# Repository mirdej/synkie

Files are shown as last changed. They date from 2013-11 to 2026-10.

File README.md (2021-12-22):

The Synkie is a modular open source analog video processor, developed by Michael Egger, Max Egger and Flo Kaufmann. A bit like the venerable modular Moog synthesizer it lets you toy around with the signal using patch cables – but this time not producing sound but images. It is an instrument for video, a playground, a platform to explore new ways to transform a video signal. Synkie is still in development, we constantly develop new modules – and even the base specifications may still change over time. 

Synkie’s main goal is playability not image quality, even though we try to design each module as best as we can. But patching is done with 2mm laboratory cables – not shielded 75Ohm BNC cables as one would normally use for video. No, you can even use any blank wire and tinker around with the signal in real time on the sk90-breadboard module… The laboratory plugs can be stacked, so you can easily divide the signal into multiple paths, feeding multiple modules at once and change the configuration on the fly. The resulting image can get quite messy down the road, but that’s part of the fun, or maybe even the main purpose…

# Before building stuff from here yourself - read this:

This Github repository is our working space and not a DIY tutorial. Lots of stuff is completely outdated and/or poorly documented. Here are some important notes about the current state of things (Oct 2021):

- Pretty much everything in the EAGLE directory is totally obsolete and we only keep it for documentation.

- We settled on the LMH6643 as our Opamp of choice for almost everything where frequency response matters. Not all schematics reflect this. In most cases if there's an opamp named "generic opamp" or even "LM833" - we probably meant LMH6643.

- There are several modules where the supply connector is flipped. As we etch a lot of boards ourselves there is no silkscreen and we don't see the error. ALWAYS check the polarity !

- We live in PAL land. These modules have not beent tested with NTSC video. Some might need to be adapted slightly, some might even work better than here ;-)

If you have any questions contact <info@synkie.net>

# Basics

## Synkie Backbone
Modules sk000 to sk009 constitute the Synkie Backbone – handling Ins out Outs to the normal Video World. Input video is clamped (black level = GND) and stripped of timing signals and color burst. This signal can then be fed to any processing modules.
In the end , timing signals and a phase corrected color burst is cut back into the modified signal, in sync with the Genlock input.

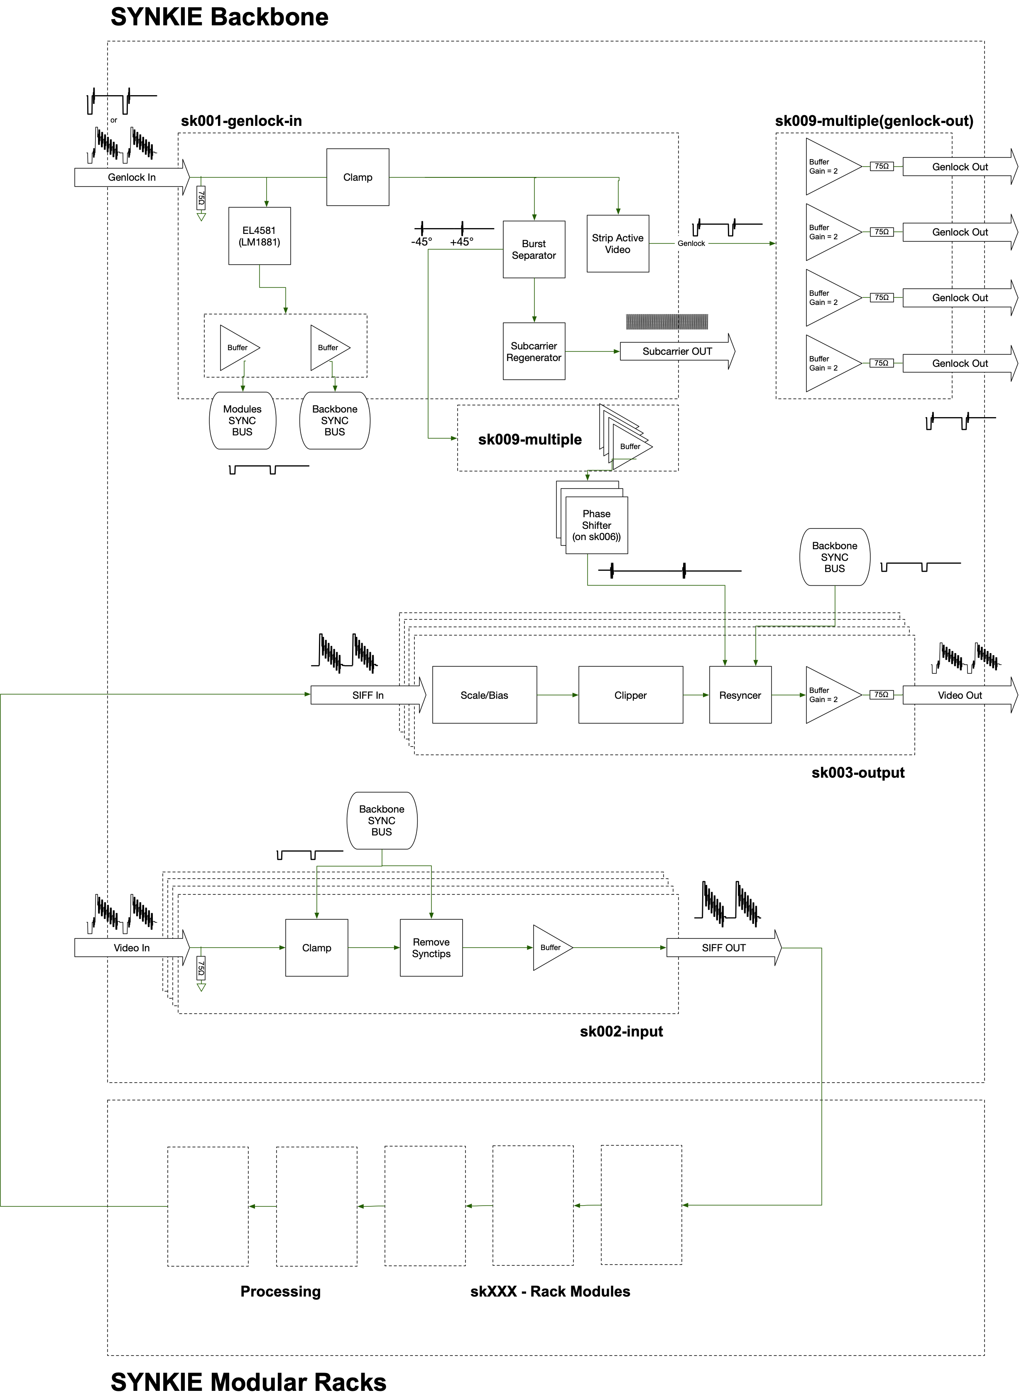
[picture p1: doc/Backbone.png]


### sk000-power
Power distribution to backbone modules and rack. +5V, GND, -5V.

### sk001-genlock-in

This module takes any standard video signal as input and generates all necessary timing signals for the Synkie system. The input is first backporch-clamped to GND and all active video is cut off. This black image can serve as a genlock for connected sources (cameras). Colorburst is output as a seperate signal and used to syncronise a quartz crystal that generates a continuous 4.4336Mhz subcarrier signal for the rgb modules. A LM1881 generates the digital sync signals: horizontal sync, vertical sync, backporch and odd/even.

### sk002-input

This modules takes any standard video signal, clamps black level to GND and strips off synctips and colorburst. (still in active debate: me thinks sk002 should apply a gain of 1.43 to bring the 0.7V white level up to 1V)

### sk003-output

This module takes any signal as its input (from DC to 10Mhz). The scale-bias section controls amplitude and dc-shift. The signal is then clipped hard between 0V and 1V. Finally the resyncer adds synctips and colorburst to make it look like a standard video signal. 
When using video as an input to the sk003 any processing beforehand can add some tiny delay - depending on how many modules the signal passes through -  which causes a phase shift in the signal that can alter or completely destroy color. That is why the burst signal from sk001 first goes through a sk004-burstshift (allpass filter) that lets correct the phase error before it gets cut back into the video signal.

## Synkie Signals

### Terminology
| Signal name | Waveform| Description  |Specs|
|---|---|---|---|
|Genlock||A video signal that serves as the master synchronisation signal. Can be routed through and used as an input.|-0.3V to 0.7V|
|Video||Standard PAL video signal|-0.3V to 0.7V|
|Sync| |Digital sync pulses: H-Sync, V-Sync, Backporch, Odd/Even|0V to 5V|
|Burst|| Colorburst only, AC coupled|ca. -0.1V to 0.1V|
|Siff| |Synkie signal. Can be anything, DC, CV, Audio or Video. 0V means black. 1V means white|-1V to 1V|

### The SIFF signal
Synkie's goal is to be able to mix all signals, be it control signals, audio or picture. You should be able to use a video image as control voltage for a VCO like you should be able to inject a sound into the video or watch a steady 0.256 volts.

* Siff signals are DC coupled. 0V means black. 1V means white.
* Siff signals can still be negative, meaning superblack or substracting signals !
* Siff signals can be loud - going beyond 1V and below -1V. The sk003-output module will finally limit the signal to 0-1V.
* Siff signals can range from DC (0Hz) to ca. 10Mhz

This has the following implications for synkie modules:

* All module inputs should be high-impedance, DC coupled and ESR protected.
* All module outputs should be low-impedance and DC coupled.
* Whenever possible a module's bandwidth should be at least 4Mhz
* Sensible CV range should be between 0V and 1V.
* But: Modules must be able to cope with voltages as low as -5V to as high as 5V
* Gate signals are 0V to 1V !!
* So: trigger inputs should trigger at around 0.5V ! Use comparators.

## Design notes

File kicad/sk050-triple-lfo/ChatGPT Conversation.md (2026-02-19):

From the schematic, R5 + RV1 feed an inverting integrator (U1B) with C4, and U1A acts as the Schmitt trigger. For this topology the oscillation frequency is well-approximated by:

[
f \approx \frac{R3}{4,R4,(R5+RV),C4}
]

With your shown values R3 = 100k and R4 = 10k, that simplifies to:

[
f \approx \frac{2.5}{(R5+RV),C4}
]

Assuming RV1 is used as a rheostat (wiper tied to an end, as drawn), with RV = 0…100kΩ:

[
f_{\max} \approx \frac{2.5}{R5,C4}
]
[
f_{\min} \approx \frac{2.5}{(R5+100k),C4}
]
Frequency ranges for common R5/C4 choices
R5 (Ω)	C4	f_max (Hz) @ RV=0	f_min (Hz) @ RV=100k
4.7k	100 nF	5,319	239
10k	100 nF	2,500	227
22k	100 nF	1,136	192
47k	100 nF	532	170
4.7k	1 µF	532	23.9
10k	1 µF	250	22.7
22k	1 µF	114	19.2
47k	1 µF	53.2	17.0
4.7k	10 µF	53.2	2.39
10k	10 µF	25.0	2.27
22k	10 µF	11.4	1.92
47k	47 µF	1.13	0.362
100k	47 µF	0.532	0.266
47k	100 µF	0.532	0.170
If you want, say, a “typical LFO” band (e.g. ~0.05–20 Hz) tell me that target range and I’ll suggest a small set of R5/C4 combos that land there cleanly with the 0–100k pot.

------------------------------------------------------------------------------------------------------

For your exact schematic (U1A Schmitt + U1B integrator), with R3 = 100k and R4 = 10k, the oscillation frequency is approximately:

[
f \approx \frac{2.5}{(R5+RV),C4}
]

with RV = 0…100kΩ (wired as a rheostat). So:

(f_{\max} \approx \dfrac{2.5}{R5,C4})
(f_{\min} \approx \dfrac{2.5}{(R5+100k),C4})
Below are common-value combinations that target your two “interesting” overall bands. Since one 0–100k pot only gives about a (R5+100k)/R5 span, hitting 0.05→20 Hz and 0.1→100 Hz realistically means switching C4 (and/or R5).

Set A (recommended): keep R5 = 22k, switch C4 to cover ~0.09 Hz → 114 Hz overall
This is a nice “do-most-things” choice.

R5	C4	f_max (Hz) @ RV=0	f_min (Hz) @ RV=100k
22k	1 µF	113.6	20.5
22k	2.2 µF	51.6	9.32
22k	4.7 µF	24.2	4.36
22k	10 µF	11.36	2.05
22k	22 µF	5.16	0.931
22k	47 µF	2.42	0.436
22k	100 µF	1.136	0.205
22k	220 µF	0.516	0.093
What this gives you:

For ~0.1–100 Hz overall: C4 from 1 µF down to 220 µF covers it (with overlaps).
For ~0.05–20 Hz overall: you’ll use mostly 4.7 µF … 470 µF (next table includes 470 µF).
Add one more common value if you want to reach ~0.05 Hz comfortably:

R5	C4	f_max (Hz) @ RV=0	f_min (Hz) @ RV=100k
22k	470 µF	0.242	0.0436
Set B (more “LFO-biased”): keep R5 = 47k, switch C4 for lower frequencies
This shifts everything slower (often useful if you mainly care about sub-Hz).

R5	C4	f_max (Hz) @ RV=0	f_min (Hz) @ RV=100k
47k	2.2 µF	24.2	7.74
47k	4.7 µF	11.31	3.62
47k	10 µF	5.32	1.70
47k	22 µF	2.42	0.774
47k	47 µF	1.13	0.362
47k	100 µF	0.532	0.170
47k	220 µF	0.242	0.0774
47k	470 µF	0.113	0.0362
Practical notes (affects “how true” the low end is)
Electrolytics (100–470 µF) have wide tolerance + leakage → the very lowest frequencies can drift.
Op-amp input bias/leakage and capacitor leakage matter a lot below ~0.1 Hz.

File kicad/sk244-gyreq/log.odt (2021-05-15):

Main amp R 10k

# Mid

10n ; 1n / 100 / 100k

min:

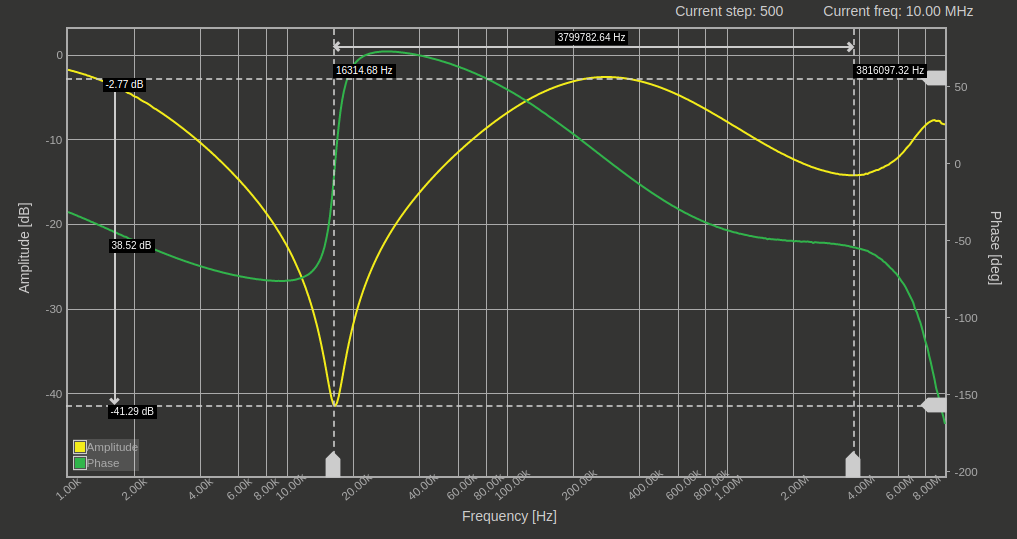
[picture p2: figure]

zero:

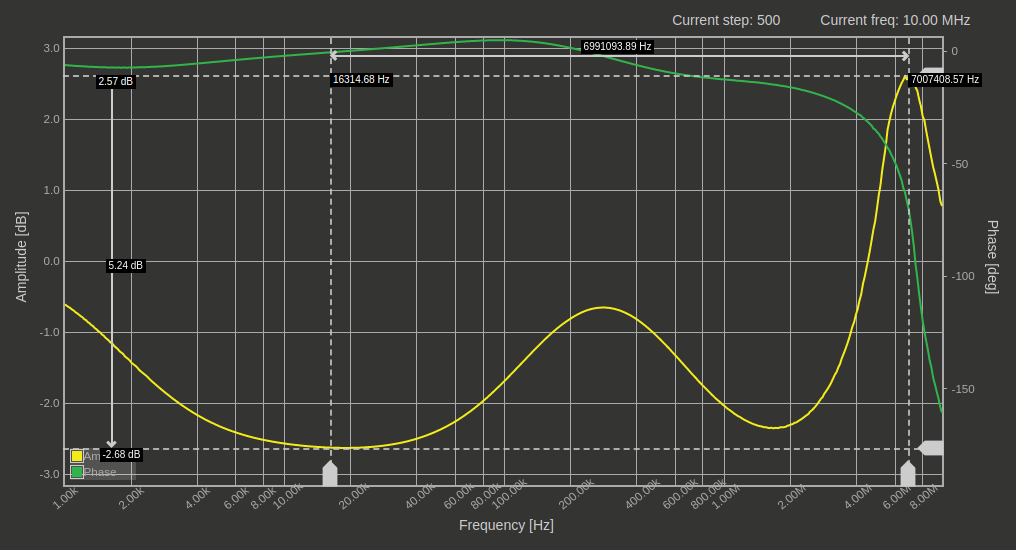
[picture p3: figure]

max:

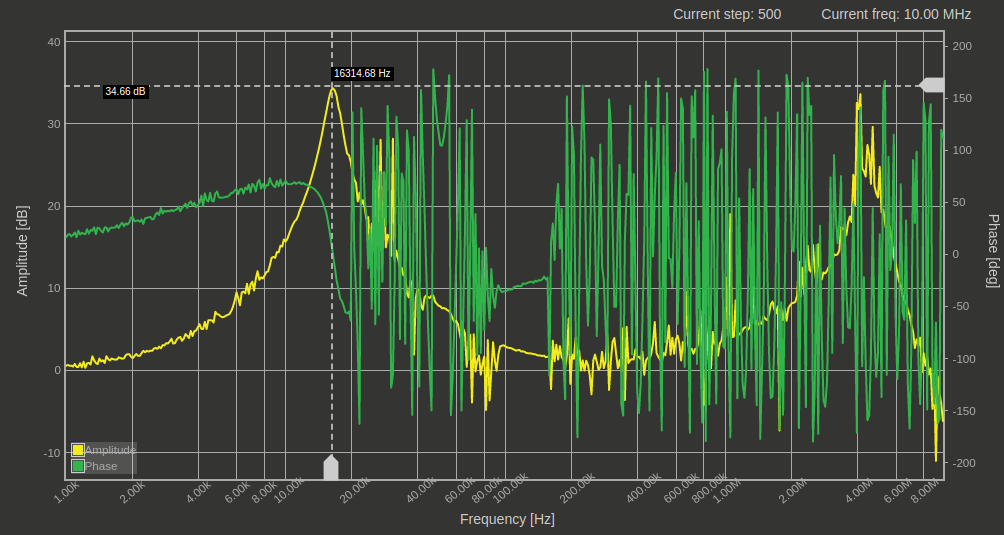
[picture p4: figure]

# Hi (Mid zero)

22p ; 47p / 75 / 16k

min:

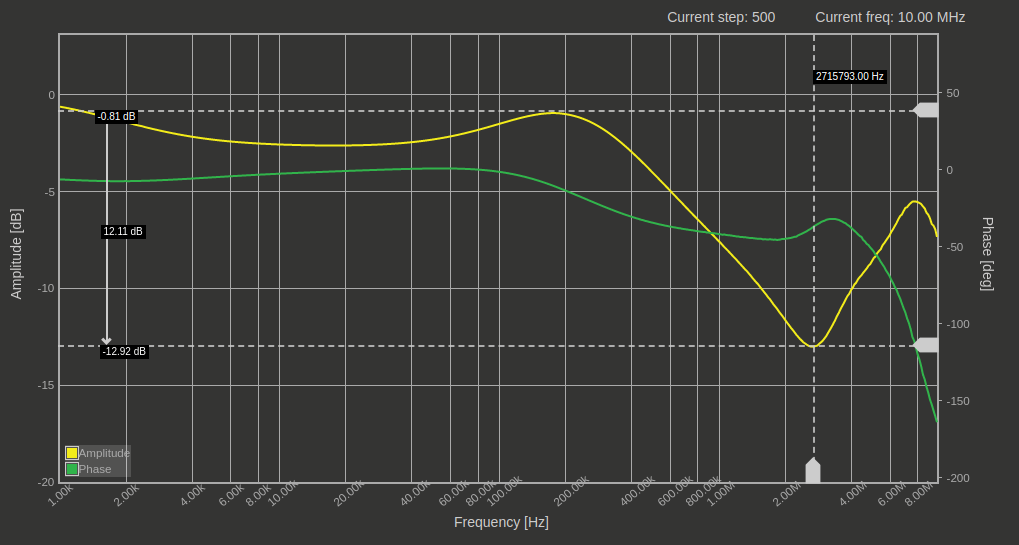
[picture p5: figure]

zero:

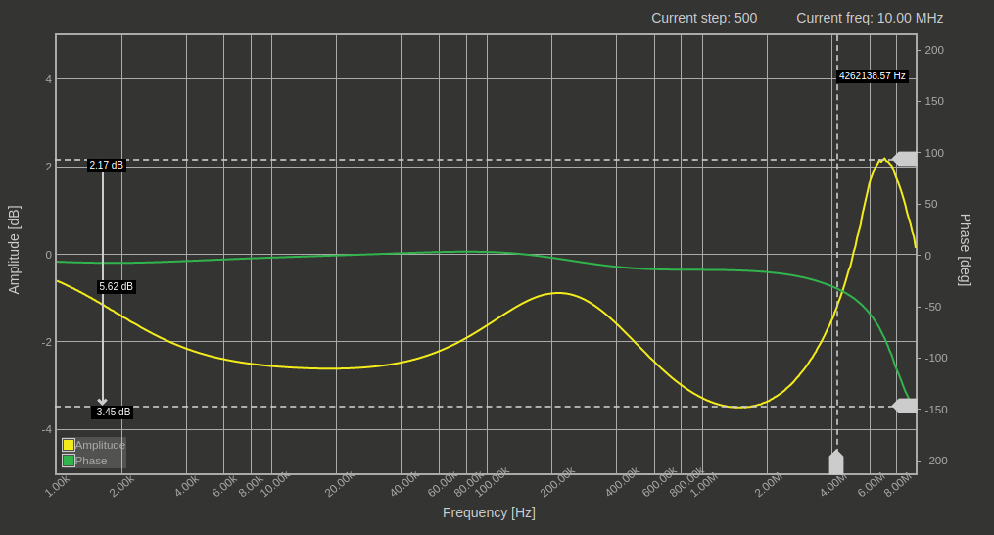
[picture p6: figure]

max

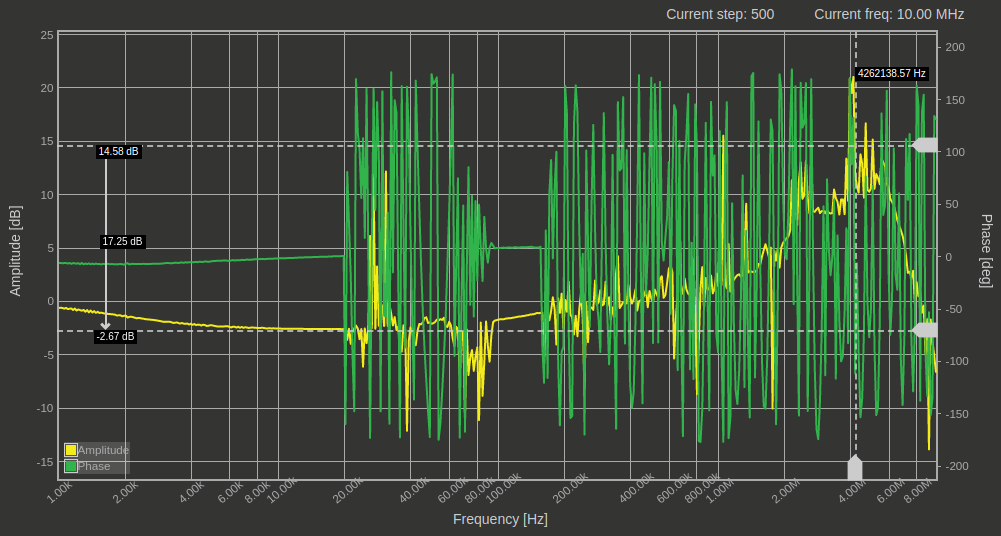
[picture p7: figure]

# Low

1u ; 100n / 100 / 1M

min:

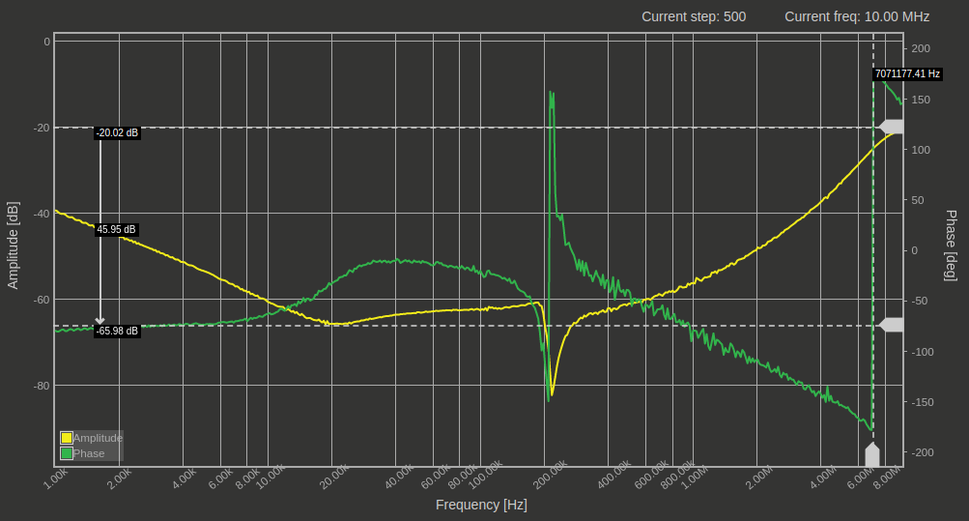
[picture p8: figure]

zero:

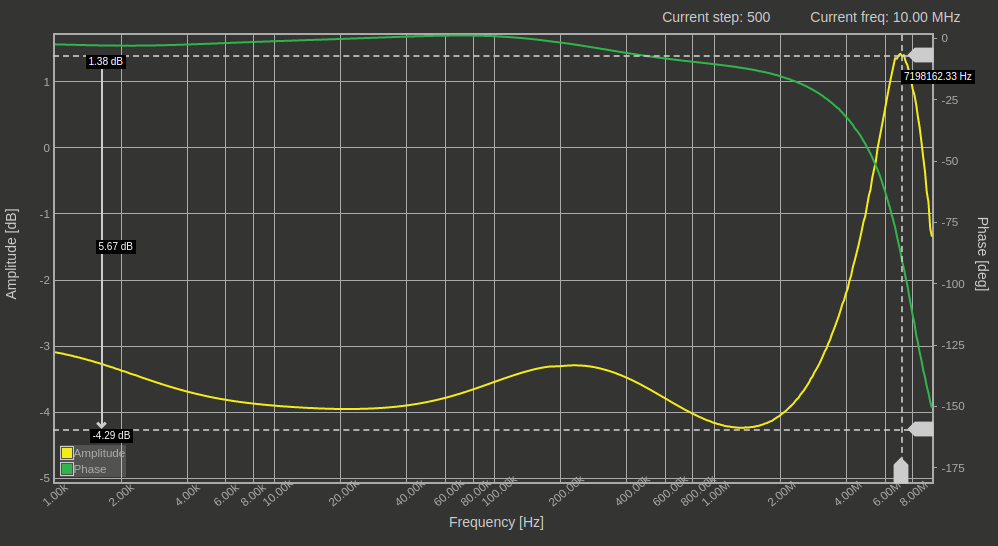
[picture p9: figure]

max:

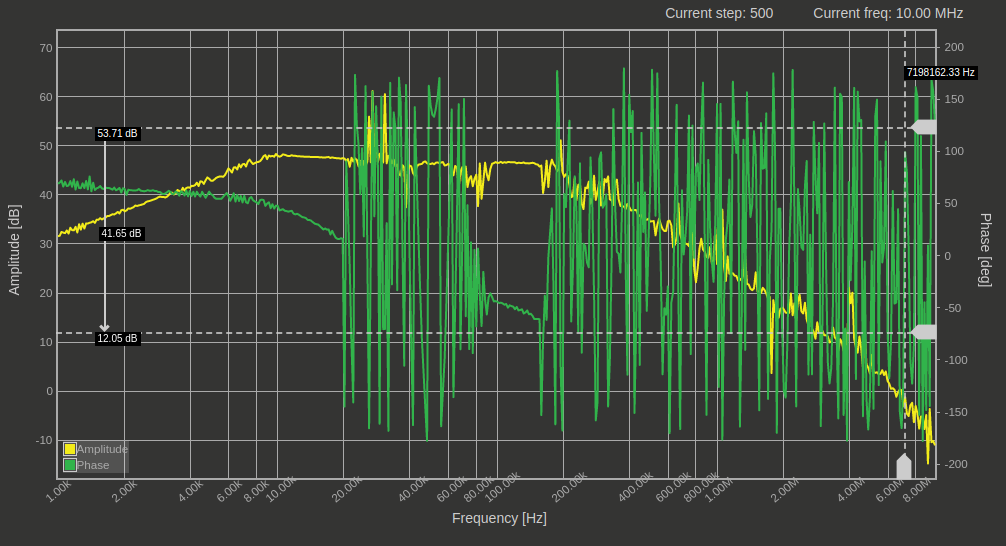
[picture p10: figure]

(amplitude clipped)

# 2. Hi (Mid zero)

## 47p ; 22p / 75 / 16k

min:

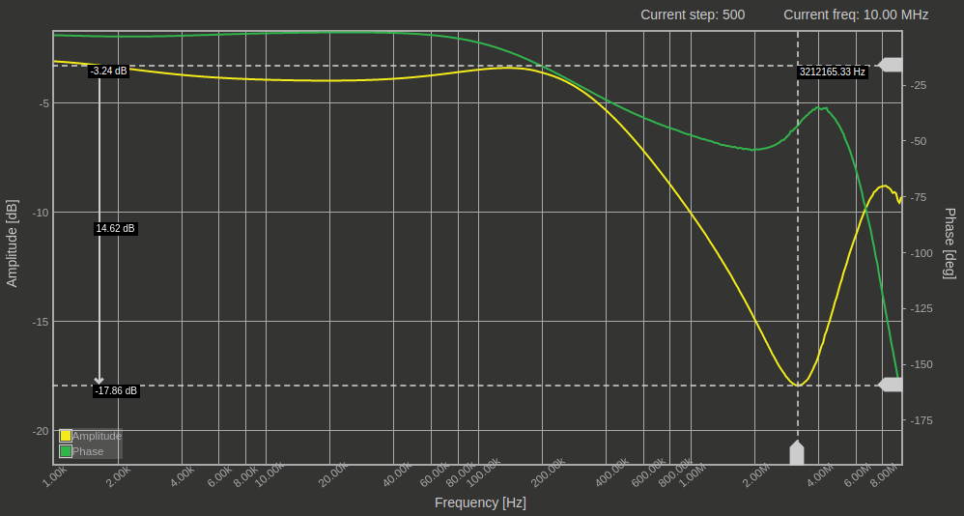
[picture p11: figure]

zero:

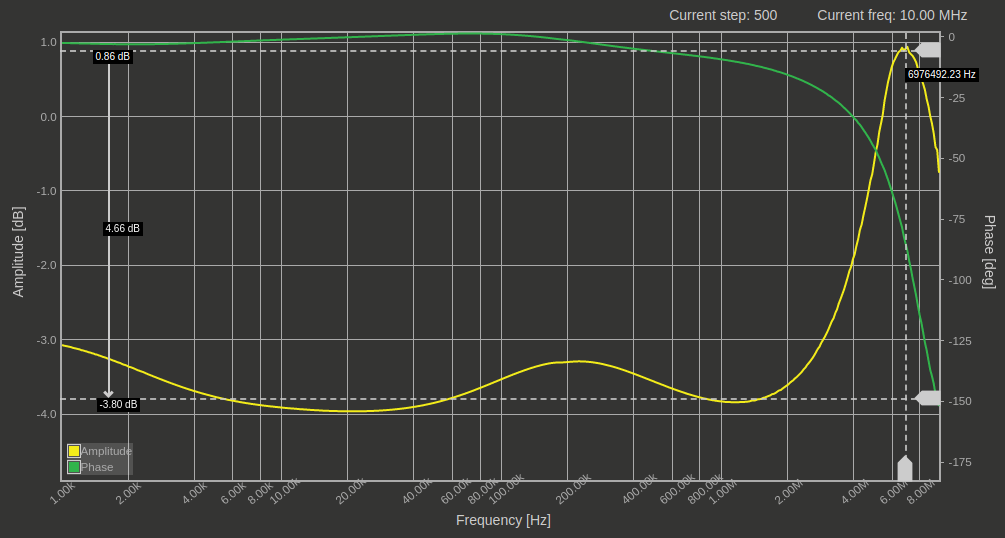
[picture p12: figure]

max:

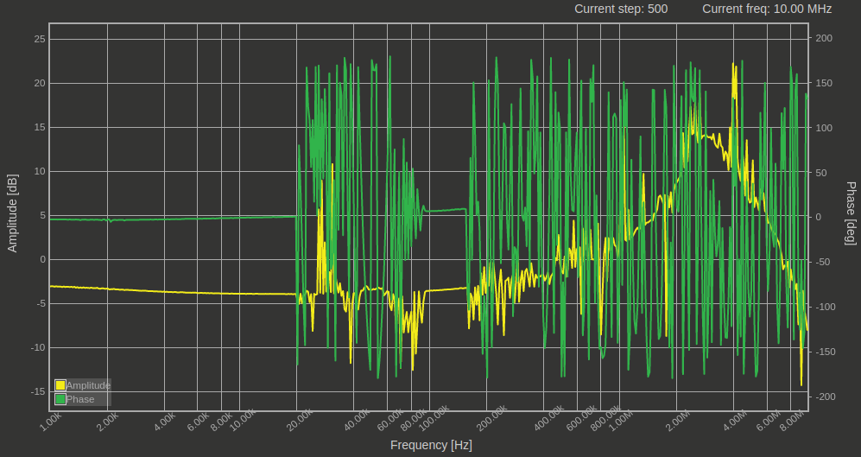
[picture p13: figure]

## 47p ; 10p / 75 / 16k

min:

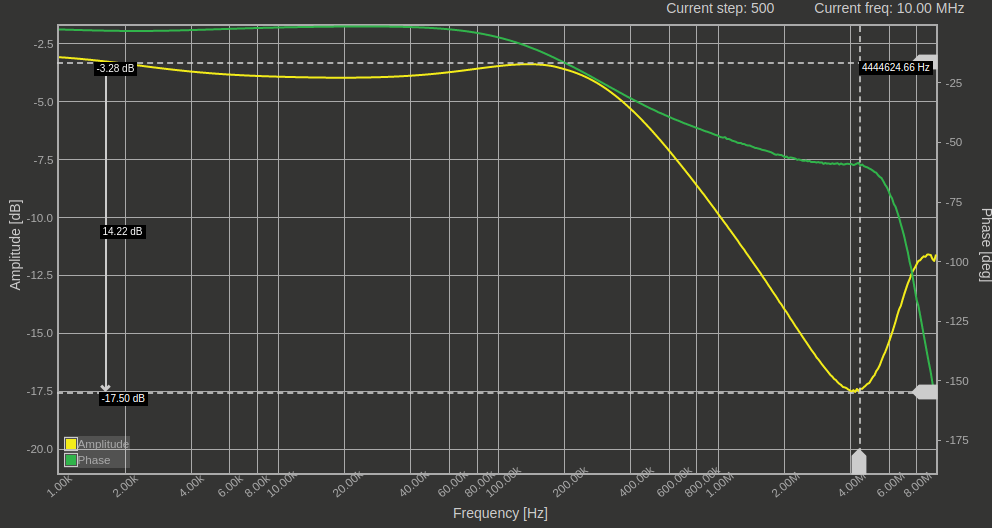
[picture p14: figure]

max:

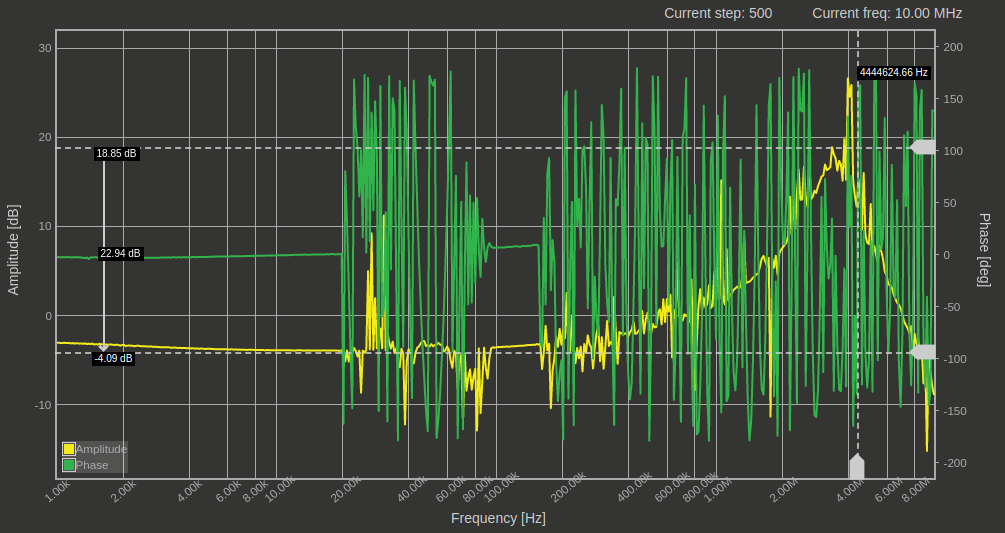
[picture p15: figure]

## 22p ; 10p / 75 / 16k

min:

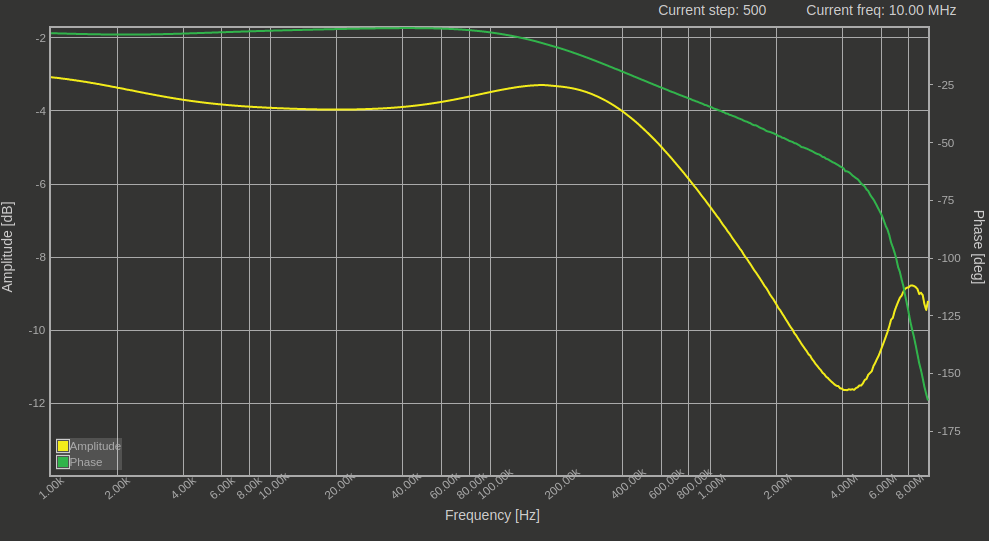
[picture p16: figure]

## 22p ; 10p / 75 / 51k

Min:

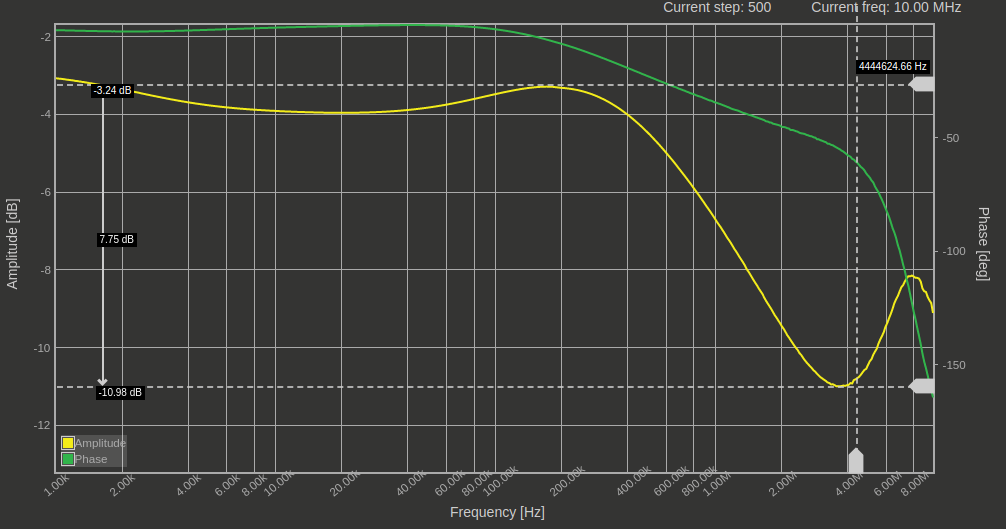
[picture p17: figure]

## 22p ; 10p / 220 / 16k

Min

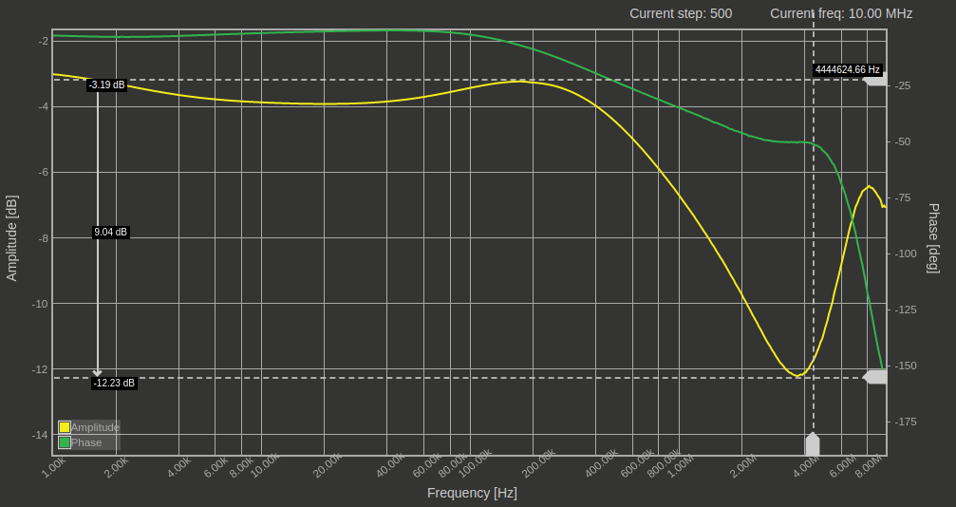
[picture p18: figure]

## 10p ; 10p / 220 / 16k

Min

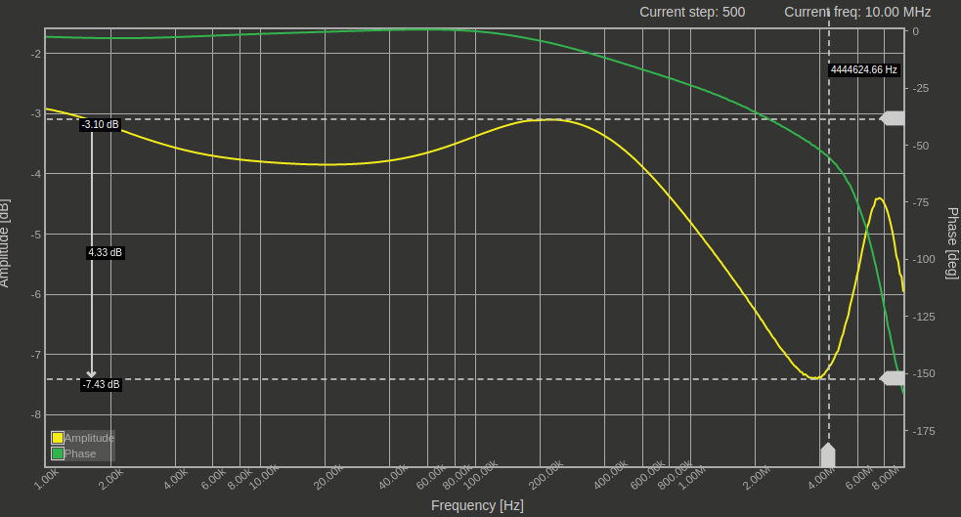
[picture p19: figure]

## 10p ; 10p / 220 / 51k

Min

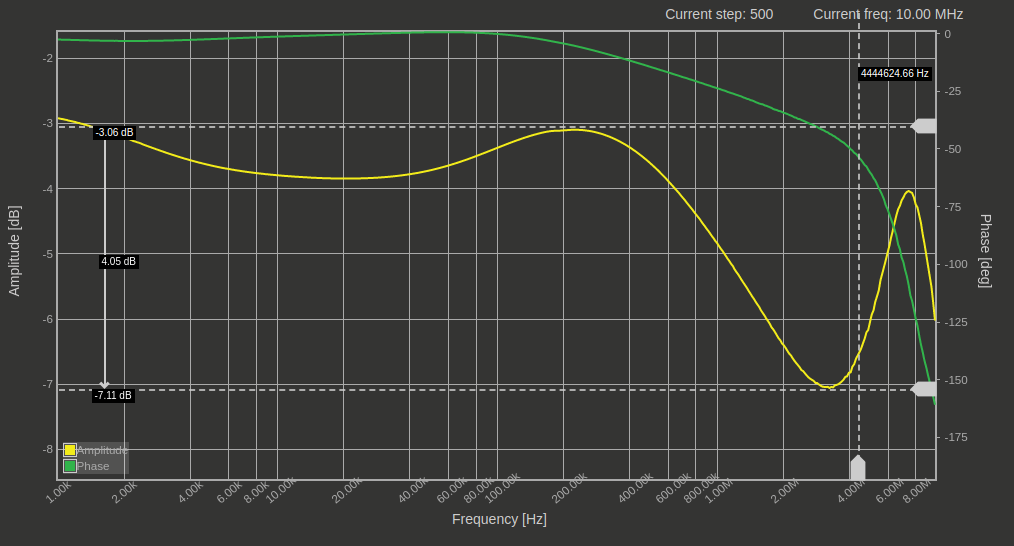
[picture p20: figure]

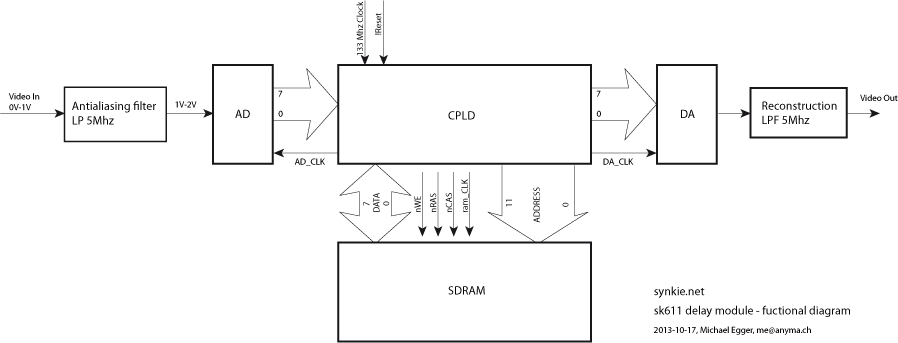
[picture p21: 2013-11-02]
eagle/sk610-delay/sk610-schematic.gif

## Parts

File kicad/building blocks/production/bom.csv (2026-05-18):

Designator | Footprint | Quantity | Value | LCSC Part #
C1 | 0805 | 1 | C-Trig
C10, C11, C12, C13, C23, C24, C29, C3, C30, C32, C33, C4, C5, C6, C7, C8 | 0603 | 16 | 100n | C14663
C14, C15, C18, C19 | 0603 | 4 | 10p | C1634
C16, C17, C20, C21 | 0402 | 4 | 100n | C1525
C2, C9 | 0805 | 2 | 10u | C15850
C22 | CP_EIA-3216-18_Kemet-A | 1 | 10uTantal | C7171
D1, D2, D4, D6, D7, D8 | SOT-23 | 6 | BAT54S | C8592
D3, D9 | D_SOD-323 | 2 | 1N5819WS | C191023
D5 | 1206 | 1 | LED | C125108
FB1, FB2, FB3, FB4 | 0805 | 4 | Ferrite_Bead | C1017
J1, J3 | TestPoint_THTPad_D4.0mm_Drill2.0mm | 2 | Gate In
J10 | Molex_KK-254_AE-6410-04A_1x04_P2.54mm_Vertical | 1 | sync
J11, J12, J13, J14, J15, J16, J17, J18, J6 | Molex_PicoBlade_53398-0371_1x03-1MP_P1.25mm_Vertical | 9 | Power | C293633
J19, J20, J21, J23, J27, J30, J31 | TE_UMCC_2337019-1 | 7 | Coax | C5137195
J2 | TestPoint_THTPad_D4.0mm_Drill2.0mm | 1 | Trigger In
J22, J28, J29, J32 | TestPoint_THTPad_D4.0mm_Drill2.0mm | 4 | Banana
J24, J25, J26, J34, J35 | TestPoint_THTPad_D4.0mm_Drill2.0mm | 5 | Input
J33, J4 | Molex_KK-254_AE-6410-03A_1x03_P2.54mm_Vertical | 2 | Power
J5, J7 | TestPoint_THTPad_D4.0mm_Drill2.0mm | 2 | Out
J8 | IDC-Header_2x08_P2.54mm_Vertical | 1 | Conn_01x16
JP1 | SolderJumper-2_P1.3mm_Bridged2Bar_RoundedPad1.0x1.5mm | 1 | Jumper_2_Bridged
Q3 | SOT-23 | 1 | MMBT2222A | C8512
R1, R10, R15, R17, R22, R25, R29, R41, R48, R7, R8 | 0603 | 11 | 47k | C25819
R11, R12 | 0603 | 2 | 1k | C21190
R13, R14, R18, R19, R23, R24, R26, R27, R28, R30, R31, R32, R42, R43, R49, R5, R50, R9 | 0603 | 18 | 75 | C4275
R16, R46, R6 | 0603 | 3 | 4k7 | C23162
R2, R47 | 0603 | 2 | 12k | C22790
R20, R21, R4 | 0603 | 3 | 2k2 | C4190
R3 | 0603 | 1 | 3k3 | C22978
R33, R34, R35, R36, R37, R38, R39, R40 | 0603 | 8 | 300 | C23025
R44, R45 | 0603 | 2 | 6k8 | C23212
RV1, RV2 | PRS12R-2 | 2 | ~
TP1, TP2 | TestPoint_THTPad_D4.0mm_Drill2.0mm | 2 | Vref
TP10, TP11, TP15, TP18, TP9 | TestPoint_THTPad_D4.0mm_Drill2.0mm | 5 | TP
TP12, TP14, TP17, TP7 | TestPoint_THTPad_D4.0mm_Drill2.0mm | 4 | In1
TP13, TP8 | TestPoint_THTPad_D4.0mm_Drill2.0mm | 2 | In2
TP16 | TestPoint_Pad_2.0x2.0mm | 1 | TestPoint
TP3 | TestPoint_THTPad_D4.0mm_Drill2.0mm | 1 | Comp1Out
TP4, TP5 | TestPoint_THTPad_D4.0mm_Drill2.0mm | 2 | Comp2Out
TP6 | TestPoint_THTPad_D4.0mm_Drill2.0mm | 1 | Led
U1, U11 | SOIC-8_3.9x4.9mm_P1.27mm | 2 | LM393 | C7955
U10 | SOIC-16_3.9x9.9mm_P1.27mm | 1 | TPW4053-SR | C7500846
U2 | SOT-23-5 | 1 | TLV3201 | C105188
U3, U6, U8, U9 | SOIC-8_3.9x4.9mm_P1.27mm | 4 | NE5532 | C7426
U4, U5 | SOT-23 | 2 | CJ | C3113
U7 | VSSOP-8_3x3mm_P0.65mm | 1 | LMH6643 | C478382

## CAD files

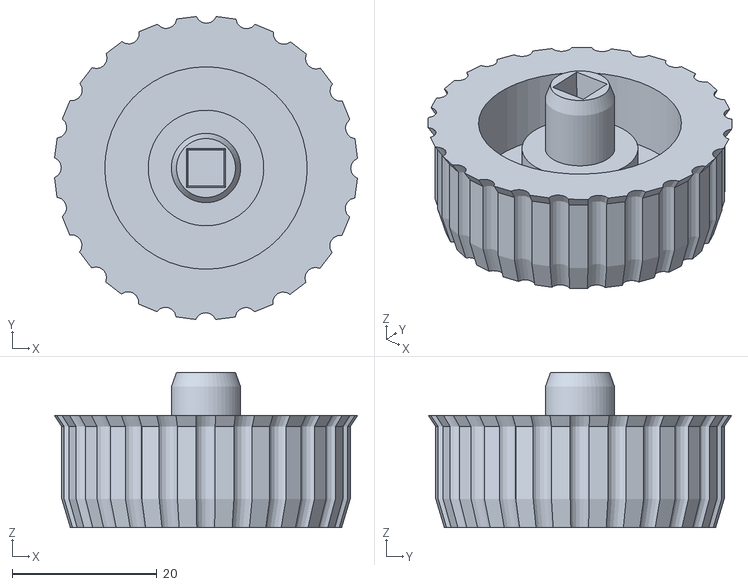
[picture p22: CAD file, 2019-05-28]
kicad/sk950-teensy-osc/magnet-Knobuntitled.stl
41.9 x 41.9 x 21.5

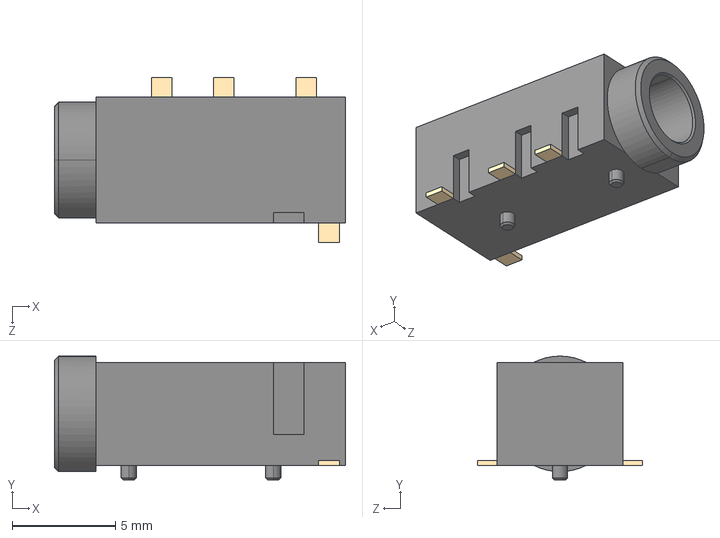
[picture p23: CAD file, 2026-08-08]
kicad/synkie_footprint_models/PJ-320D.step
14.1 x 6.00 x 8.00 mm

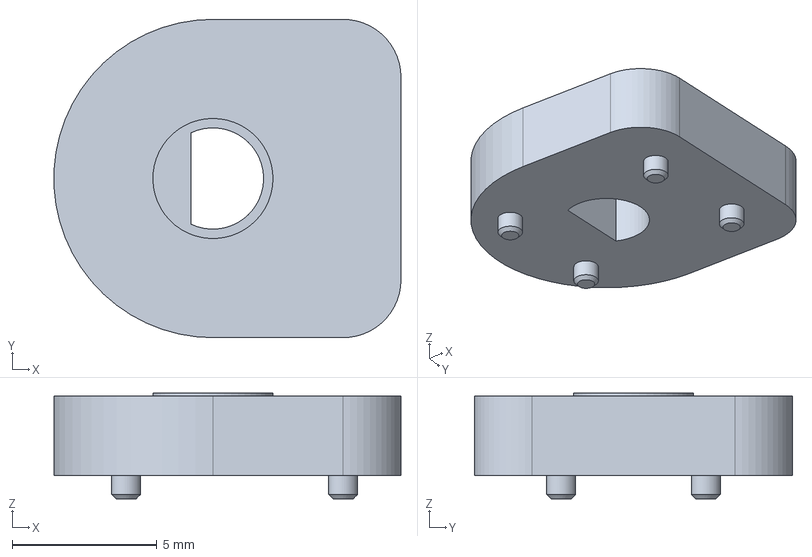
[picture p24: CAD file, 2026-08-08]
kicad/synkie_footprint_models/RDC503.step
12.0 x 11.0 x 3.65 mm
X-axis002 x 3
XY-plane002 x 3

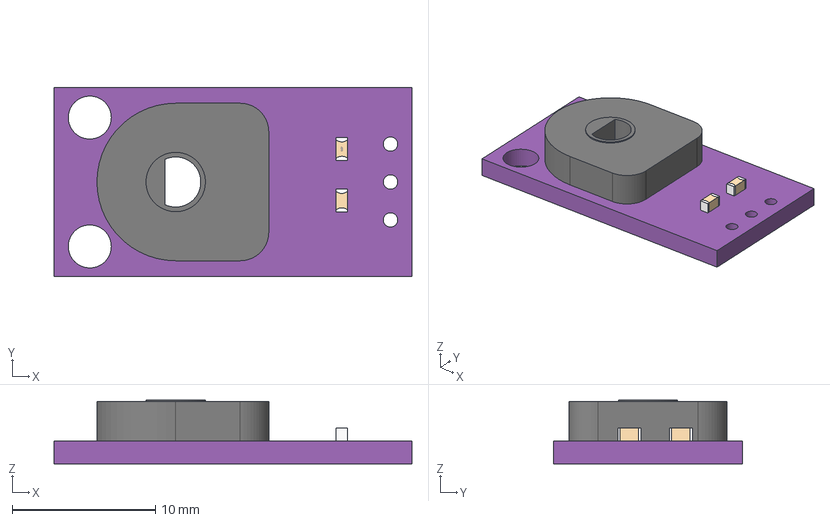
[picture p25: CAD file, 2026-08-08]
kicad/synkie_footprint_models/Rotary sensor-Alps_RDC503_module.step
25.0 x 13.2 x 4.45 mm
C0603 x 2
C0604 x 2
C0605 x 2

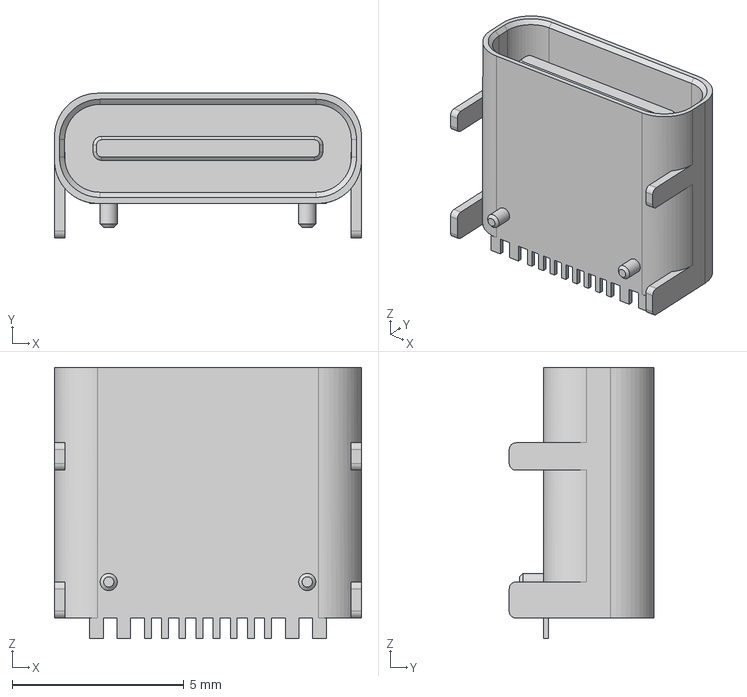
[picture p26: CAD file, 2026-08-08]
kicad/synkie_footprint_models/HRO_TYPE_C_31_M12.STEP
8.94 x 4.21 x 7.90 mm

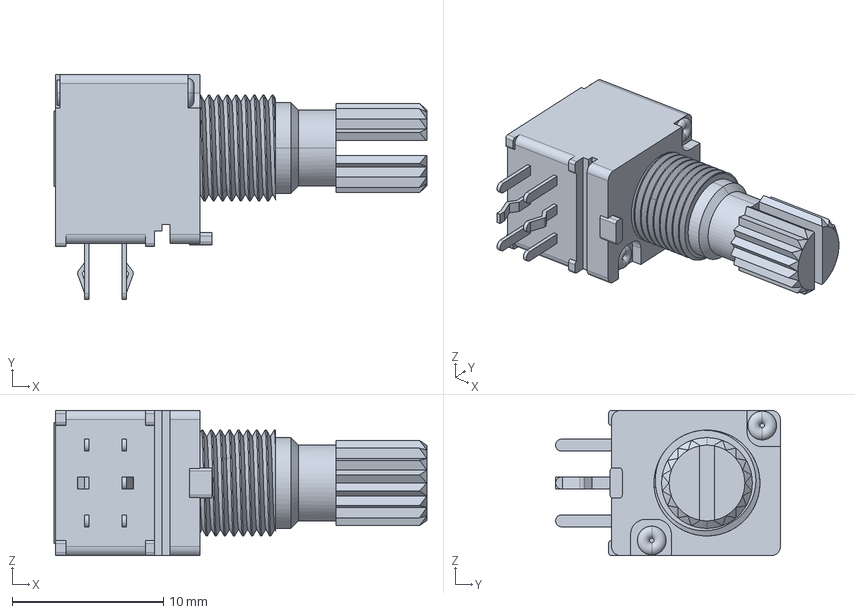
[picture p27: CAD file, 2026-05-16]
kicad/synkie_footprint_models/ptd902-xx15k-xxxx.stp
24.7 x 14.9 x 9.60 mm

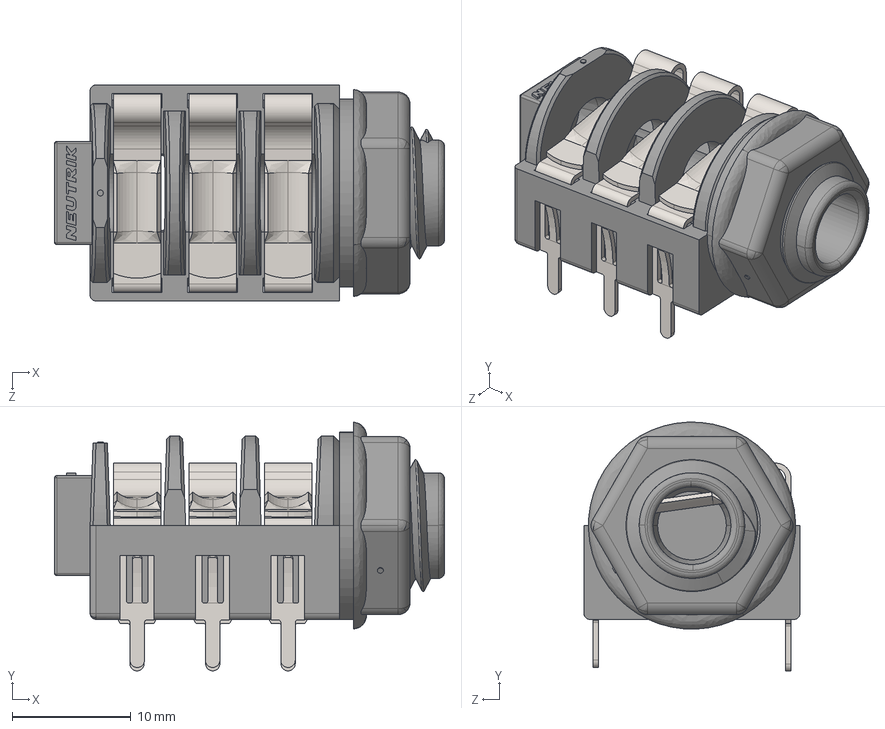
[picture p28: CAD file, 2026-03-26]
kicad/synkie_footprint_models/NMJ6HFD2.stp
32.9 x 21.0 x 18.2 mm
NMJ6HFD2_1
NMJ6HFD2
NMJ6HFD2_2
NMJ6HFD2_3

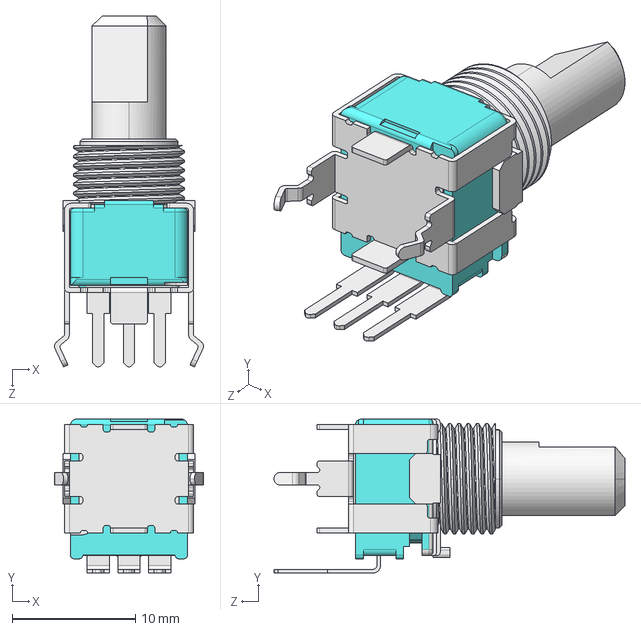
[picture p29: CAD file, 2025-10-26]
kicad/synkie_footprint_models/RK09L114001E.stp
12.1 x 12.5 x 28.5 mm

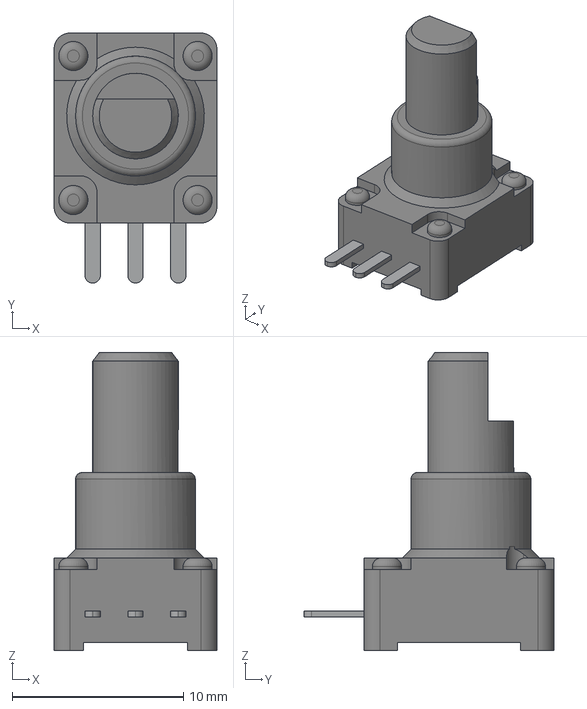
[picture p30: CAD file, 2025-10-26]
kicad/synkie_footprint_models/RK09Y11L0001.stp
9.50 x 14.6 x 17.4 mm

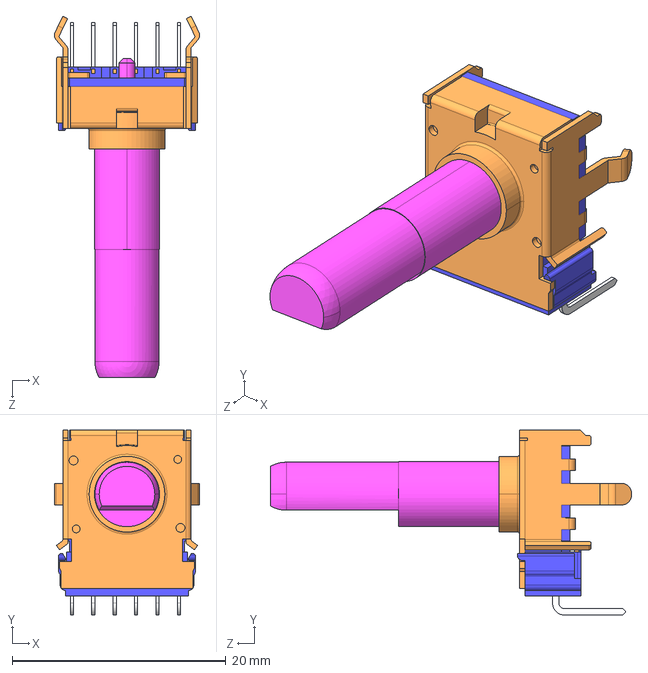
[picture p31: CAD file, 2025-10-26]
kicad/synkie_footprint_models/RK12L12_V30.STEP
13.6 x 17.3 x 33.8 mm

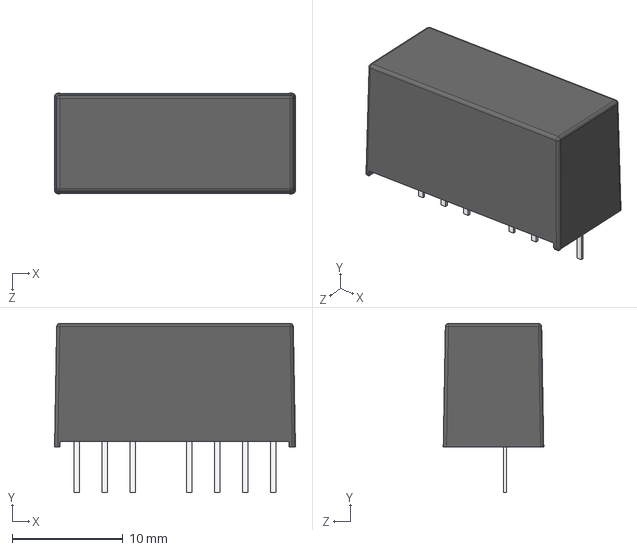
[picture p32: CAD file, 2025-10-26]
kicad/synkie_footprint_models/tec3_3d_drawing.stp
21.8 x 15.3 x 9.10 mm

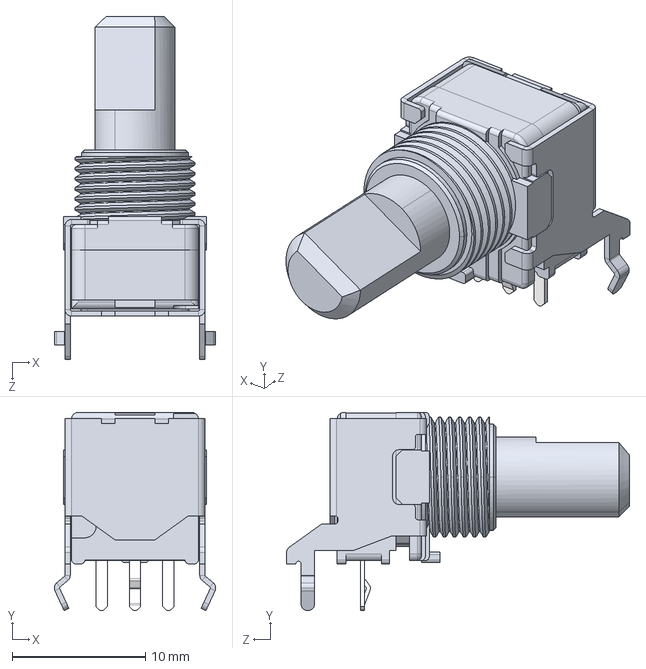
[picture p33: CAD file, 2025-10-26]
kicad/synkie_footprint_models/RK09L112003P.stp
12.1 x 14.9 x 25.7 mm

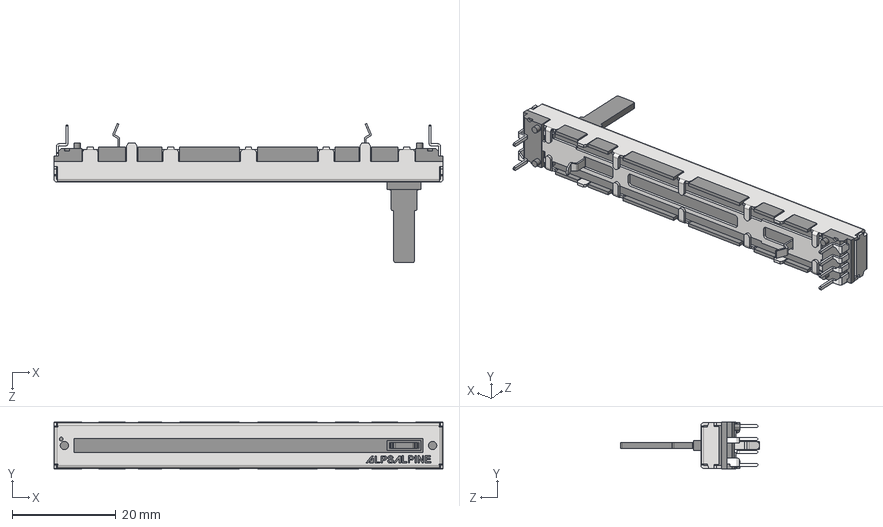
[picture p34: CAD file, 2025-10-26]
kicad/synkie_footprint_models/RS6011SP6003.stp
75.0 x 9.00 x 26.8 mm
slider.step
terminal^ALPS_-_RS6011SP6003.step
shell n^ALPS_-_RS6011SP6003.step
body_n^ALPS_-_RS6011SP6003.step
logo^ALPS_-_RS6011SP6003.step

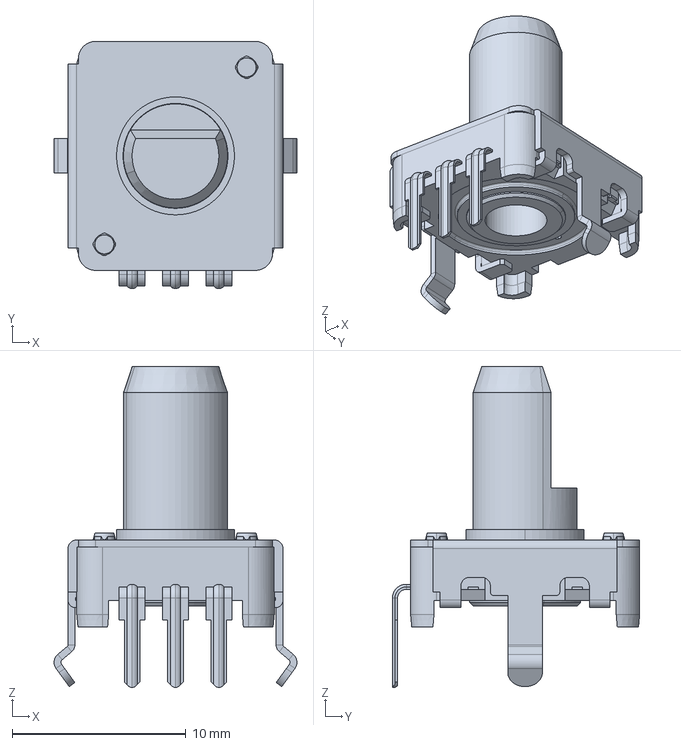
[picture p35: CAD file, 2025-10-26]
kicad/synkie_footprint_models/ec12e1220407.stp
14.0 x 14.2 x 18.5 mm

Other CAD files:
kicad/synkie_footprint_models/first.FCStd
kicad/synkie_footprint_models/PTL20-10G0-103B2.STEP
kicad/synkie_footprint_models/RK09K1130A70.stp
kicad/synkie_footprint_models/SKQGAKE010.stp
kicad/sk000-power/sk000-hole-schablone.skp
kicad/sk950-teensy-osc/magnet-Knob.skp
kicad/sk950-teensy-osc/magnet-Knob~.skp
kicad/synkie_footprint_models/PJ301M-12 Thonkiconn v0.2.stp
sketchup/sk020-monitors.skp
sketchup/sk020-monitors~.skp
sketchup/sk400-lightguide.skp
sketchup/sk400-lightguide~.skp
sketchup/supply-cover.skp
sketchup/synkie-masterbox-scharnier.skp
sketchup/synkie-masterbox-scharnier~.skp
sketchup/synkie-masterbox-screens.skp
sketchup/synkie-masterbox-screens~.skp
sketchup/synkie-masterbox2.5-10mm.skp
sketchup/synkie-tourbox2.5-10mm.skp
sketchup/synkie-tourbox2021.1.skp
sketchup/synkie-tourbox2021.1~.skp
sketchup/synkie-tourbox2021~.skp

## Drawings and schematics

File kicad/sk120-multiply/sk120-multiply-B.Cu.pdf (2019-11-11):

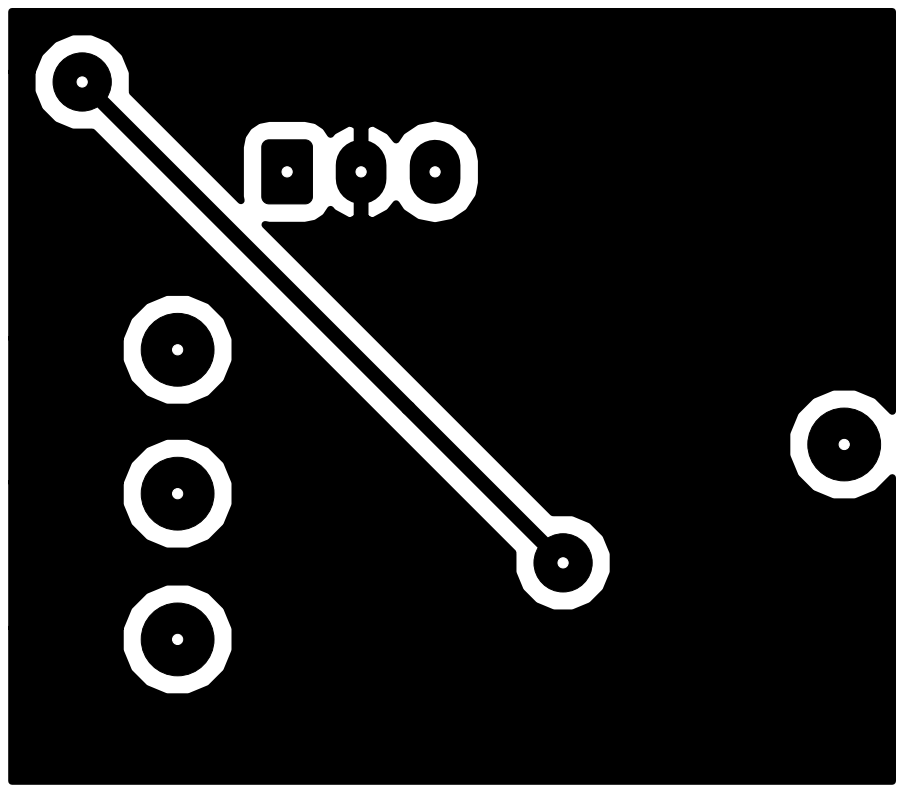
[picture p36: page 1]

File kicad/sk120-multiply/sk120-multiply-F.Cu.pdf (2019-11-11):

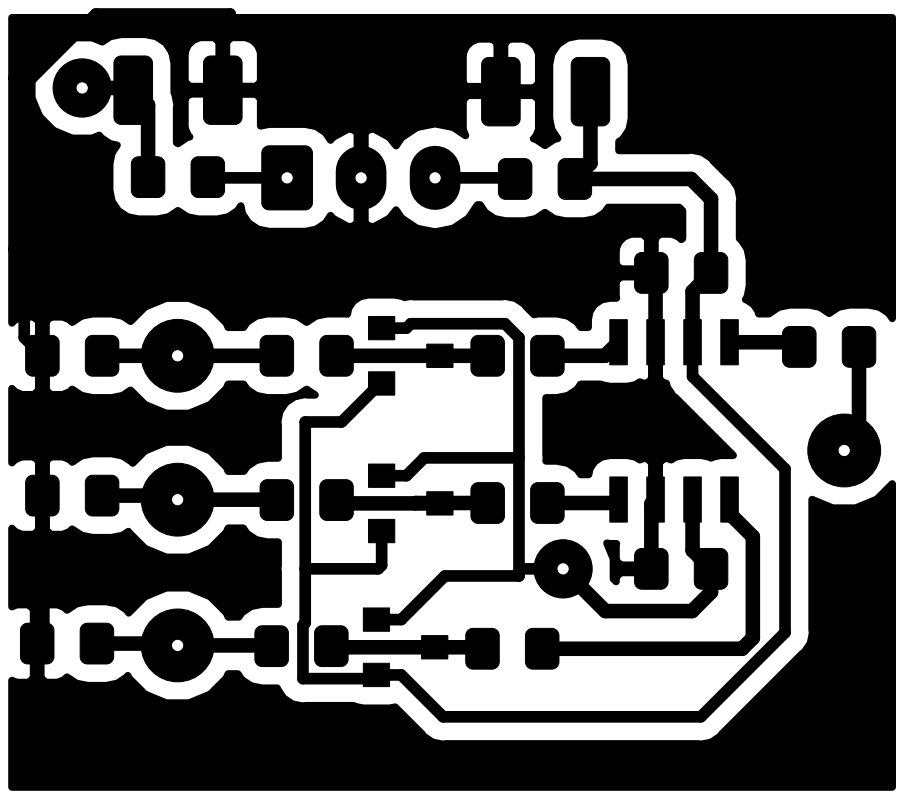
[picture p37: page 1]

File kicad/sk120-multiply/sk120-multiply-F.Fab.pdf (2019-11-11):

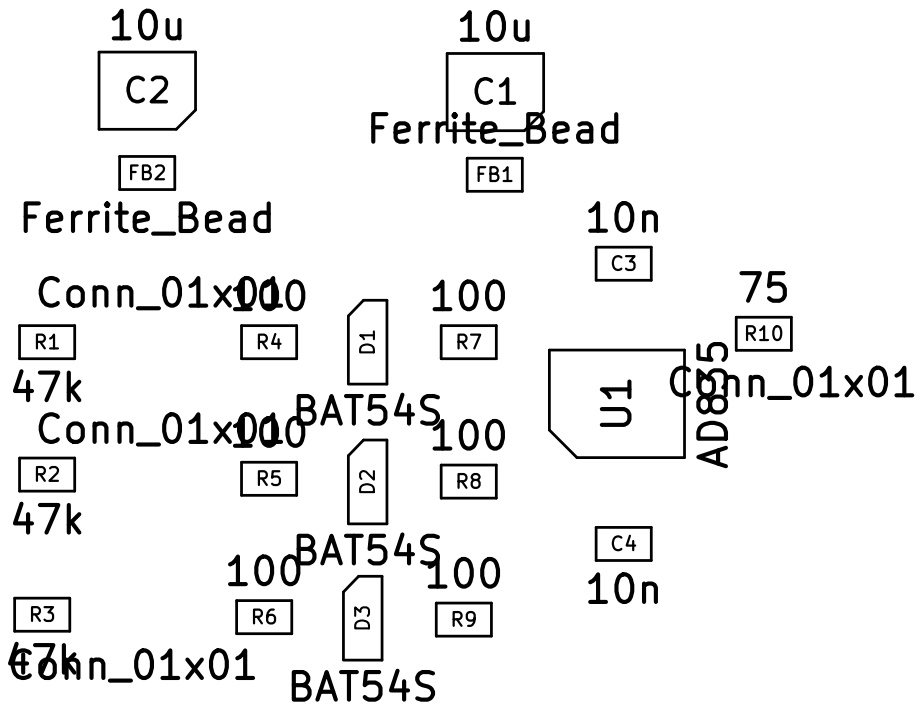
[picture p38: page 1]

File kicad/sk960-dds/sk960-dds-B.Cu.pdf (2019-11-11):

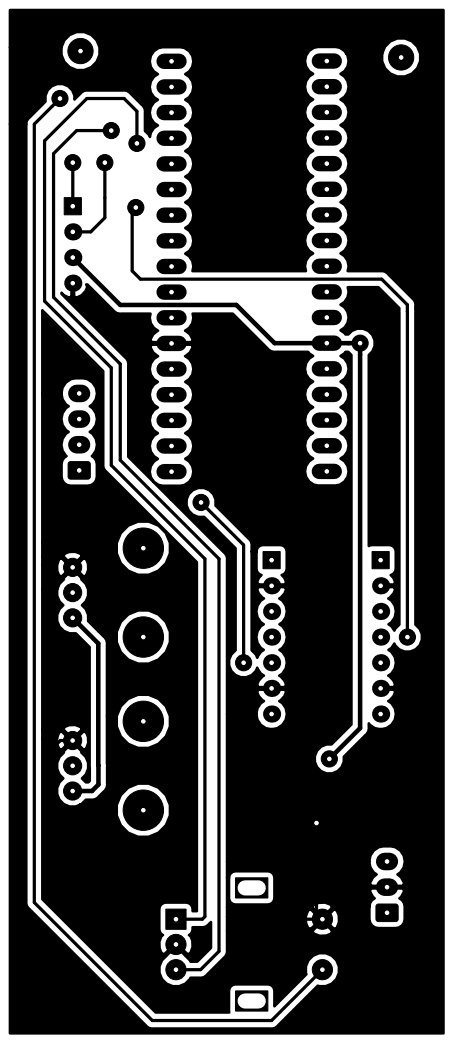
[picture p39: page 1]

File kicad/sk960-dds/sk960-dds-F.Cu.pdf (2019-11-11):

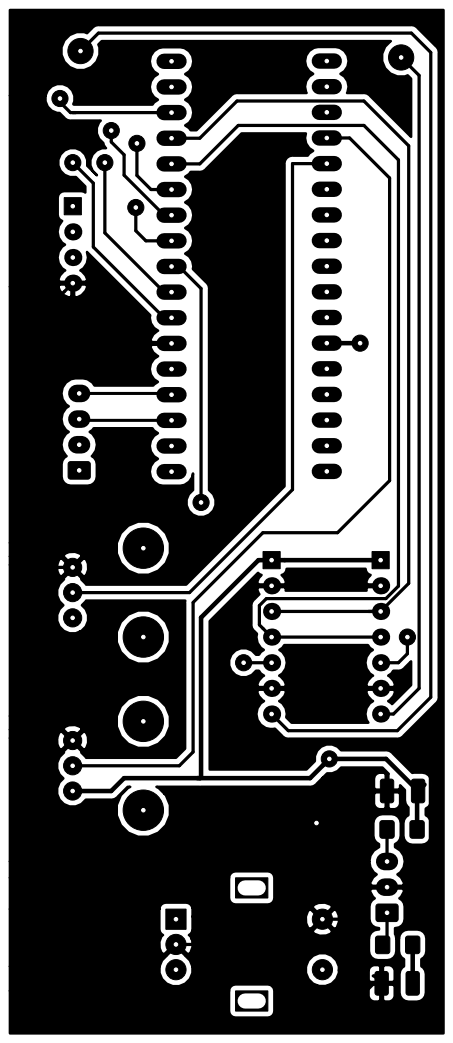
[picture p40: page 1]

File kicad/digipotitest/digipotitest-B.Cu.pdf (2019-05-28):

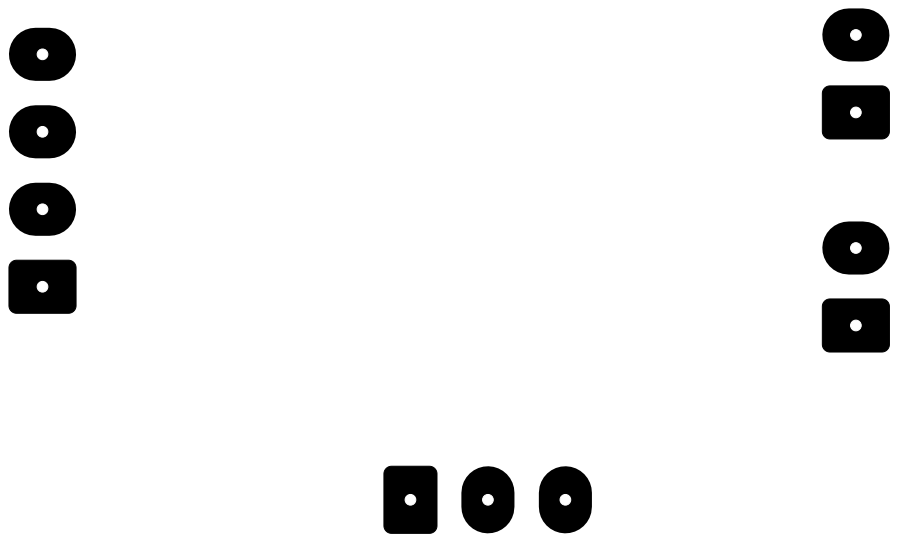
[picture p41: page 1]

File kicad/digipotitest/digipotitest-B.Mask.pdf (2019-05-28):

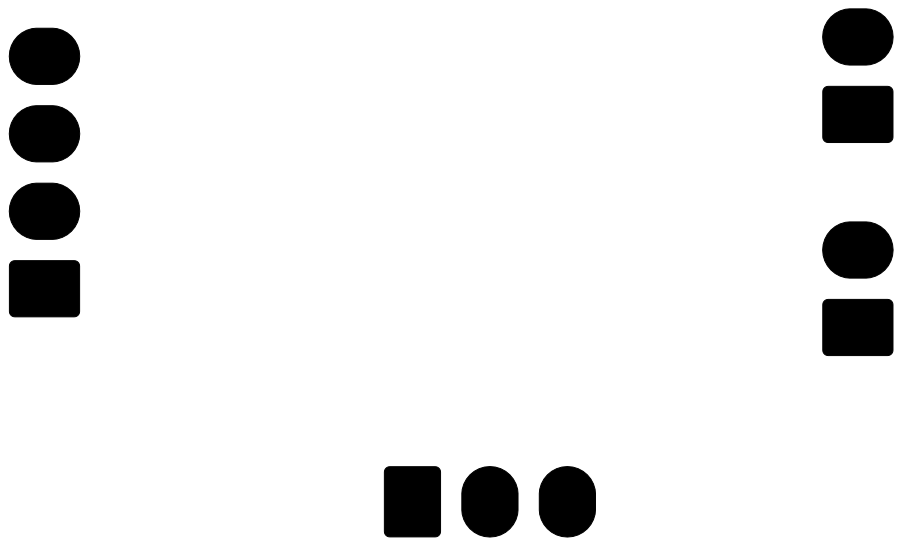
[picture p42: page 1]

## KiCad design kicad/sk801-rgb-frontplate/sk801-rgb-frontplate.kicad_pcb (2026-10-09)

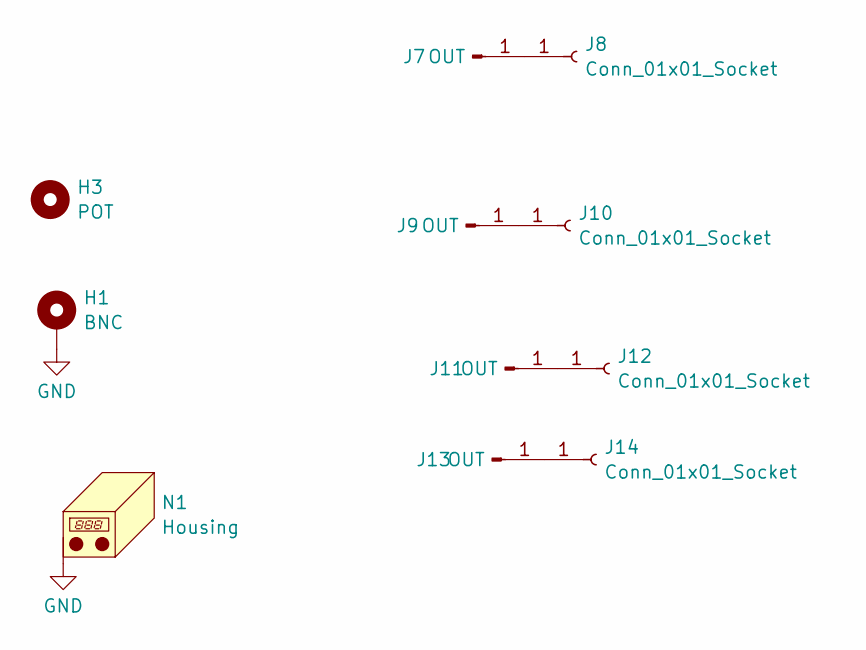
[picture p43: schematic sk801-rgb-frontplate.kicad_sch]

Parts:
H1: BNC; BNC_Ali_Frontplate
H3: POT; PotentiometerNournsPRS12Frontplate
J7, J9, J11, J13: OUT; Banana2mm-Löthülse
J8, J10, J12, J14: Conn_01x01_Socket; smd-1pin
N1: Housing; Frontplate_20mm

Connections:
GND: H1.1 (1_1), N1.1 (PAD_1)
unnamed: J7.1 (Pin_1_1), J8.1 (Pin_1_1)
unnamed: J9.1 (Pin_1_1), J10.1 (Pin_1_1)
unnamed: J11.1 (Pin_1_1), J12.1 (Pin_1_1)
unnamed: J13.1 (Pin_1_1), J14.1 (Pin_1_1)

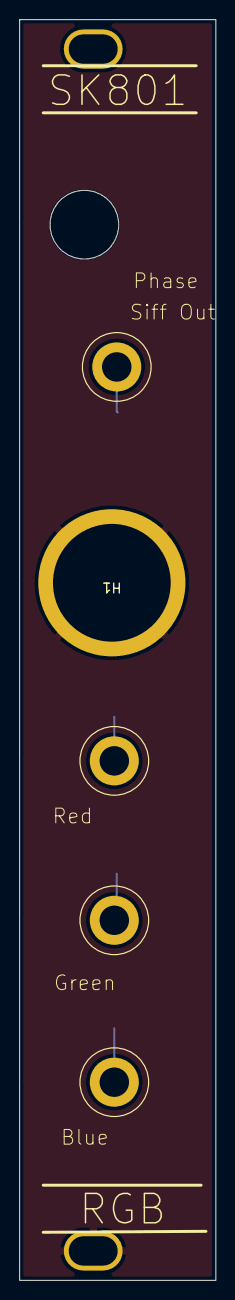
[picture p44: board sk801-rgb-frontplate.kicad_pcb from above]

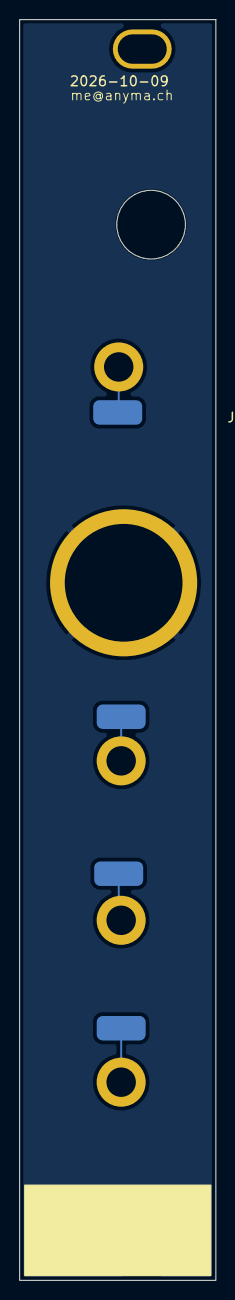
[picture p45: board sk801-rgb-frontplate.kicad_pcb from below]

Board: 2 copper layers, 20.0 x 128.5 mm, 11 parts (4 on the bottom side), 5 nets.

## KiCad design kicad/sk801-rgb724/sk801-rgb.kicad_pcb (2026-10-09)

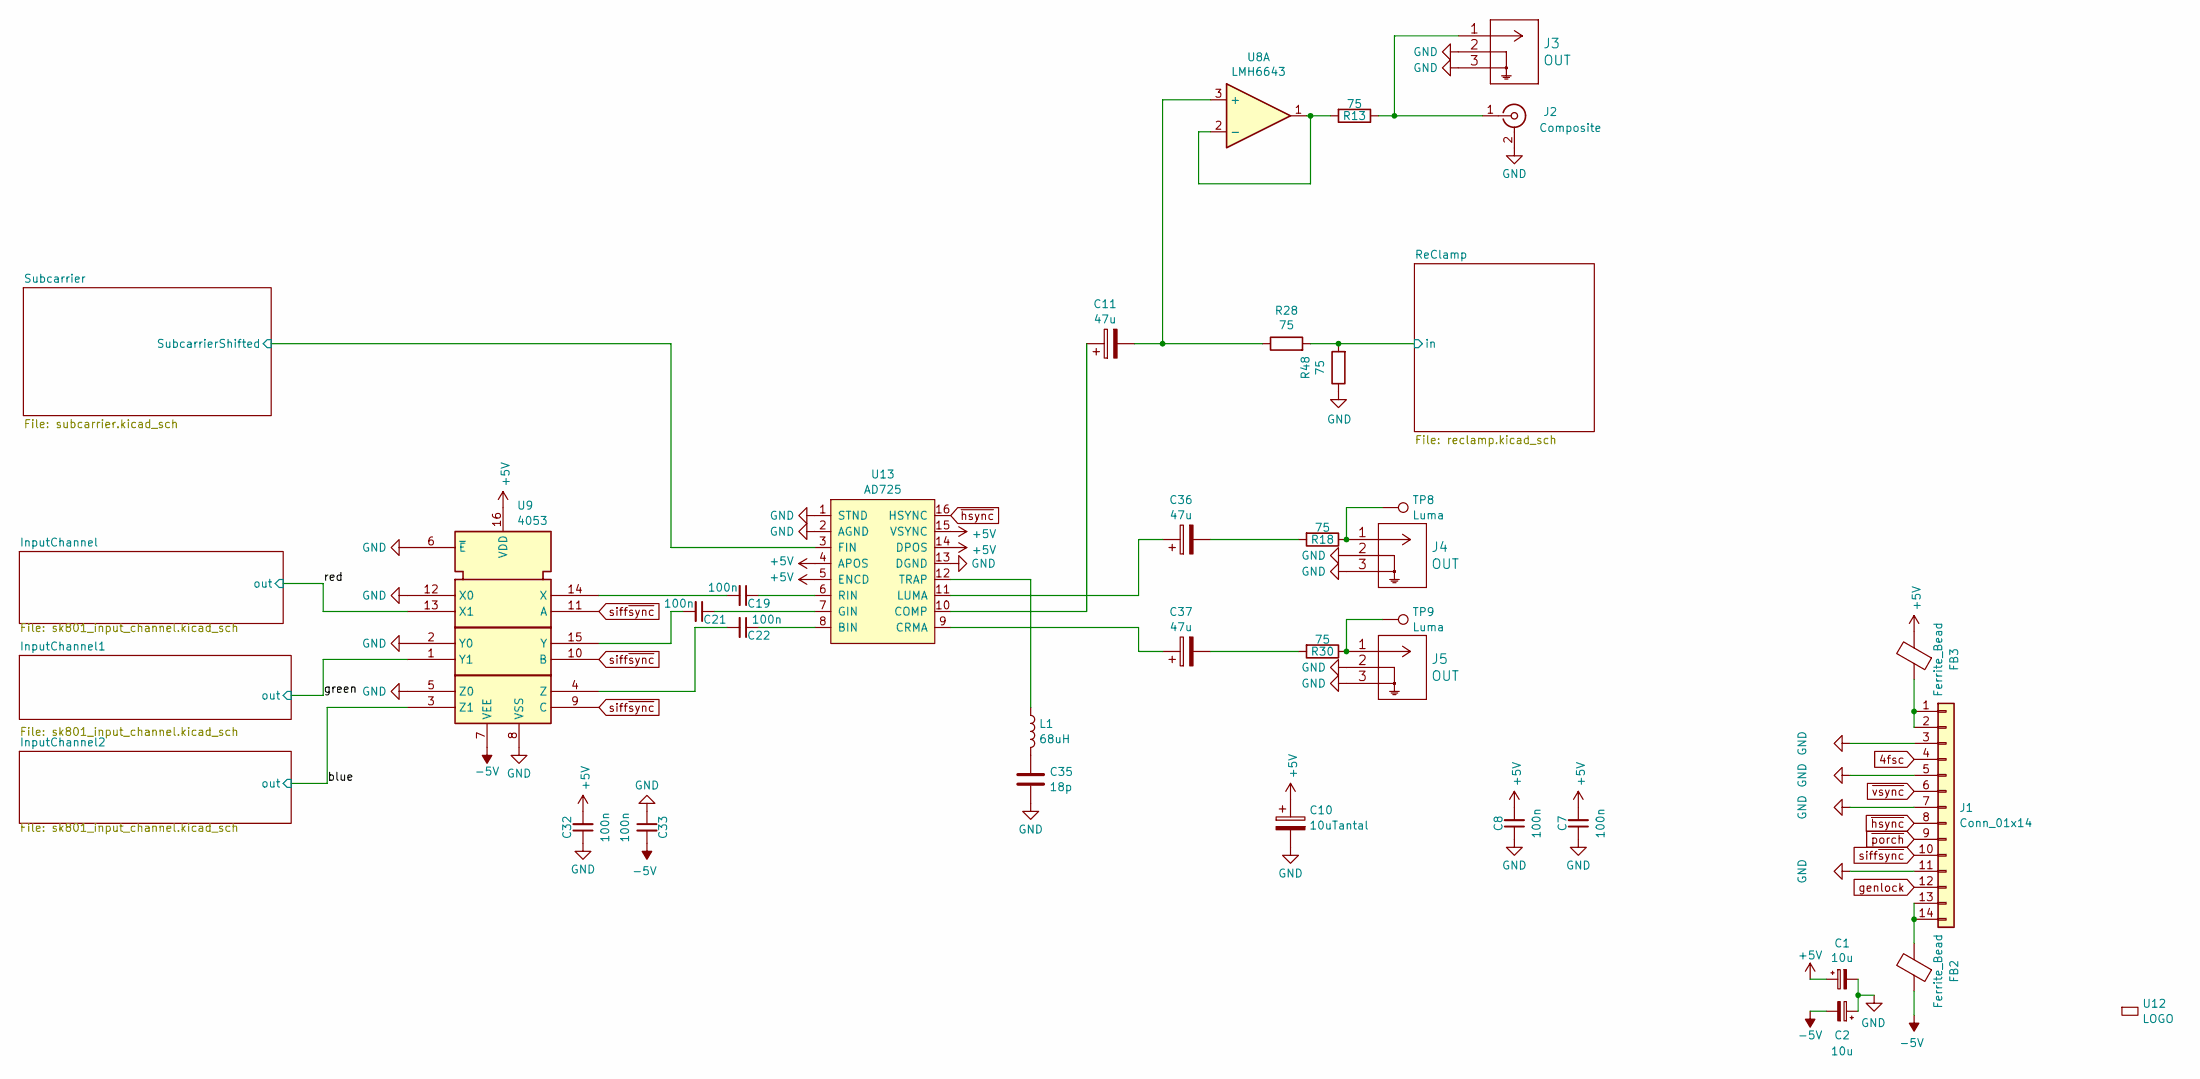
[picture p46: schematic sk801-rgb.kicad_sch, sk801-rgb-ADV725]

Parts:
C1, C2: 10u; C_0805_2012Metric; LCSC C15850
C7, C8, C19, C21, C22, C32, C33: 100n; C_0402_1005Metric; LCSC C1525
C10: 10uTantal; CP_EIA-3216-18_Kemet-A; LCSC C7171
C11, C36, C37: 47u; C_1206_3216Metric; LCSC C96123
C35: 18p; C_0603_1608Metric; LCSC C1647
FB2, FB3: Ferrite_Bead; L_0805_2012Metric; LCSC C1017
J1: Conn_01x14; SYNKIE-BUS.v3
J2: Composite; BNC_Aliexpress
J3, J4, J5: OUT; TE_UMCC_2337019-1; LCSC C5137195
L1: 68uH; L_APV_APH0420; LCSC C2929423
R13, R18, R28, R30, R48: 75; R_0603_1608Metric; LCSC C4275
TP8, TP9: Luma; TestPoint_THTPad_D4.0mm_Drill2.0mm
U8: LMH6643; VSSOP-8_3x3mm_P0.65mm; LCSC C478382
U9: 4053; SOIC-16_3.9x9.9mm_P1.27mm; LCSC C7500846
U12: LOGO; logo_anyma
U13: AD725; SOIC-16W_7.5x10.3mm_P1.27mm

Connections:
4fsc: J1.4; also elsewhere on the board
+5V: C1.1, C7.2, C8.2, C10.1, C32.2, FB3.2, U9.16 (VDD), U13.4 (APOS), U13.5 (ENCD), U13.14 (DPOS), U13.15 (VSYNC); also elsewhere on the board
-5V: C2.2, C33.2, FB2.1, U9.7 (VEE); also elsewhere on the board
/ReClamp/in: R28.2, R48.2; also elsewhere on the board
/Subcarrier/SubcarrierShifted: U13.3 (FIN); also elsewhere on the board
/blue: U9.3 (Z1); also elsewhere on the board
/green: U9.1 (Y1); also elsewhere on the board
/red: U9.13 (X1); also elsewhere on the board
GND: C1.2, C2.1, C7.1, C8.1, C10.2, C32.1, C33.1, C35.2, J1.3, J1.5, J1.7, J1.11, J2.2 (Ext), J3.2, J3.3, J4.2, J4.3, J5.2, J5.3, R48.1, U9.2 (Y0), U9.5 (Z0), U9.6 (~E), U9.8 (VSS), U9.12 (X0), U13.1 (STND), U13.2 (AGND), U13.13 (DGND); also elsewhere on the board
unnamed: C35.1, L1.2
unnamed: C36.2, R18.2
unnamed: C37.2, R30.2
unnamed: FB3.1, J1.1, J1.2
unnamed: FB2.2, J1.13, J1.14
unnamed: J2.1 (In), J3.1, R13.1
unnamed: J4.1, R18.1, TP8.1 (1_1)
unnamed: J5.1, R30.1, TP9.1 (1_1)
unnamed: C11.2, R28.1, U8.3 (+)
unnamed: R13.2, U8.1, U8.2 (-)
unnamed: C19.2, U9.14 (X)
unnamed: C21.2, U9.15 (Y)
unnamed: C22.2, U9.4 (Z)
unnamed: C22.1, U13.8 (BIN)
unnamed: C11.1, U13.10 (COMP)
unnamed: C37.1, U13.9 (CRMA)
unnamed: C21.1, U13.7 (GIN)
unnamed: C36.1, U13.11 (LUMA)
unnamed: C19.1, U13.6 (RIN)
unnamed: L1.1, U13.12 (TRAP)
genlock: J1.12
siff~sync: J1.10, U9.9 (C), U9.10 (B), U9.11 (A); also elsewhere on the board
~hsync: J1.8, U13.16 (HSYNC)
~porch: J1.9; also elsewhere on the board
~vsync: J1.6

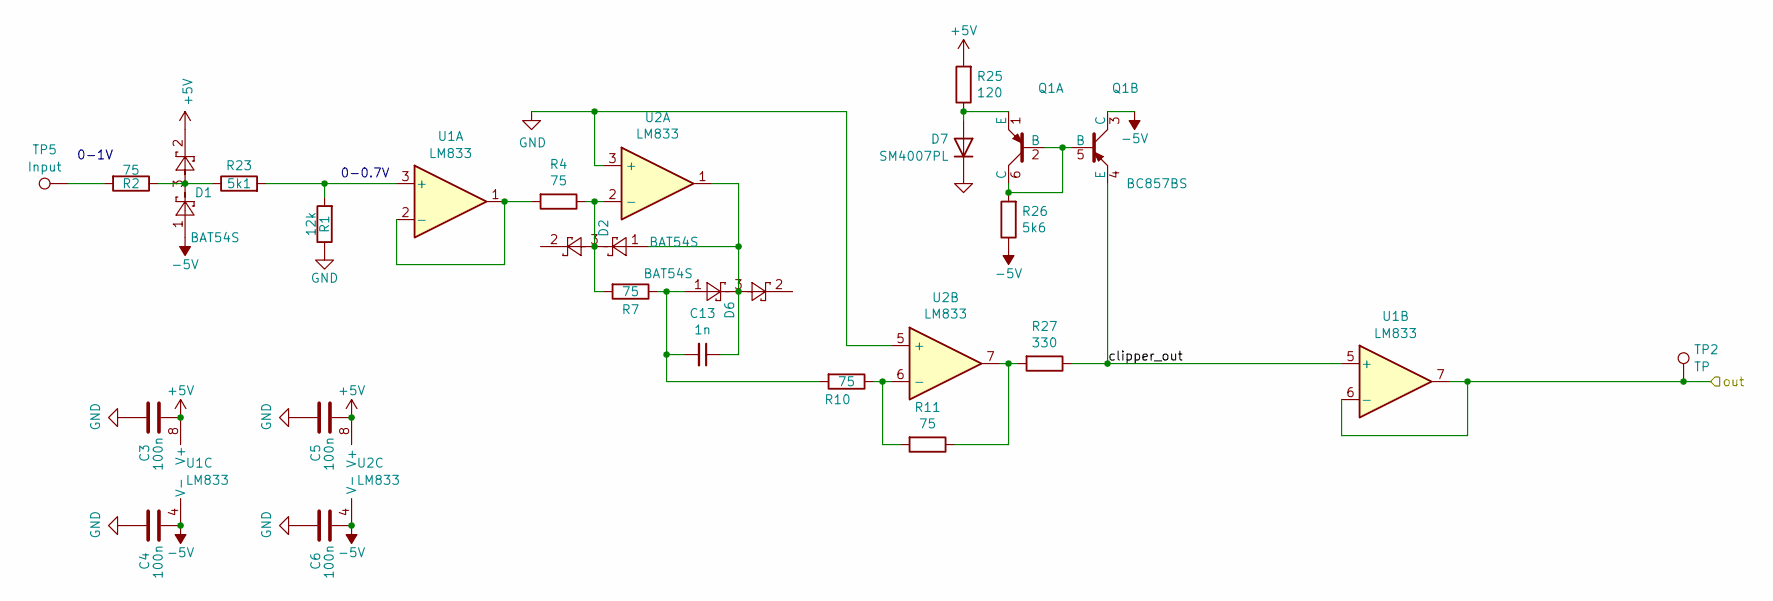
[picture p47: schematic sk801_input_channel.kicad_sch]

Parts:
C3, C4, C5, C6: 100n; C_0402_1005Metric; LCSC C1525
C13: 1n; C_0603_1608Metric; LCSC C1588
D1, D2, D6: BAT54S; SOT-23; LCSC C7420333
D7: SM4007PL; D_SOD-123F; LCSC C64898
Q1: BC857BS; SOT-363_SC-70-6_Handsoldering; LCSC C22381405
R1: 12k; R_0603_1608Metric; LCSC C22790
R2, R4, R7, R10, R11: 75; R_0603_1608Metric; LCSC C4275
R23: 5k1; R_0603_1608Metric; LCSC C23186
R25: 120; R_0603_1608Metric; LCSC C22787
R26: 5k6; R_0603_1608Metric; LCSC C23189
R27: 330; R_0603_1608Metric; LCSC C23138
TP2: TP; TestPoint_Pad_D2.0mm
TP5: Input; TestPoint_THTPad_D4.0mm_Drill2.0mm
U1, U2: LM833; SOIC-8_3.9x4.9mm_P1.27mm; LCSC C7969

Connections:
+5V: C3.2, C5.2, D1.2, R25.2, U1.8 (V+), U2.8 (V+); also elsewhere on the board
-5V: C4.2, C6.2, D1.1, Q1.3 (C), R26.1, U1.4 (V-), U2.4 (V-); also elsewhere on the board
/InputChannel/clipper_out: Q1.4 (E), R27.1, U1.5 (+)
/red: TP2.1 (1_1), U1.6 (-), U1.7; also elsewhere on the board
GND: C3.1, C4.1, C5.1, C6.1, D7.1 (K), R1.1, U2.3 (+), U2.5 (+); also elsewhere on the board
unnamed: C13.1, D2.1, D6.3, U2.1
unnamed: C13.2, D6.1, R7.1, R10.2
unnamed: D1.3, R2.1, R23.1
unnamed: D7.2 (A), Q1.1 (E), R25.1
unnamed: Q1.2 (B), Q1.5 (B), Q1.6 (C), R26.2
unnamed: R2.2, TP5.1 (1_1)
unnamed: R11.1, R27.2, U2.7
unnamed: R1.2, R23.2, U1.3 (+)
unnamed: R4.2, U1.1, U1.2 (-)
unnamed: D2.3, R4.1, R7.2, U2.2 (-)
unnamed: R10.1, R11.2, U2.6 (-)

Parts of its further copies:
C14, C15, C16, C18, C25, C26, C27, C28: 100n; C_0402_1005Metric; LCSC C1525
C23, C30: 1n; C_0603_1608Metric; LCSC C1588
D3, D4, D5, D8, D10, D11: BAT54S; SOT-23; LCSC C7420333
D9, D12: SM4007PL; D_SOD-123F; LCSC C64898
Q2, Q3: BC857BS; SOT-363_SC-70-6_Handsoldering; LCSC C22381405
R5, R16: 12k; R_0603_1608Metric; LCSC C22790
R6, R9, R12, R14, R15, R17, R19, R20, R21, R22: 75; R_0603_1608Metric; LCSC C4275
R24, R42: 5k1; R_0603_1608Metric; LCSC C23186
R37, R43: 120; R_0603_1608Metric; LCSC C22787
R38, R44: 5k6; R_0603_1608Metric; LCSC C23189
R39, R45: 330; R_0603_1608Metric; LCSC C23138
TP3, TP4: TP; TestPoint_Pad_D2.0mm
TP6, TP7: Input; TestPoint_THTPad_D4.0mm_Drill2.0mm
U3, U5, U6, U7: LM833; SOIC-8_3.9x4.9mm_P1.27mm; LCSC C7969

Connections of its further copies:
+5V: C14.2, C16.2, C25.2, C27.2, D3.2, D5.2, R37.2, R43.2, U3.8 (V+), U5.8 (V+), U6.8 (V+), U7.8 (V+); also elsewhere on the board
-5V: C15.2, C18.2, C26.2, C28.2, D3.1, D5.1, Q2.3 (C), Q3.3 (C), R38.1, R44.1, U3.4 (V-), U5.4 (V-), U6.4 (V-), U7.4 (V-); also elsewhere on the board
/InputChannel1/clipper_out: Q2.4 (E), R39.1, U3.5 (+)
/InputChannel2/clipper_out: Q3.4 (E), R45.1, U6.5 (+)
/blue: TP4.1 (1_1), U6.6 (-), U6.7; also elsewhere on the board
/green: TP3.1 (1_1), U3.6 (-), U3.7; also elsewhere on the board
GND: C14.1, C15.1, C16.1, C18.1, C25.1, C26.1, C27.1, C28.1, D9.1 (K), D12.1 (K), R5.1, R16.1, U5.3 (+), U5.5 (+), U7.3 (+), U7.5 (+); also elsewhere on the board
unnamed: C23.1, D4.1, D8.3, U5.1
unnamed: C23.2, D8.1, R12.1, R14.2
unnamed: C30.1, D10.1, D11.3, U7.1
unnamed: C30.2, D11.1, R20.1, R21.2
unnamed: D3.3, R6.1, R24.1
unnamed: D5.3, R17.1, R42.1
unnamed: D9.2 (A), Q2.1 (E), R37.1
unnamed: D12.2 (A), Q3.1 (E), R43.1
unnamed: Q2.2 (B), Q2.5 (B), Q2.6 (C), R38.2
unnamed: Q3.2 (B), Q3.5 (B), Q3.6 (C), R44.2
unnamed: R6.2, TP6.1 (1_1)
unnamed: R15.1, R39.2, U5.7
unnamed: R17.2, TP7.1 (1_1)
unnamed: R22.1, R45.2, U7.7
unnamed: R5.2, R24.2, U3.3 (+)
unnamed: R9.2, U3.1, U3.2 (-)
unnamed: D4.3, R9.1, R12.2, U5.2 (-)
unnamed: R14.1, R15.2, U5.6 (-)
unnamed: R16.2, R42.2, U6.3 (+)
unnamed: R19.2, U6.1, U6.2 (-)
unnamed: D10.3, R19.1, R20.2, U7.2 (-)
unnamed: R21.1, R22.2, U7.6 (-)

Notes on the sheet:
0-0.7V
0-1V

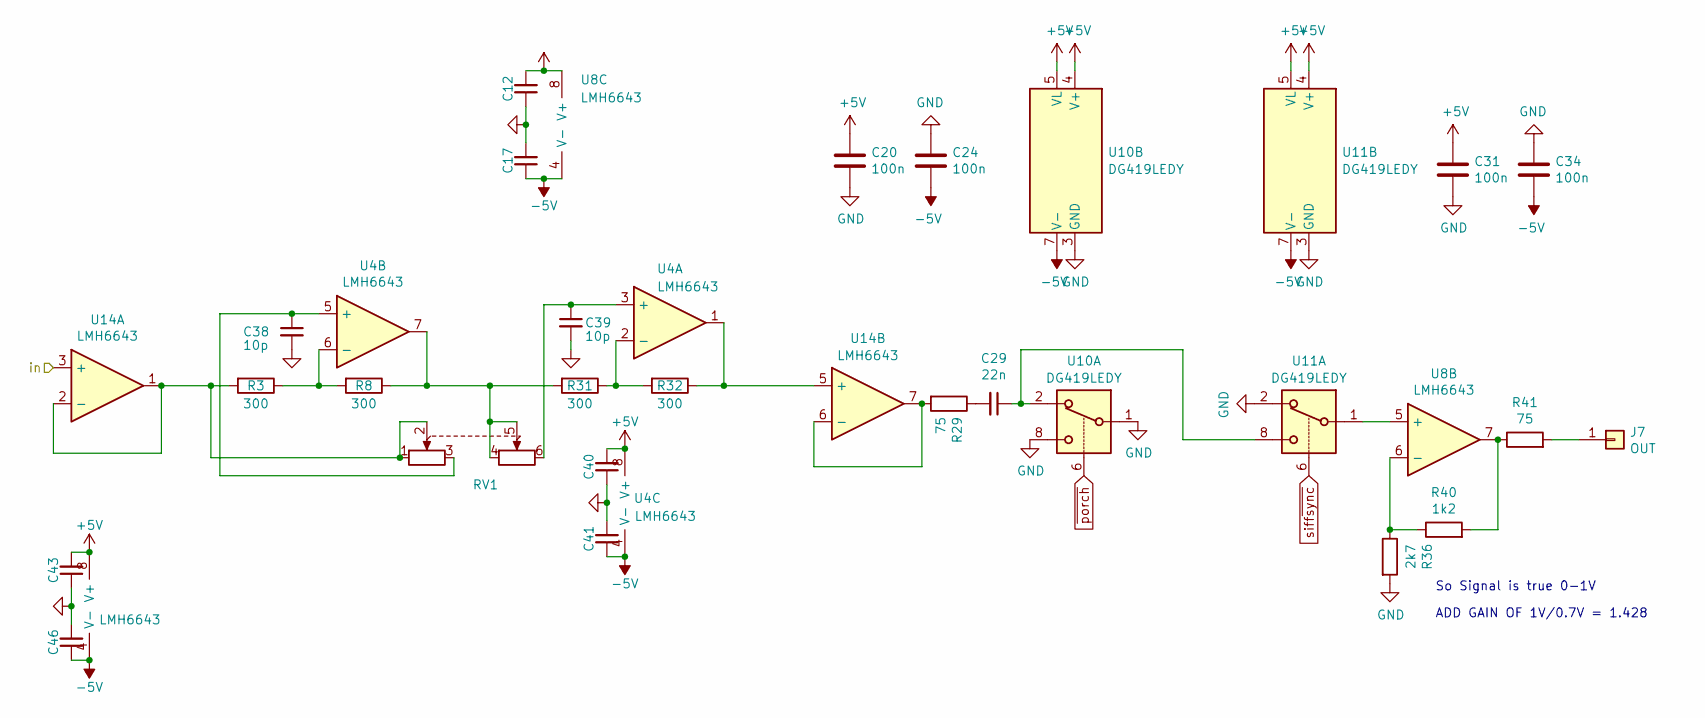
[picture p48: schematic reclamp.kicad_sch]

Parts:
C12, C17, C20, C24, C31, C34, C40, C41, C43, C46: 100n; C_0402_1005Metric; LCSC C1525
C29: 22n; C_0603_1608Metric; LCSC C21122
C38, C39: 10p; C_0603_1608Metric; LCSC C1634
J7: OUT; TestPoint_THTPad_D4.0mm_Drill2.0mm
R3, R8, R31, R32: 300; R_0603_1608Metric; LCSC C23025
R29, R41: 75; R_0603_1608Metric; LCSC C4275
R36: 2k7; R_0603_1608Metric; LCSC C13167
R40: 1k2; R_0603_1608Metric; LCSC C22765
RV1: PRS12R-2
U4, U8, U14: LMH6643; VSSOP-8_3x3mm_P0.65mm; LCSC C478382
U10, U11: DG419LEDY; SOIC-8_3.9x4.9mm_P1.27mm; LCSC C2673265

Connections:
+5V: C12.2, C20.1, C31.1, C40.2, C43.2, U4.8 (V+), U8.8 (V+), U10.4 (V+), U10.5 (VL), U11.4 (V+), U11.5 (VL), U14.8 (V+); also elsewhere on the board
-5V: C17.1, C24.2, C34.2, C41.1, C46.1, U4.4 (V-), U8.4 (V-), U10.7 (V-), U11.7 (V-), U14.4 (V-); also elsewhere on the board
/ReClamp/in: U14.3 (+); also elsewhere on the board
GND: C12.1, C17.2, C20.2, C24.1, C31.2, C34.1, C38.2, C39.2, C40.1, C41.2, C43.1, C46.2, R36.2, U10.1, U10.3 (GND), U10.8, U11.2, U11.3 (GND); also elsewhere on the board
unnamed: C29.1, U10.2, U11.8
unnamed: C29.2, R29.1
unnamed: J7.1 (Pin_1_1), R41.2
unnamed: R8.1, R31.2, RV1.4, RV1.5, U4.7
unnamed: R40.2, R41.1, U8.7
unnamed: C39.1, RV1.6, U4.3 (+)
unnamed: R31.1, R32.2, U4.2 (-)
unnamed: C38.1, RV1.3, U4.5 (+)
unnamed: R3.1, R8.2, U4.6 (-)
unnamed: U8.5 (+), U11.1
unnamed: R36.1, R40.1, U8.6 (-)
unnamed: R3.2, RV1.1, RV1.2, U14.1, U14.2 (-)
unnamed: R32.1, U4.1, U14.5 (+)
unnamed: R29.2, U14.6 (-), U14.7
siff~sync: U11.6; also elsewhere on the board
~porch: U10.6; also elsewhere on the board

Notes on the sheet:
ADD GAIN OF 1V/0.7V = 1.428
So Signal is true 0-1V

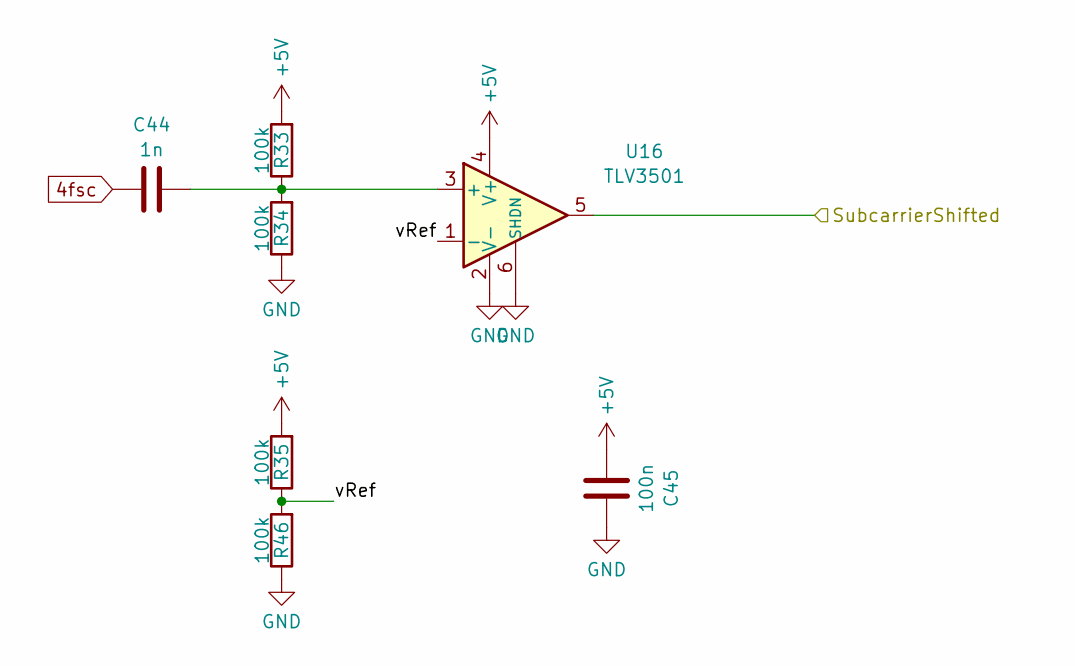
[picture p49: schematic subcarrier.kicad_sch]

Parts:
C44: 1n; C_0603_1608Metric; LCSC C1588
C45: 100n; C_0402_1005Metric; LCSC C1525
R33, R34, R35, R46: 100k; R_0603_1608Metric; LCSC C25803
U16: TLV3501; SOT-23-6; LCSC C133251

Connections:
4fsc: C44.1; also elsewhere on the board
+5V: C45.1, R33.2, R35.2, U16.4 (V+); also elsewhere on the board
/Subcarrier/SubcarrierShifted: U16.5; also elsewhere on the board
/Subcarrier/vRef: R35.1, R46.2, U16.1 (-)
GND: C45.2, R34.1, R46.1, U16.2 (V-), U16.6 (SHDN); also elsewhere on the board
unnamed: C44.2, R33.1, R34.2, U16.3 (+)

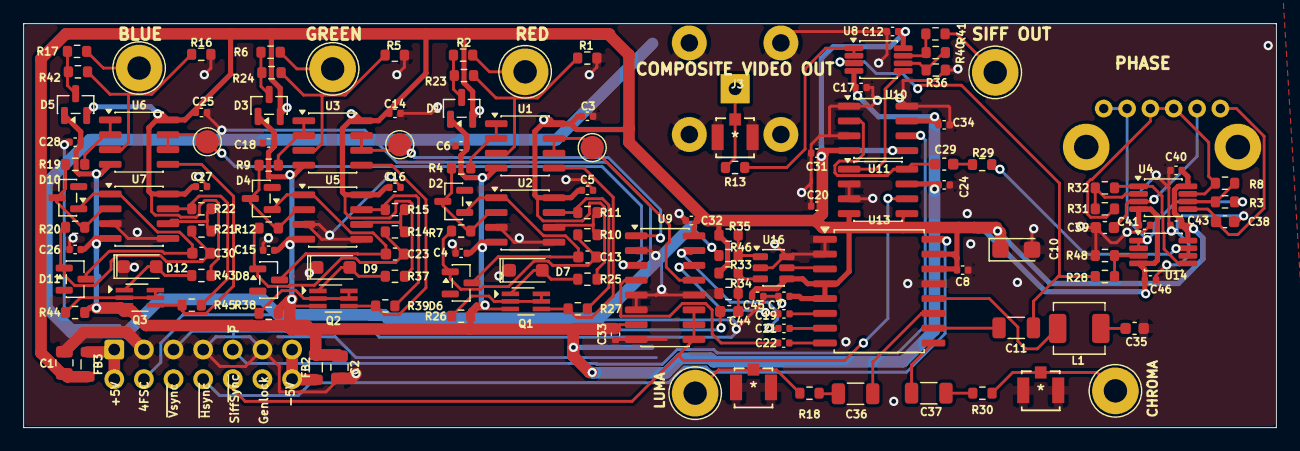
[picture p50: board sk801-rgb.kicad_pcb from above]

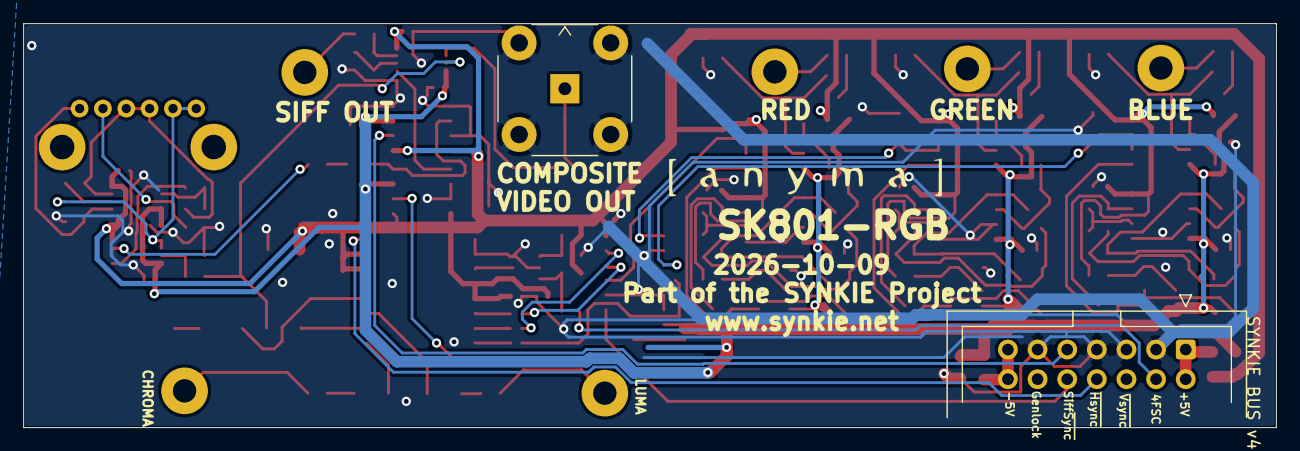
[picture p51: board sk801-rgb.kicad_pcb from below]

Board: 2 copper layers, 107.4 x 34.6 mm, 139 parts (4 on the bottom side), 84 nets.

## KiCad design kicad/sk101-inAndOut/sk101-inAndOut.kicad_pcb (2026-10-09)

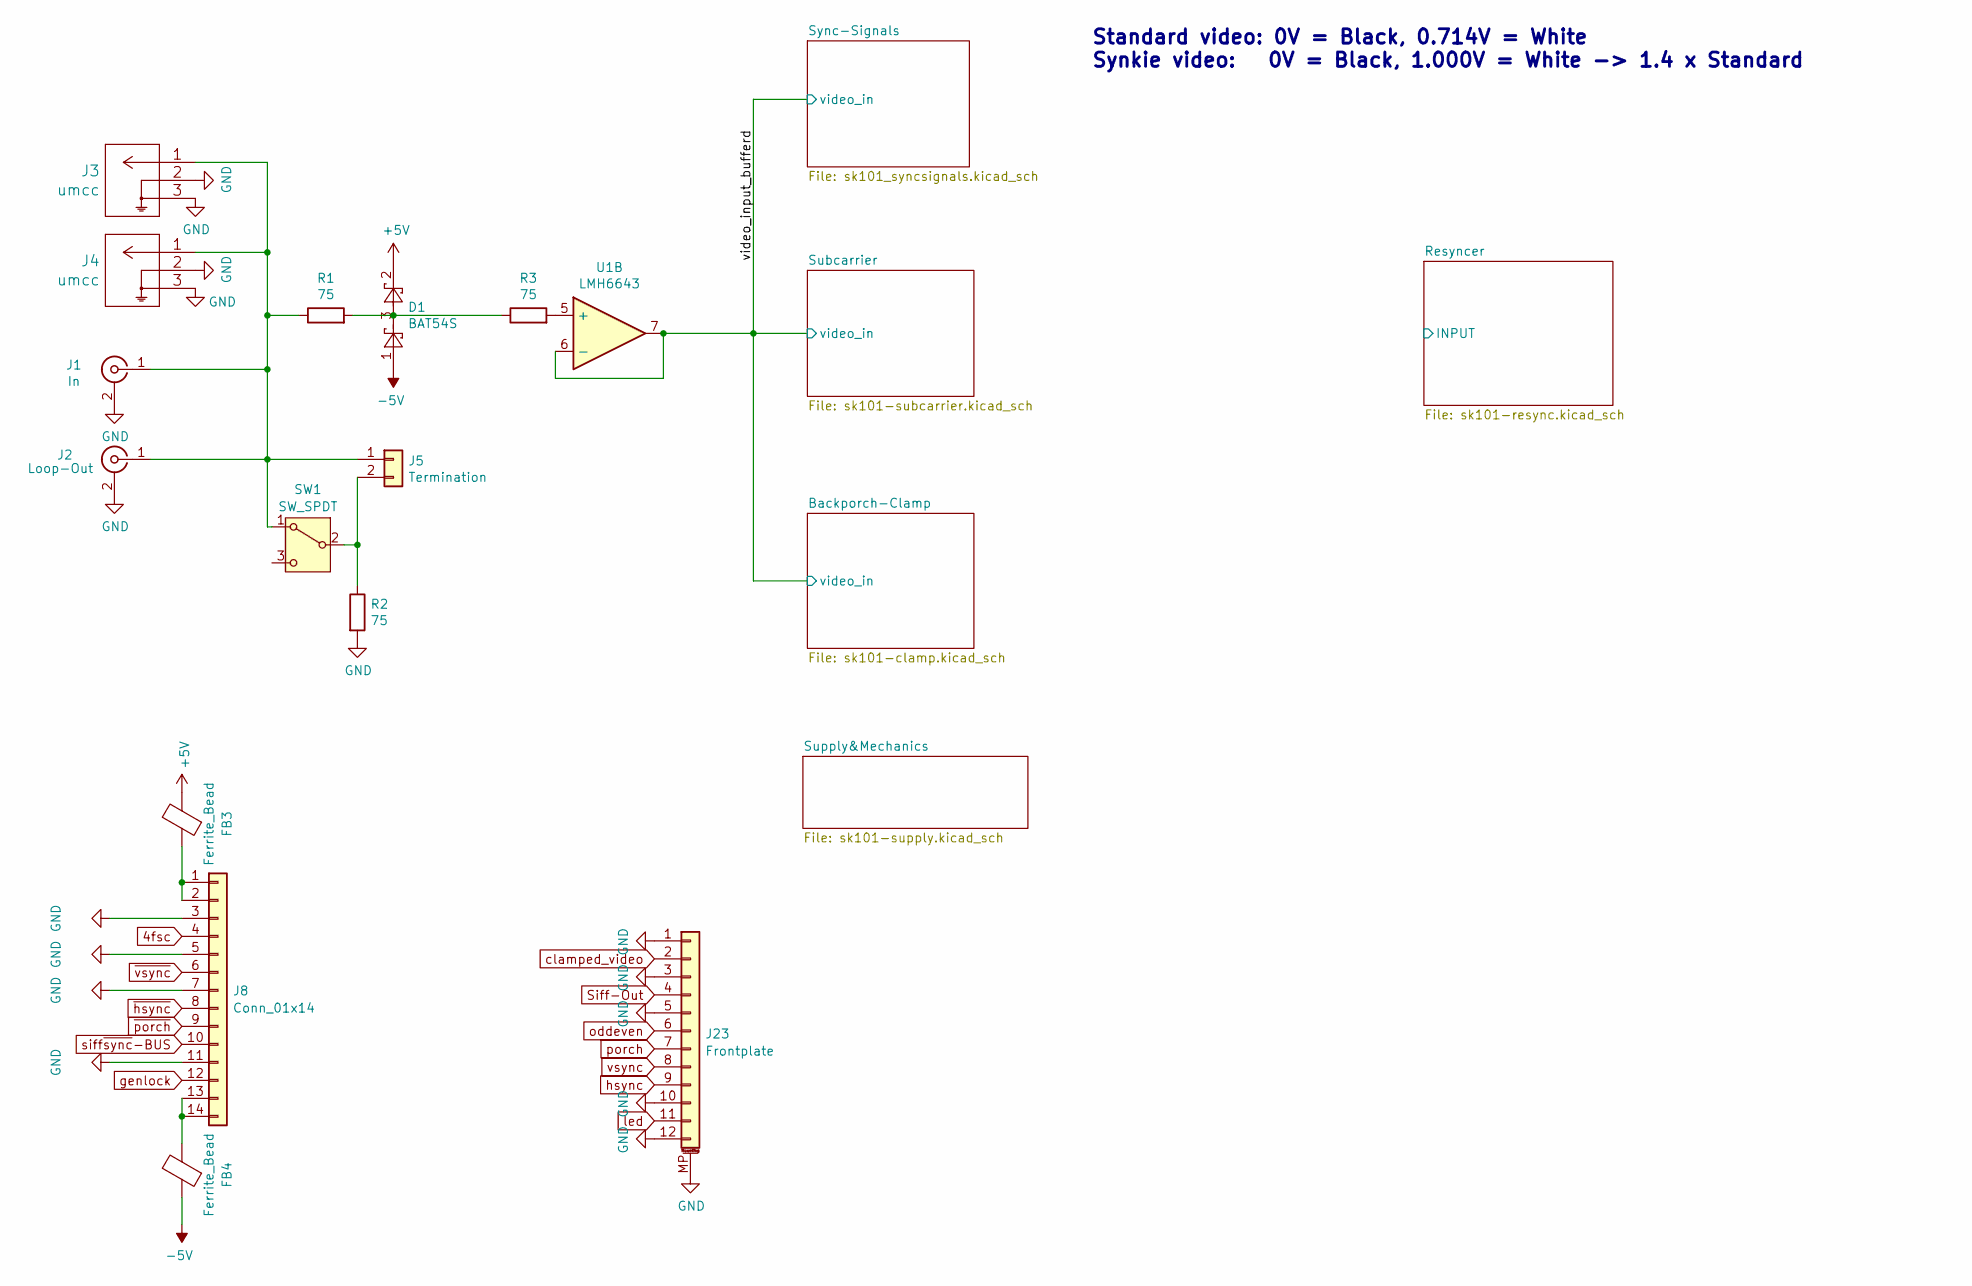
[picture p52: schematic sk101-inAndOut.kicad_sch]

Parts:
D1: BAT54S; SOT-23; LCSC C7420333
FB3, FB4: Ferrite_Bead; L_0805_2012Metric; LCSC C1017
J1: In; BNC_Aliexpress
J2: Loop-Out; BNC_Aliexpress
J3, J4: umcc; TE_UMCC_2337019-1; LCSC C5137195
J5: Termination; PinHeader_1x02_P2.54mm_Vertical
J8: Conn_01x14; SYNKIE-BUS.v3
J23: Frontplate; AFC04-S12FCC-00; LCSC C21275
R1, R2, R3: 75; R_0603_1608Metric; LCSC C4275
SW1: SW_SPDT; CUS-12TB_NDC; LCSC C109335
U1: LMH6643; VSSOP-8_3x3mm_P0.65mm; LCSC C478382

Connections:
4fsc: J8.4; also elsewhere on the board
+5V: D1.2, FB3.2; also elsewhere on the board
-5V: D1.1, FB4.1; also elsewhere on the board
/video_input_bufferd: U1.6 (-), U1.7; also elsewhere on the board
GND: J1.2 (Ext), J2.2 (Ext), J3.2, J3.3, J4.2, J4.3, J8.3, J8.5, J8.7, J8.11, J23.1, J23.3, J23.5, J23.10, J23.12, J23.MP (MountPin), R2.2; also elsewhere on the board
unnamed: D1.3, R1.2, R3.1
unnamed: J1.1 (In), J2.1 (In), J3.1, J4.1, J5.1, R1.1, SW1.1 (A)
unnamed: J5.2, R2.1, SW1.2 (B)
unnamed: FB3.1, J8.1, J8.2
unnamed: FB4.2, J8.13, J8.14
unnamed: R3.2, U1.5 (+)
Siff-Out: J23.4; also elsewhere on the board
clamped_video: J23.2; also elsewhere on the board
genlock: J8.12; also elsewhere on the board
hsync: J23.9; also elsewhere on the board
led: J23.11; also elsewhere on the board
oddeven: J23.6; also elsewhere on the board
porch: J23.7; also elsewhere on the board
siff~sync-BUS: J8.10; also elsewhere on the board
vsync: J23.8; also elsewhere on the board
~hsync: J8.8; also elsewhere on the board
~porch: J8.9; also elsewhere on the board
~vsync: J8.6; also elsewhere on the board

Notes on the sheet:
Standard video: 0V = Black, 0.714V = White Synkie video: 0V = Black, 1.000V = White -> 1.4 x Standard

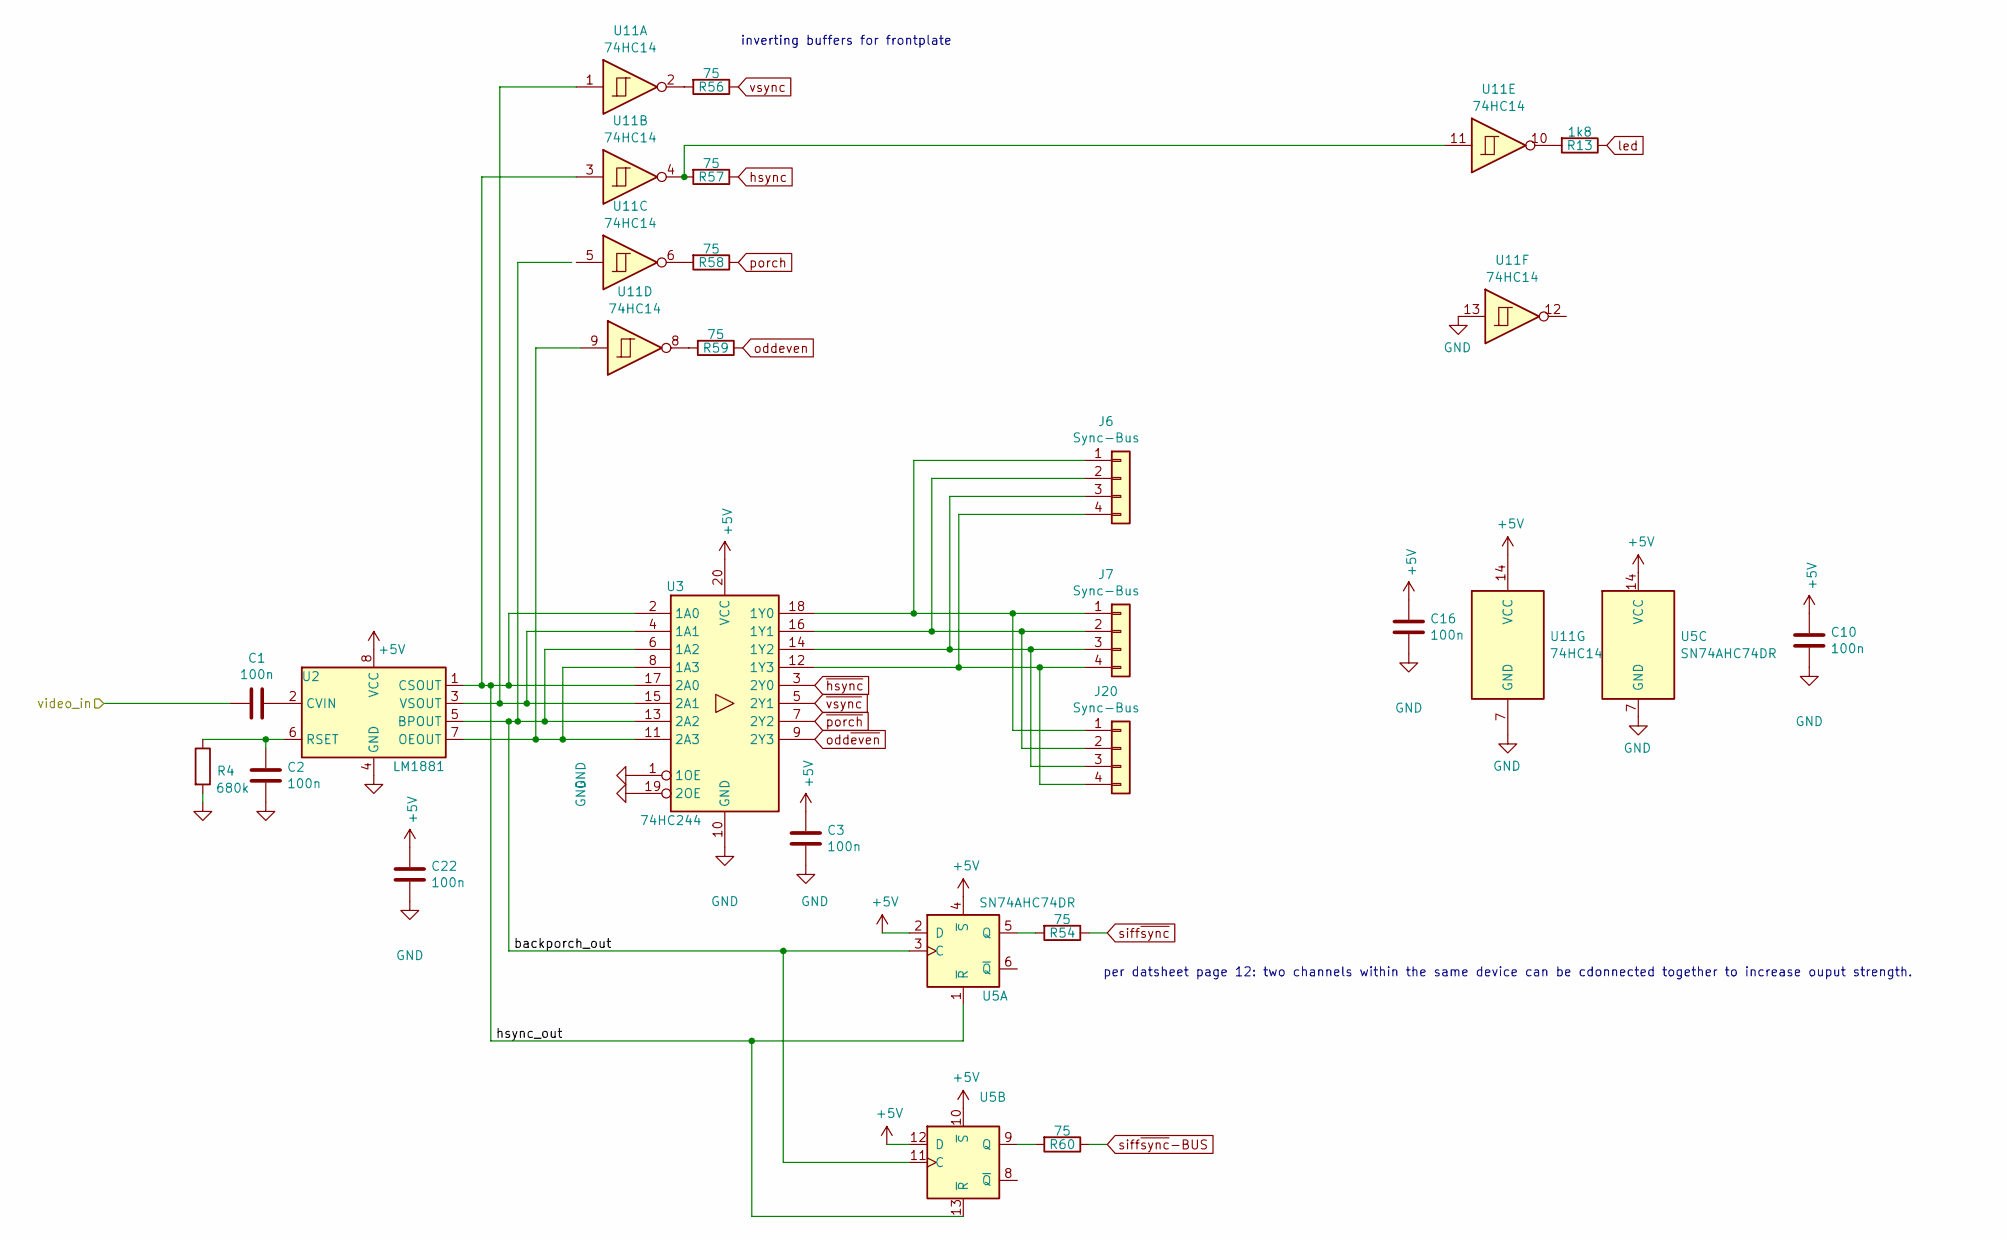
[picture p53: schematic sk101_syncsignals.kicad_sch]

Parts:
C1, C2, C3, C10, C16, C22: 100n; C_0603_1608Metric; LCSC C14663
J6, J7: Sync-Bus; Hirose_DF13-04P-1.25DSA_1x04_P1.25mm_Vertical; LCSC C17617036
J20: Sync-Bus; Molex_KK-254_AE-6410-04A_1x04_P2.54mm_Vertical; LCSC C17617036
R4: 680k; R_0603_1608Metric; LCSC C25822
R13: 1k8; R_0603_1608Metric; LCSC C4177
R54, R56, R57, R58, R59, R60: 75; R_0603_1608Metric; LCSC C4275
U2: LM1881; SOIC-8_3.9x4.9mm_P1.27mm; LCSC C518922
U3: 74HC244; SO-20_12.8x7.5mm_P1.27mm; LCSC C5622
U5: SN74AHC74DR; SOIC-14_3.9x8.7mm_P1.27mm; LCSC C7621
U11: 74HC14; SOIC-14_3.9x8.7mm_P1.27mm; LCSC C5605

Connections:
+5V: C3.1, C10.1, C16.1, C22.1, U2.8 (VCC), U3.20 (VCC), U5.2 (D), U5.4 (~S), U5.10 (~S), U5.12 (D), U5.14 (VCC), U11.14 (VCC); also elsewhere on the board
/Sync-Signals/backporch_out: U2.5 (BPOUT), U3.6 (1A2), U3.13 (2A2), U5.3 (C), U5.11 (C)
/Sync-Signals/hsync_out: U2.1 (CSOUT), U3.2 (1A0), U3.17 (2A0), U5.1 (~R), U5.13 (~R), U11.3
/video_input_bufferd: C1.2; also elsewhere on the board
GND: C2.2, C3.2, C10.2, C16.2, C22.2, R4.2, U2.4 (GND), U3.1 (1OE), U3.10 (GND), U3.19 (2OE), U5.7 (GND), U11.7 (GND), U11.13; also elsewhere on the board
unnamed: J6.1, J7.1, J20.1, U3.18 (1Y0)
unnamed: J6.2, J7.2, J20.2, U3.16 (1Y1)
unnamed: J6.3, J7.3, J20.3, U3.14 (1Y2)
unnamed: J6.4, J7.4, J20.4, U3.12 (1Y3)
unnamed: R13.2, U11.10
unnamed: R56.2, U11.2
unnamed: R57.2, U11.4, U11.11
unnamed: R58.2, U11.6
unnamed: R59.2, U11.8
unnamed: C1.1, U2.2 (CVIN)
unnamed: U2.7 (OEOUT), U3.8 (1A3), U3.11 (2A3), U11.9
unnamed: C2.1, R4.1, U2.6 (RSET)
unnamed: U2.3 (VSOUT), U3.4 (1A1), U3.15 (2A1), U11.1
unnamed: R54.2, U5.5 (Q)
unnamed: R60.2, U5.9 (Q)
hsync: R57.1; also elsewhere on the board
led: R13.1; also elsewhere on the board
oddeven: R59.1; also elsewhere on the board
odd~even: U3.9 (2Y3)
porch: R58.1; also elsewhere on the board
siff~sync: R54.1; also elsewhere on the board
siff~sync-BUS: R60.1; also elsewhere on the board
vsync: R56.1; also elsewhere on the board
~hsync: U3.3 (2Y0); also elsewhere on the board
~porch: U3.7 (2Y2); also elsewhere on the board
~vsync: U3.5 (2Y1); also elsewhere on the board

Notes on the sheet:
inverting buffers for frontplate
per datsheet page 12: two channels within the same device can be cdonnected together to increase ouput strength.

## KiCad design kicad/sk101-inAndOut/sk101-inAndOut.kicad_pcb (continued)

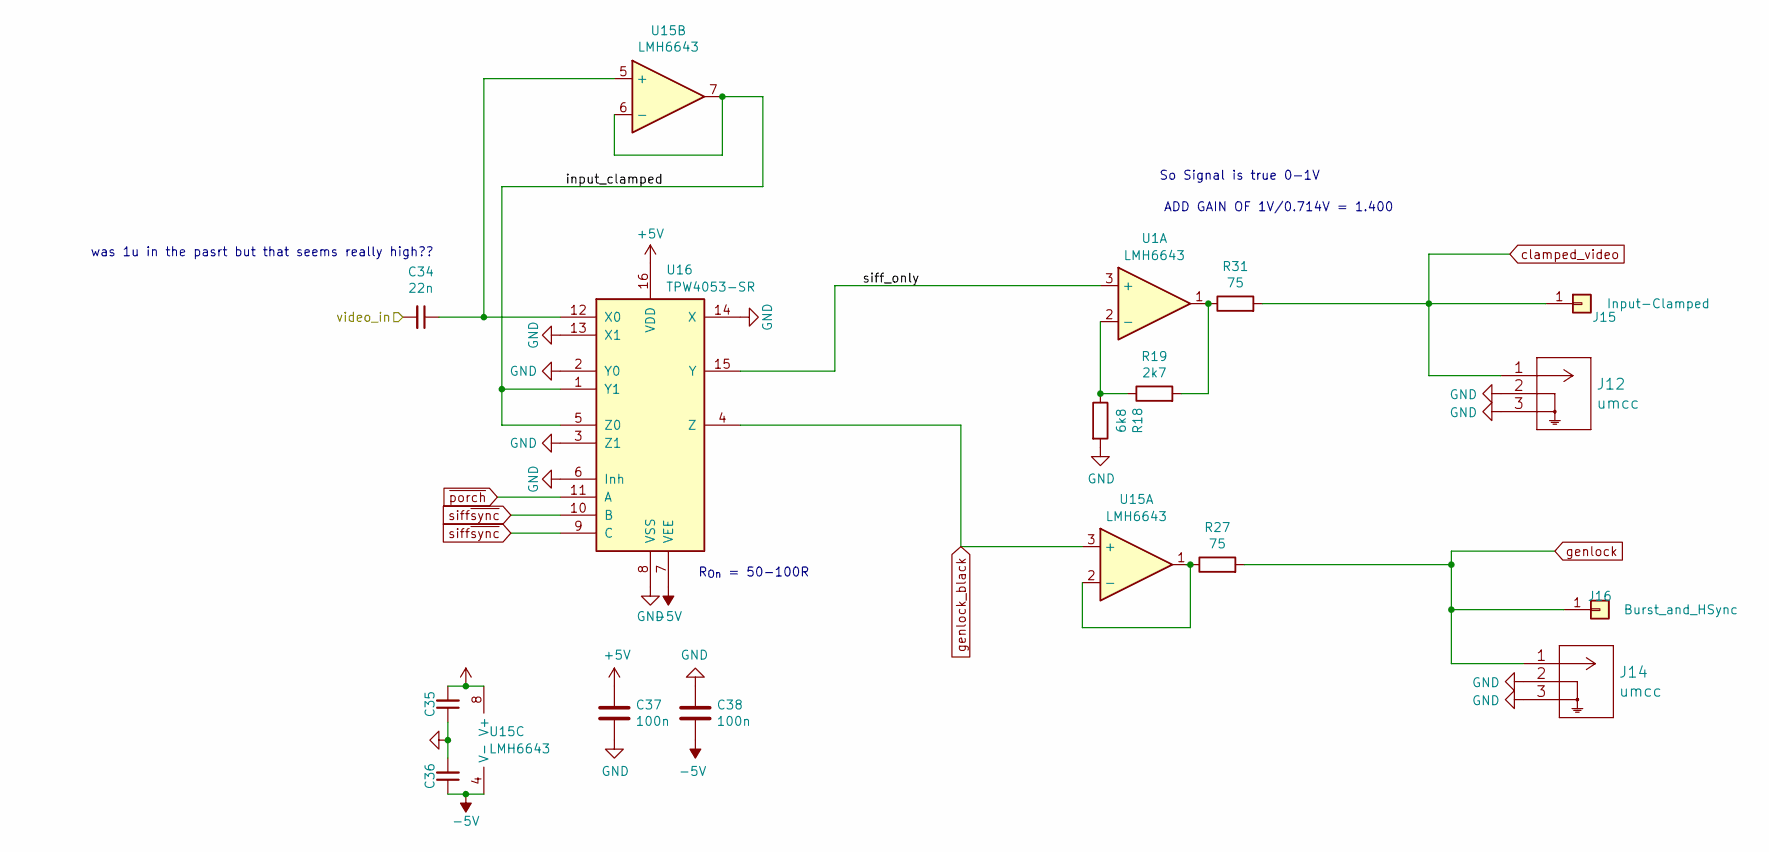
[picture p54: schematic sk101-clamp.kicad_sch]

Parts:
C34: 22n; C_0805_2012Metric_Pad1.15x1.40mm_HandSolder; LCSC C1729
C35, C36, C37, C38: 100n; C_0603_1608Metric; LCSC C14663
J12, J14: umcc; TE_UMCC_2337019-1; LCSC C5137195
J15: Input-Clamped; TestPoint_THTPad_D4.0mm_Drill2.0mm
J16: Burst_and_HSync; TestPoint_THTPad_D4.0mm_Drill2.0mm
R18: 6k8; R_0603_1608Metric; LCSC C23212
R19: 2k7; R_0603_1608Metric; LCSC C13167
R27, R31: 75; R_0603_1608Metric; LCSC C4275
U1, U15: LMH6643; VSSOP-8_3x3mm_P0.65mm; LCSC C478382
U16: TPW4053-SR; SOIC-16_3.9x9.9mm_P1.27mm; LCSC C7500846

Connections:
+5V: C35.2, C37.1, U15.8 (V+), U16.16 (VDD); also elsewhere on the board
-5V: C36.1, C38.2, U15.4 (V-), U16.7 (VEE); also elsewhere on the board
/Backporch-Clamp/input_clamped: U15.6 (-), U15.7, U16.1 (Y1), U16.5 (Z0)
/Backporch-Clamp/siff_only: U1.3 (+), U16.15 (Y)
/video_input_bufferd: C34.2; also elsewhere on the board
GND: C35.1, C36.2, C37.2, C38.1, J12.2, J12.3, J14.2, J14.3, R18.2, U16.2 (Y0), U16.3 (Z1), U16.6 (Inh), U16.8 (VSS), U16.13 (X1), U16.14 (X); also elsewhere on the board
unnamed: R19.2, R31.1, U1.1
unnamed: R18.1, R19.1, U1.2 (-)
unnamed: R27.1, U15.1, U15.2 (-)
unnamed: C34.1, U15.5 (+), U16.12 (X0)
clamped_video: J12.1, J15.1 (Pin_1_1), R31.2; also elsewhere on the board
genlock: J14.1, J16.1 (Pin_1_1), R27.2; also elsewhere on the board
genlock_black: U15.3 (+), U16.4 (Z); also elsewhere on the board
siff~sync: U16.9 (C), U16.10 (B); also elsewhere on the board
~porch: U16.11 (A); also elsewhere on the board

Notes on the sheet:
ADD GAIN OF 1V/0.714V = 1.400
So Signal is true 0-1V
R_{On} = 50-100R
was 1u in the pasrt but that seems really high??


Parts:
C12, C29: 10uTantal; CP_EIA-3216-18_Kemet-A; LCSC C7171
C13, C14: 100n; C_0603_1608Metric; LCSC C14663
FB1, FB2: Ferrite_Bead; L_0805_2012Metric_Pad1.15x1.40mm_HandSolder; LCSC C1017
H5: Croco; CrocodileGroundPad
J18: Supply; Hirose_DF13-03P-1.25DSA_1x03_P1.25mm_Vertical
J19: Supply; Molex_KK-254_AE-6410-03A_1x03_P2.54mm_Vertical
U1: LMH6643; VSSOP-8_3x3mm_P0.65mm; LCSC C478382
U7: LOGO; logo_anyma
U8: LOGO; OSHW-Logo2_7.3x6mm_SilkScreen

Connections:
+5V: C13.2, C29.1, FB1.2, U1.8 (V+); also elsewhere on the board
-5V: C12.2, C14.1, FB2.2, U1.4 (V-); also elsewhere on the board
GND: C12.1, C13.1, C14.2, C29.2, H5.1 (1_1), J18.2, J19.2; also elsewhere on the board
unnamed: FB1.1, J18.1, J19.1
unnamed: FB2.1, J18.3, J19.3


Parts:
C11: 1n; C_0603_1608Metric; LCSC C1588
C15: 200p; C_0603_1608Metric_Pad1.05x0.95mm_HandSolder; LCSC C1603
C23, C24, C26, C27, C28, C30, C31, C32: 100n; C_0603_1608Metric; LCSC C14663
D4: SM4007PL; D_SOD-123F; LCSC C64898
D8, D9, D10: BAT54S; SOT-23; LCSC C7420333
J13: umcc; TE_UMCC_2337019-1; LCSC C5137195
J22: Video-Out; BNC_Aliexpress
J24: Video Out; TestPoint_THTPad_D4.0mm_Drill2.0mm
Q8: BC857BS; SOT-363_SC-70-6_Handsoldering; LCSC C22381405
R12, R14, R15, R16, R17, R23, R34, R42: 75; R_0603_1608Metric; LCSC C4275
R20: 120; R_0603_1608Metric; LCSC C22787
R21: 5k6; R_0603_1608Metric; LCSC C23189
R22: 330; R_0603_1608Metric; LCSC C23138
R41, R47, R55: 12k; R_0603_1608Metric; LCSC C22790
R43: 5k1; R_0603_1608Metric; LCSC C23186
TP1: TestPoint; TestPoint_THTPad_D4.0mm_Drill2.0mm
U6: DG419LEDY; SOIC-8_3.9x4.9mm_P1.27mm; LCSC C2673265
U9, U10, U301: LMH6643; VSSOP-8_3x3mm_P0.65mm; LCSC C478382

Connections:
+5V: C23.2, C26.2, C28.2, C30.1, D8.2, R20.2, U6.4 (V+), U6.5 (VL), U9.8 (V+), U10.8 (V+), U301.8 (V+); also elsewhere on the board
-5V: C24.2, C27.2, C31.2, C32.2, D8.1, Q8.3 (C), R21.1, U6.7 (V-), U9.4 (V-), U10.4 (V-), U301.4 (V-); also elsewhere on the board
/Resyncer/clipper_out: Q8.4 (E), R22.1, U10.3 (+)
GND: C15.2, C23.1, C24.1, C26.1, C27.1, C28.1, C30.2, C31.1, C32.1, D4.1 (K), J13.2, J13.3, J22.2 (Ext), R41.1, R55.1, U6.3 (GND), U301.3 (+), U301.5 (+); also elsewhere on the board
unnamed: C11.1, D9.1, D10.3, U301.1
unnamed: C11.2, D10.1, R15.1, R16.2
unnamed: D4.2 (A), Q8.1 (E), R20.1
unnamed: D8.3, R42.1, R43.2
unnamed: J13.1, J22.1 (In), J24.1 (Pin_1_1), R12.2
unnamed: Q8.2 (B), Q8.5 (B), Q8.6 (C), R21.2
unnamed: R12.1, R47.2, U9.7
unnamed: R17.1, R22.2, U301.7
unnamed: R23.2, U6.2
unnamed: R34.2, U6.8
unnamed: R41.2, R43.1, U9.3 (+)
unnamed: R14.2, U9.1, U9.2 (-)
unnamed: C15.1, U6.1, U9.5 (+)
unnamed: R47.1, R55.2, U9.6 (-)
unnamed: R34.1, U10.1, U10.2 (-)
unnamed: R23.1, U10.6 (-), U10.7
unnamed: D9.3, R14.1, R15.2, U301.2 (-)
unnamed: R16.1, R17.2, U301.6 (-)
Siff-Out: R42.2, TP1.1 (1_1); also elsewhere on the board
genlock_black: U10.5 (+); also elsewhere on the board
siff~sync: U6.6; also elsewhere on the board

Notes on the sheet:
0-1V
filter out little spikes while dg419 is switching
0-0.7V


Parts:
C4, C8, C9, C33, C39: 100n; C_0603_1608Metric; LCSC C14663
C5: 10p; C_0603_1608Metric; LCSC C1634
C6: 470p; C_0603_1608Metric; LCSC C1620
C25: 1n; C_0603_1608Metric; LCSC C1588
J11: umcc; TE_UMCC_2337019-1; LCSC C5137195
J21: Subcarrier4x; TestPoint_THTPad_D4.0mm_Drill2.0mm
Q1: MMBT2222A; SOT-23; LCSC C8512
R5: 22k; R_0603_1608Metric; LCSC C31850
R6, R24, R25, R33, R35: 4k7; R_0603_1608Metric; LCSC C23162
R7: 47k; R_0603_1608Metric; LCSC C25819
R8: 15k; R_0603_1608Metric; LCSC C22809
R28, R32: 75; R_0603_1608Metric; LCSC C4275
U4: MC44144; SOIC-8_3.9x4.9mm_P1.27mm
U12: LMH6643; VSSOP-8_3x3mm_P0.65mm; LCSC C478382
Y1: 17.734475Mhz; Crystal_SMD_HC49-SD; LCSC C22464815

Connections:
4fsc: R28.2; also elsewhere on the board
+5V: C9.1, C33.2, R6.1, U4.8 (VCC), U12.8 (V+); also elsewhere on the board
-5V: C39.2, U12.4 (V-); also elsewhere on the board
/video_input_bufferd: C4.1; also elsewhere on the board
GND: C5.1, C6.2, C8.2, C9.2, C33.1, C39.1, J11.2, J11.3, Q1.2 (E), R8.2, R25.2, R35.2, U4.2 (GND); also elsewhere on the board
unnamed: C5.2, Y1.1
unnamed: C8.1, R7.2
unnamed: J11.1, J21.1 (Pin_1_1), R32.2
unnamed: Q1.1 (B), R5.2
unnamed: Q1.3 (C), R6.2, U4.7 (BurstIn)
unnamed: R24.1, R28.1, U12.7
unnamed: R32.1, R33.1, U12.1
unnamed: C6.1, R7.1, U4.3 (PD-OUT)
unnamed: C25.1, U4.5 (SC-OUT4x)
unnamed: C4.2, U4.6 (VideoIn)
unnamed: U4.4 (XTAL_4x), Y1.2
unnamed: C25.2, R8.1, U12.3 (+), U12.5 (+)
unnamed: R33.2, R35.1, U12.2 (-)
unnamed: R24.2, R25.1, U12.6 (-)
~porch: R5.1; also elsewhere on the board



Board: 4 copper layers, 41.9 x 98.4 mm, 124 parts (12 on the bottom side), 83 nets.

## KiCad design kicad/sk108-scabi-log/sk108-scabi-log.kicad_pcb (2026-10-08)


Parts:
C1, C2: 10uTantal; CP_EIA-3216-18_Kemet-A; LCSC C7171
C3, C5, C7, C8, C9, C10, C12, C13: 100n; C_0603_1608Metric; LCSC C14663
C4, C6: 4u7; C_0805_2012Metric; LCSC C1779
C11: 100p; C_0603_1608Metric; LCSC C14858
D1, D2, D3: BAT54S; SOT-23; LCSC C8592
FB1, FB2: Ferrite_Bead; L_0805_2012Metric; LCSC C1017
J2: Bias_In; Banana2mm-Löthülse
J4: In; Banana2mm-Löthülse
J5: Out; Banana2mm-Löthülse
J6: Conn_01x03; JST_PH_B3B-PH-SM4-TB_1x03-1MP_P2.00mm_Vertical; LCSC C18077900
J7: Scale_In; Banana2mm-Löthülse
N1: Housing_Pad; Frontplate_20mm
Q3: BC857BS; SOT-363_SC-70-6_Handsoldering; LCSC C22381405
R1, R14, R15, R21: 100; R_0603_1608Metric; LCSC C22775
R2, R3, R16, R28, R29, R31, R32: 10k; R_0603_1608Metric; LCSC C25804
R5, R7, R17, R23, R27: 15k; R_0603_1608Metric; LCSC C22809
R11: 300; R_0603_1608Metric; LCSC C23025
R12: 560; R_0603_1608Metric; LCSC C23204
R13, R18, R19, R26: 1k; R_0603_1608Metric; LCSC C21190
R20: 75; R_0603_1608Metric; LCSC C4275
R22: 100k; R_0603_1608Metric; LCSC C25803
R24: 4k7; R_0603_1608Metric; LCSC C23162
R25: 470k; R_0603_1608Metric; LCSC C23178
R30: 3k3; R_0603_1608Metric; LCSC C22978
RV1, RV2: 10k; Alps_RK097_Frontplate; LCSC C25804
U1, U5: LMH6643; VSSOP-8_3x3mm_P0.65mm; LCSC C478382
U2: LT1228; SOIC-8_3.9x4.9mm_P1.27mm
U3: LOGO; logo_anyma
U4: LOGO; OSHW-Logo2_7.3x6mm_SilkScreen

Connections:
+5V: C1.1, C4.1, C5.2, C8.2, C12.2, D1.2, D2.2, D3.2, FB1.2, RV1.3, RV2.3, U1.8 (V+), U2.7 (Vcc), U5.8 (V+)
-5V: C2.2, C6.2, C7.2, C9.2, C13.2, D1.1, D2.1, D3.1, FB2.2, R27.2, RV1.1, RV2.1, U1.4 (V-), U2.4 (Vss), U5.4 (V-)
/levelmeter: R13.1, R20.2, U2.6 (Vout)
GND: C1.2, C2.1, C3.1, C4.2, C5.1, C6.1, C7.1, C8.1, C9.1, C10.1, C12.1, C13.1, J6.2, J6.MP, N1.1 (PAD_1), Q3.5 (B), R5.1, R11.1, R12.1, R14.1, R17.1, R19.1, R23.1, R28.1, U1.3 (+), U1.5 (+), U5.3 (+)
unnamed: C3.2, R7.1, RV1.2
unnamed: C10.2, R25.1, RV2.2
unnamed: D1.3, R1.2, R2.1
unnamed: D2.3, R15.2, R16.1
unnamed: D3.3, R21.2, R22.1
unnamed: J2.1 (Pin_1_1), R1.1, R5.2
unnamed: J4.1 (Pin_1_1), R15.1, R17.2
unnamed: J5.1 (Pin_1_1), R20.1
unnamed: FB1.1, J6.1
unnamed: FB2.1, J6.3
unnamed: J7.1 (Pin_1_1), R21.1, R23.2
unnamed: Q3.2 (B), R24.2, U1.1
unnamed: Q3.6 (C), R18.2
unnamed: Q3.1 (E), Q3.4 (E), R26.1
unnamed: C11.2, Q3.3 (C), R27.1, U1.6 (-)
unnamed: R22.2, R24.1, R25.2, U1.2 (-)
unnamed: C11.1, R26.2, U1.7
unnamed: R16.2, R19.2, U2.3 (+In)
unnamed: R12.2, U2.2 (-In)
unnamed: R13.2, R14.2, U2.8 (Gain)
unnamed: R11.2, R29.2, R30.2, U2.1 (Iout)
unnamed: R18.1, U2.5 (Iset)
unnamed: R2.2, R3.1, R7.2, U5.2 (-)
unnamed: R3.2, R31.1, U5.1
unnamed: R28.2, R29.1, U5.5 (+)
unnamed: R31.2, R32.1, U5.6 (-)
unnamed: R30.1, R32.2, U5.7

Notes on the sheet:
scale section
Bias section



Board: 2 copper layers, 20.0 x 128.5 mm, 59 parts (50 on the bottom side), 31 nets.

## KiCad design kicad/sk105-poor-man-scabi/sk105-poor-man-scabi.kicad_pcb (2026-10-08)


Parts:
C1, C2, C5, C6, C7: 100n; C_0402_1005Metric; LCSC C1525
C3, C4: 10u; C_0805_2012Metric; LCSC C15850
D1: BAT54S; SOT-23; LCSC C8592
FB1, FB2: Ferrite_Bead; L_0805_2012Metric; LCSC C1017
J1: Input; Banana2mm-Löthülse
J2: Output; Banana2mm-Löthülse
J4: Conn_01x03; JST_PH_B3B-PH-SM4-TB_1x03-1MP_P2.00mm_Vertical; LCSC C18077900
J5: NegOut; Banana2mm-Löthülse
N1: Housing_Pad; Frontplate_15mm
Q1: MMBT2907A; SOT-23_BEC; LCSC C40752
R1: 12k; R_0603_1608Metric; LCSC C22790
R2: 5k1; R_0603_1608Metric; LCSC C23186
R3, R5, R6, R11: 75; R_0603_1608Metric; LCSC C4275
R4, R7, R8, R9, R12, R13: 1k; R_0603_1608Metric; LCSC C21190
R10: 2k2; R_0603_1608Metric; LCSC C4190
RV2, RV3: 10k; Alps_RK097_Frontplate
U1, U2: LMH6643; SOIC-8_3.9x4.9mm_P1.27mm; LCSC C44880

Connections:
+5V: C1.2, C3.1, C5.2, D1.2, FB1.2, R10.2, RV2.1 (L), U1.8 (V+), U2.8 (V+)
-5V: C2.2, C4.2, C6.2, D1.1, FB2.2, R2.1, U1.4 (V-), U2.4 (V-)
GND: C1.1, C2.1, C3.2, C4.1, C5.1, C6.1, C7.1, J4.2, J4.MP, N1.1 (PAD_1), R1.1, R9.1, RV2.3, RV3.1 (L), U2.3 (+), U2.5 (+)
unnamed: C7.2, Q1.B, RV2.2
unnamed: D1.3, R3.1, R5.2
unnamed: J1.1 (Pin_1_1), R1.2, R3.2
unnamed: J2.1 (Pin_1_1), R6.1
unnamed: FB1.1, J4.1
unnamed: FB2.1, J4.3
unnamed: J5.1 (Pin_1_1), R11.1
unnamed: Q1.E, R10.1
unnamed: R4.2, RV3.3, U1.1
unnamed: R8.2, R11.2, R12.1, U2.1
unnamed: R6.2, R13.2, U2.7
unnamed: R5.1, U1.3 (+)
unnamed: R4.1, R9.2, U1.2 (-)
unnamed: RV3.2, U1.5 (+)
unnamed: R7.1, U1.6 (-), U1.7
unnamed: Q1.C, R2.2, R7.2, R8.1, U2.2 (-)
unnamed: R12.2, R13.1, U2.6 (-)

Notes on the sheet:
Note pot sense! Output at 5V corresponds to most negative bias



Board: 2 copper layers, 128.5 x 15.0 mm, 33 parts (6 on the bottom side), 20 nets.

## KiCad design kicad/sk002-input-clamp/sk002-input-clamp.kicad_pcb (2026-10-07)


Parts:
C3, C9: 10uTantal; CP_EIA-3216-18_Kemet-A; LCSC C7171
C4, C5, C6, C7, C10, C11, C12, C22: 100n; C_0603_1608Metric; LCSC C14663
C8: 22n; C_0603_1608Metric; LCSC C21122
D1: BAT54S; SOT-23; LCSC C7420333
D2: LED; LED_0805_2012Metric; LCSC C2296
FB1, FB2: Ferrite_Bead; L_0805_2012Metric; LCSC C1017
J2: Power; Molex_KK-254_AE-6410-03A_1x03_P2.54mm_Vertical
J3: Conn_01x03; Hirose_DF13-03P-1.25DSA_1x03_P1.25mm_Vertical; LCSC C293633
J4: Conn_01x04_Socket; PinHeader_1x04_P2.54mm_Vertical
J5: OUT; TestPoint_THTPad_D4.0mm_Drill2.0mm
J6: Video In; BNC_Aliexpress
J7: Termination; PinHeader_1x02_P2.54mm_Vertical
J8: Conn_01x02; PinHeader_1x02_P2.54mm_Vertical
J9: UMCC; TE_UMCC_2337019-1; LCSC C5137195
J10: Conn_01x06; PinHeader_1x06_P2.54mm_Vertical
J11: Conn_01x04; PinHeader_1x04_P2.54mm_Vertical
Q1: MMBT2222A; SOT-23; LCSC C8512
R1, R2, R4, R8, R9: 75; R_0603_1608Metric; LCSC C4275
R3, R10: 2k2; R_0603_1608Metric; LCSC C4190
R5: 680k; R_0603_1608Metric; LCSC C25822
R6, R11, R12, R13, R14, R15, R16: 1k2; R_0603_1608Metric; LCSC C22765
R7: 2k7; R_0603_1608Metric; LCSC C13167
SW2: SW_SPDT; CUS-12TB_NDC; LCSC C109335
TP1: Clamped; TestPoint_Pad_2.0x2.0mm
TP2: Led; TestPoint_Pad_D1.0mm
U1: LMH6643; VSSOP-8_3x3mm_P0.65mm; LCSC C478382
U2: LM1881; SOIC-8_3.9x4.9mm_P1.27mm; LCSC C518922
U5: SN74AHC74DR; SOIC-14_3.9x8.7mm_P1.27mm; LCSC C7621
U9: 4053; SOIC-16_3.9x9.9mm_P1.27mm; LCSC C7500846

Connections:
+5V: C3.1, C4.2, C10.1, C11.2, C22.1, D1.2, D2.2 (A), FB1.2, J8.1, R14.2, R16.2, U1.8 (V+), U2.8 (VCC), U5.10 (~S), U5.12 (D), U5.14 (VCC), U9.16 (VDD)
-5V: C6.1, C9.2, C12.1, D1.1, FB2.2, U1.4 (V-), U9.7 (VEE)
/in_clamped: C8.1, TP1.1 (1_1), U9.1 (Y1), U9.12 (X0)
/localSiff~sync: U5.9 (Q), U9.10 (B)
/~backporch: J4.3, U2.5 (BPOUT), U5.11 (C), U9.11 (A)
/~hsync: J4.1, U2.1 (CSOUT), U5.13 (~R)
/~vsync: J4.2, R3.1, TP2.1 (1_1), U2.3 (VSOUT)
GND: C3.2, C4.1, C6.2, C7.2, C9.1, C10.2, C11.1, C12.2, C22.2, J2.2, J3.2, J3.MP, J6.2 (Ext), J9.2, J9.3, Q1.2 (E), R5.2, R7.2, R8.2, R11.1, R12.1, R13.1, R15.1, U2.4 (GND), U5.7 (GND), U9.2 (Y0), U9.6 (~E), U9.8 (VSS), U9.13 (X1), U9.14 (X)
unnamed: C8.2, R9.1
unnamed: D1.3, R1.2, R2.1
unnamed: D2.1 (K), J8.2, R10.1
unnamed: FB1.1, J2.1, J3.1
unnamed: FB2.1, J2.3, J3.3
unnamed: J4.4, U2.7 (OEOUT)
unnamed: J5.1 (Pin_1_1), R4.2
unnamed: J6.1 (In), J7.1, J9.1, R1.1, SW2.1 (A)
unnamed: J7.2, R8.1, SW2.2 (B)
unnamed: J10.1, R16.1, U5.1 (~R)
unnamed: J10.2, U5.2 (D)
unnamed: J10.3, R15.2, U5.3 (C)
unnamed: J10.4, R14.1, U5.4 (~S)
unnamed: J10.5, U5.5 (Q)
unnamed: J10.6, U5.6 (~Q)
unnamed: J11.1, R12.2, U9.5 (Z0)
unnamed: J11.2, U9.4 (Z)
unnamed: J11.3, R13.2, U9.3 (Z1)
unnamed: J11.4, R11.2, U9.9 (C)
unnamed: Q1.1 (B), R3.2
unnamed: Q1.3 (C), R10.2
unnamed: R4.1, R6.2, U1.7
unnamed: R2.2, U1.3 (+)
unnamed: C5.2, R9.2, U1.1, U1.2 (-)
unnamed: U1.5 (+), U9.15 (Y)
unnamed: R6.1, R7.1, U1.6 (-)
unnamed: C5.1, U2.2 (CVIN)
unnamed: C7.1, R5.1, U2.6 (RSET)

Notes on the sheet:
~{CLR}
ADD GAIN OF 1V/0.7V = 1.428
~{PRE}
So Signal is true 0-1V



Board: 2 copper layers, 41.9 x 33.6 mm, 49 parts (3 on the bottom side), 36 nets.

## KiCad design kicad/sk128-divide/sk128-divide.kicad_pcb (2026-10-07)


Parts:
C1, C2, C4, C7, C9: 100n; C_0603_1608Metric; LCSC C14663
C3: 10u; C_0805_2012Metric; LCSC C15850
FB1, FB2: Ferrite_Bead; L_0805_2012Metric; LCSC C1017
J1: Power; Molex_KK-254_AE-6410-03A_1x03_P2.54mm_Vertical_SMD
J2, J3: Clock In; Banana2mm-Löthülse
J15: Conn_01x03; Molex_PicoBlade_53398-0371_1x03-1MP_P1.25mm_Vertical; LCSC C293633
N1: Housing_Pad; Frontplate_20mm
R1: 1k; R_0603_1608Metric; LCSC C21190
R2: 47k; R_0603_1608Metric; LCSC C25819
R3, R4, R7: 12k; R_0603_1608Metric; LCSC C22790
R5, R8: 2k2; R_0603_1608Metric; LCSC C4190
R6, R43: 100k; R_0603_1608Metric; LCSC C25803
R9, R10: 75; R_0603_1608Metric; LCSC C4275
TP1: Vref; TestPoint_Pad_D1.0mm
TP2, TP3: Comp2Out; TestPoint_Pad_D1.0mm
U1: CJ; SOT-23; LCSC C3113
U2, U4: TLV3201; SOT-23-5; LCSC C105188
U3: 4040; SOIC-16_3.9x9.9mm_P1.27mm; LCSC C22390247

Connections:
0.5V_VRef: C2.1, R2.2, R3.1, TP1.1 (1_1), U2.4 (-), U4.4 (-)
+5V: C3.1, C4.2, C7.2, C9.2, FB1.2, FB2.2, R1.1, U2.5 (V+), U3.16 (VDD), U4.5 (V+); also elsewhere on the board
/2V5: C1.1, R1.2, R2.1, U1.1 (R), U1.2 (K)
/Output2/in: U3.6 (Q2); also elsewhere on the board
/Output3/in: U3.5 (Q3); also elsewhere on the board
/Output4/in: U3.3 (Q4); also elsewhere on the board
/Output5/in: U3.2 (Q5); also elsewhere on the board
/Output6/in: U3.4 (Q6); also elsewhere on the board
/Output7/in: U3.13 (Q7); also elsewhere on the board
/Output8/in: U3.12 (Q8); also elsewhere on the board
/Output9/in: U3.14 (Q9); also elsewhere on the board
/Output/in: U3.9 (Q0); also elsewhere on the board
/q1: U3.7 (Q1); also elsewhere on the board
GND: C1.2, C2.2, C3.2, C4.1, C7.1, C9.1, J1.2, J15.2, J15.MP, N1.1 (PAD_1), R3.2, R4.1, R7.1, U1.3 (A), U2.2 (V-), U3.8 (VSS), U4.2 (V-); also elsewhere on the board
unnamed: FB1.1, J1.1
unnamed: J2.1 (Pin_1_1), R7.2, R8.2
unnamed: J3.1 (Pin_1_1), R4.2, R5.2
unnamed: FB2.1, J15.1
unnamed: R6.1, R10.2, U2.1
unnamed: R9.2, R43.1, U4.1
unnamed: R5.1, R6.2, U2.3 (+)
unnamed: R9.1, TP3.1 (1_1), U3.10 (CLK)
unnamed: R10.1, TP2.1 (1_1), U3.11 (Reset)
unnamed: R8.1, R43.2, U4.3 (+)

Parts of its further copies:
R18: 2k2; R_0603_1608Metric; LCSC C4190

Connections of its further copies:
unnamed 15: R18.1; also elsewhere on the board
unnamed 41: R18.2; also elsewhere on the board


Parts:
D1: LED; LED_1206_3216Metric_ReverseMount_Hole1.8x2.4mm; LCSC C125108
J4: OUT; Banana2mm-Löthülse
Q1: MMBT2222A; SOT-23; LCSC C8512
R13: 75; R_0603_1608Metric; LCSC C4275
R14, R15: 2k2; R_0603_1608Metric; LCSC C4190

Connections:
+5V: D1.2 (A); also elsewhere on the board
/Output/in: R13.2, R14.1; also elsewhere on the board
GND: Q1.2 (E); also elsewhere on the board
unnamed: D1.1 (K), R15.1
unnamed: J4.1 (Pin_1_1), R13.1
unnamed: Q1.1 (B), R14.2
unnamed: Q1.3 (C), R15.2

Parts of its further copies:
D2, D3, D4, D5, D6, D7, D8, D9, D10: LED; LED_1206_3216Metric_ReverseMount_Hole1.8x2.4mm; LCSC C125108
J5, J6, J7, J8, J9, J10, J11, J12, J13: OUT; Banana2mm-Löthülse
Q2, Q3, Q4, Q5, Q6, Q7, Q8, Q9, Q10: MMBT2222A; SOT-23; LCSC C8512
R16, R18, R19, R21, R22, R24, R25, R27, R28, R30, R31, R33, R34, R36, R37, R39, R40, R42: 2k2; R_0603_1608Metric; LCSC C4190
R17, R20, R23, R26, R29, R32, R35, R38, R41: 75; R_0603_1608Metric; LCSC C4275

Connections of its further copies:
+5V: D2.2 (A), D3.2 (A), D4.2 (A), D5.2 (A), D6.2 (A), D7.2 (A), D8.2 (A), D9.2 (A), D10.2 (A); also elsewhere on the board
/Output2/in: R22.1, R23.2; also elsewhere on the board
/Output3/in: R19.1, R20.2; also elsewhere on the board
/Output4/in: R25.1, R26.2; also elsewhere on the board
/Output5/in: R28.1, R29.2; also elsewhere on the board
/Output6/in: R31.1, R32.2; also elsewhere on the board
/Output7/in: R34.1, R35.2; also elsewhere on the board
/Output8/in: R37.1, R38.2; also elsewhere on the board
/Output9/in: R40.1, R41.2; also elsewhere on the board
/q1: R16.1, R17.2; also elsewhere on the board
GND: Q2.2 (E), Q3.2 (E), Q4.2 (E), Q5.2 (E), Q6.2 (E), Q7.2 (E), Q8.2 (E), Q9.2 (E), Q10.2 (E); also elsewhere on the board
unnamed: D2.1 (K), R18.1
unnamed: D3.1 (K), R21.1
unnamed: D4.1 (K), R24.1
unnamed: D5.1 (K), R27.1
unnamed: D6.1 (K), R30.1
unnamed: D7.1 (K), R33.1
unnamed: D8.1 (K), R36.1
unnamed: D9.1 (K), R39.1
unnamed: D10.1 (K), R42.1
unnamed: J5.1 (Pin_1_1), R17.1
unnamed: J6.1 (Pin_1_1), R20.1
unnamed: J7.1 (Pin_1_1), R23.1
unnamed: J8.1 (Pin_1_1), R26.1
unnamed: J9.1 (Pin_1_1), R29.1
unnamed: J10.1 (Pin_1_1), R32.1
unnamed: J11.1 (Pin_1_1), R35.1
unnamed: J12.1 (Pin_1_1), R38.1
unnamed: J13.1 (Pin_1_1), R41.1
unnamed: Q2.1 (B), R16.2
unnamed: Q2.3 (C), R18.2
unnamed: Q3.1 (B), R19.2
unnamed: Q3.3 (C), R21.2
unnamed: Q4.1 (B), R22.2
unnamed: Q4.3 (C), R24.2
unnamed: Q5.1 (B), R25.2
unnamed: Q5.3 (C), R27.2
unnamed: Q6.1 (B), R28.2
unnamed: Q6.3 (C), R30.2
unnamed: Q7.1 (B), R31.2
unnamed: Q7.3 (C), R33.2
unnamed: Q8.1 (B), R34.2
unnamed: Q8.3 (C), R36.2
unnamed: Q9.1 (B), R37.2
unnamed: Q9.3 (C), R39.2
unnamed: Q10.1 (B), R40.2
unnamed: Q10.3 (C), R42.2



Board: 2 copper layers, 20.0 x 128.5 mm, 91 parts (13 on the bottom side), 64 nets.

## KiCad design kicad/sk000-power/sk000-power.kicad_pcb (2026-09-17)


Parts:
C1, C2: CP_Small; C_1206_3216Metric_Pad1.42x1.75mm_HandSolder; LCSC C13585
D1, D4: LED; LED_1206_3216Metric_ReverseMount_Hole1.8x2.4mm; LCSC C125108
F1, F2: Polyfuse; L_1206_3216Metric_Pad1.42x1.75mm_HandSolder; LCSC C22378342
J1: Conn_01x03; Molex_PicoBlade_53398-0371_1x03-1MP_P1.25mm_Vertical; LCSC C293633
J2: bundeshülse
J3: gnd; Banana2mm-Löthülse
J4: Conn_01x03; Molex_KK-254_AE-6410-03A_1x03_P2.54mm_Vertical
J5: Conn_01x03; Hirose_DF13-03P-1.25DSA_1x03_P1.25mm_Vertical
J6: +; Banana2mm-Löthülse
J7: -; Banana2mm-Löthülse
N1: Housing; Frontplate_10mm
R1, R2: 2k; R_0805_2012Metric_Pad1.15x1.40mm_HandSolder; LCSC C17604

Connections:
+5V: C1.1, D4.2 (A), F1.1, J4.1, J5.1, J6.1 (Pin_1_1)
-5V: C2.2, D1.1 (K), F2.1, J4.3, J5.3, J7.1 (Pin_1_1)
GND: C1.2, C2.1, J1.2, J1.MP, J2.1 (Pin_1_1), J3.1 (Pin_1_1), J4.2, J5.2, R1.2, R2.1
unnamed: D1.2 (A), R2.2
unnamed: D4.1 (K), R1.1
VCC: F1.2, J1.1
VDD: F2.2, J1.3



Board: 2 copper layers, 10.0 x 128.5 mm, 16 parts (9 on the bottom side), 7 nets.

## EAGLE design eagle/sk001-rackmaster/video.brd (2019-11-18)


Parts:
C1, C2, C4, C24, C25, C27, C32, C33, C35, C40, C41, C43: 1u; C0805
C3, C5, C6, C7, C8, C9, C10, C12, C13, C14, C15, C18, C19, C20, C22, C23, C26, C28, C29, C30, C34, C36, C37, C38, C42, C44, C45, C46, C48, C49, C51, C52: 100n; C0805
C11: 470p; C0805
C17: 120p; C0805
C54, C55: CPOL-EUCT3528; CT3528
D1, D3, D6, D7, D9, D11, D13, D16: DIODE_2CACA-SOT23; SOT23
IC1, IC2: LM833D; SO08
IC3: 4053D; SO16
IC4: 4011D; SO14
JP1, JP2, JP3, JP4: PINHD-1X2; 1X02
LED_VIN1, LED_VIN2, LED_VIN3, LED_VIN4: 3,17/1,1
R1, R4, R5, R6, R7, R8, R9, R16, R18, R19, R21, R22, R24, R25, R31, R41, R42, R43: 75; R0805
R2: 680k; R0805
R3, R12, R17, R20, R23, R28, R34: 120; R0805
R10, R26, R32: 10k; R0805
R11, R27, R33, R44: 1k2; R0805
R13, R14, R29, R30, R35, R36: 200; R0805
R15: 2k2; R0805
R37, R38, R39, R40: 300; R0805
R45: 560; R0805
R_TBOT: 500; RTRIM64Y
R_TTOP: 500; RTRIM64Y
SIFF_IN1, SIFF_IN2, SIFF_IN3, SIFF_IN4: 3,17/1,1
SIFF_OUT1, SIFF_OUT2, SIFF_OUT3: 3,17/1,1
T1, T2, T3, T4, T10, T12, T14: TRANS-PNPSOT23-BEC; SOT23-BEC
T5, T6, T7, T8, T9, T11, T13: TRANS-NPN; SOT23-BEC
TO-PHASE-DELAY: 22-23-2021
U1, U5, U7, U9: MAX7450; SO08-EXP
U2: LM1881SO8; SO08
U3, U4, U6, U8, U10, U11, U12: MAX4392ESA; SO08
VIDEO_IN1, VIDEO_IN2, VIDEO_IN3, VIDEO_IN4: 3,17/1,1
VIDEO_OUT1, VIDEO_OUT2, VIDEO_OUT3: 3,17/1,1
X1: CON-SYNCBUS; 22-23-2041
X2: CON-POWER; 22-23-2031
X4: 22-23-2021

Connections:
0V: C2.1, C3.1, C4.1, C5.1, C7.1, C8.1, C9.2, C10.2, C11.2, C12.2, C13.2, C14.2, C15.2, C17.1, C18.2, C19.2, C20.2, C22.2, C23.2, C25.1, C26.1, C27.1, C28.1, C29.2, C30.2, C33.1, C34.1, C35.1, C36.1, C37.2, C38.2, C41.1, C42.1, C43.1, C44.1, C45.2, C46.2, C48.2, C49.2, C51.2, C52.2, C54.+, C55.-, IC3.6 (INH), IC3.8 (GND), IC4.7 (VSS), IC4.12 (I0), IC4.13 (I1), R1.1, R2.1, R10.1, R13.1, R16.1, R19.1, R22.1, R26.1, R29.1, R32.1, R35.1, T1.C, T2.C, T3.C, T4.C, TO-PHASE-DELAY.1, U1.3 (GND), U1.7 (GSET), U2.4 (GND), U5.3 (GND), U5.7 (GSET), U7.3 (GND), U7.7 (GSET), U9.3 (GND), U9.7 (GSET), X2.2, X4.1
+5V: C4.2, C5.2, C7.2, C9.1, C12.1, C14.1, C18.1, C20.1, C22.1, C27.2, C28.2, C29.1, C35.2, C36.2, C37.1, C43.2, C44.2, C45.1, C48.1, C51.1, C55.+, D1.2 (C), D3.2 (C), D7.2 (C), D9.2 (C), D11.2 (C), D13.2 (C), D16.2 (C), IC1.8 (V+), IC2.8 (V+), IC3.16 (VCC), IC4.14 (VDD), R11.1, R27.1, T5.C, T6.C, T7.C, T8.C, T9.C, T11.C, T13.C, U1.1 (VCC), U1.5 (AGCD), U2.8 (VCC), U3.8 (+5V), U4.8 (+5V), U5.1 (VCC), U5.5 (AGCD), U6.8 (+5V), U7.1 (VCC), U7.5 (AGCD), U8.8 (+5V), U9.1 (VCC), U9.5 (AGCD), U10.8 (+5V), U11.8 (+5V), U12.8 (+5V), X2.3
-5V: C2.2, C3.2, C10.1, C13.1, C15.1, C19.1, C23.1, C25.2, C26.2, C30.1, C33.2, C34.2, C38.1, C41.2, C42.2, C46.1, C49.1, C52.1, C54.-, D1.1 (A), D3.1 (A), D7.1 (A), D9.1 (A), D11.1 (A), D13.1 (A), D16.1 (A), IC1.4 (V-), IC2.4 (V-), IC3.7 (VEE), R33.2, R44.2, T10.C, T12.C, T14.C, U1.4 (VSS), U1.EXP (VSS), U3.4 (-5V), U4.4 (-5V), U5.4 (VSS), U5.EXP (VSS), U6.4 (-5V), U7.4 (VSS), U7.EXP (VSS), U8.4 (-5V), U9.4 (VSS), U9.EXP (VSS), U10.4 (-5V), U11.4 (-5V), U12.4 (-5V), X2.1
H: IC2.5 (+IN), IC4.1 (I0), U2.1 (SYNC)
unnamed: IC3.4 (Z), U4.5 (+IN)
unnamed: JP2.2, R1.2
unnamed: C6.2, U2.2 (INPUT)
unnamed: C8.2, R2.2, U2.6 (R_SET)
unnamed: C1.2, U1.2 (IN)
unnamed: IC1.1 (OUT), IC1.2 (-IN), R5.2
unnamed: R45.2, TO-PHASE-DELAY.2, U1.6 (OUT), U3.3 (+IN)
unnamed: R3.1, U3.1 (OUT), U3.2 (-IN)
unnamed: R3.2, T8.E, U3.5 (+IN)
unnamed: R4.1, U3.6 (-IN), U3.7 (OUT)
unnamed: R4.2, SIFF_IN1.1
unnamed: IC1.6 (-IN), IC1.7 (OUT), R6.2
unnamed: IC2.1 (OUT), IC2.2 (-IN), R7.2
unnamed: IC2.6 (-IN), IC2.7 (OUT), R8.2
unnamed: R6.1, X1.2
unnamed: R5.1, X1.1
unnamed: R7.1, X1.3
unnamed: R8.1, X1.4
unnamed: C6.1, C11.1, R45.1
unnamed: IC1.5 (+IN), IC4.2 (I1), U2.5 (BURST)
unnamed: IC2.3 (+IN), IC4.8 (I0), U2.3 (VERT)
unnamed: R9.1, R10.2, SIFF_OUT1.1
unnamed: D3.3 (AC), R9.2, U4.3 (+IN)
unnamed: R12.1, U4.1 (OUT), U4.2 (-IN)
unnamed: IC3.5 (Z0), R12.2, T13.E, T14.E
unnamed: R27.2, R_TBOT.3 (E)
unnamed: R13.2, R14.1, U4.6 (-IN)
unnamed: C1.1, D1.3 (AC), JP2.1, VIDEO_IN1.1
unnamed: R14.2, R41.1, U4.7 (OUT)
unnamed: IC4.4 (O), IC4.9 (I1)
unnamed: D6.1 (A), IC4.3 (O), R15.1
unnamed: C17.2, D6.2 (C), D6.3 (AC), IC4.5 (I0), IC4.6 (I1), R15.2
unnamed: JP1.2, R16.2
unnamed: R25.1, R26.2, SIFF_OUT2.1
unnamed: C24.2, U5.2 (IN)
unnamed: U5.6 (OUT), U6.3 (+IN)
unnamed: R17.1, U6.1 (OUT), U6.2 (-IN)
unnamed: R17.2, T7.E, U6.5 (+IN)
unnamed: R18.1, U6.6 (-IN), U6.7 (OUT)
unnamed: R18.2, SIFF_IN2.1
unnamed: C24.1, D7.3 (AC), JP1.1, VIDEO_IN2.1
unnamed: JP3.2, R19.2
unnamed: C32.2, U7.2 (IN)
unnamed: U7.6 (OUT), U8.3 (+IN)
unnamed: R20.1, U8.1 (OUT), U8.2 (-IN)
unnamed: R20.2, T6.E, U8.5 (+IN)
unnamed: R21.1, U8.6 (-IN), U8.7 (OUT)
unnamed: R21.2, SIFF_IN3.1
unnamed: C32.1, D9.3 (AC), JP3.1, VIDEO_IN3.1
unnamed: JP4.2, R22.2
unnamed: C40.2, U9.2 (IN)
unnamed: U9.6 (OUT), U10.3 (+IN)
unnamed: R23.2, U10.1 (OUT), U10.2 (-IN)
unnamed: R23.1, T5.E, U10.5 (+IN)
unnamed: R24.1, U10.6 (-IN), U10.7 (OUT)
unnamed: R24.2, SIFF_IN4.1
unnamed: C40.1, D11.3 (AC), JP4.1, VIDEO_IN4.1
unnamed: IC3.9 (C), IC3.10 (B), IC3.11 (A), IC4.10 (O)
unnamed: D13.3 (AC), R25.2, U11.3 (+IN)
unnamed: R28.1, U11.1 (OUT), U11.2 (-IN)
unnamed: R_TTOP.2 (S), T10.B, T12.B, T14.B
unnamed: R33.1, R_TBOT.1 (A)
unnamed: R29.2, R30.1, U11.6 (-IN)
unnamed: R30.2, R42.1, U11.7 (OUT)
unnamed: IC3.15 (Y), U11.5 (+IN)
unnamed: R31.1, R32.2, SIFF_OUT3.1
unnamed: D16.3 (AC), R31.2, U12.3 (+IN)
unnamed: R34.1, U12.1 (OUT), U12.2 (-IN)
unnamed: IC3.12 (X0), R34.2, T9.E, T10.E
unnamed: R11.2, R_TTOP.3 (E)
unnamed: R35.2, R36.1, U12.6 (-IN)
unnamed: R36.2, R43.1, U12.7 (OUT)
unnamed: IC3.14 (X), U12.5 (+IN)
unnamed: R37.1, T1.E
unnamed: LED_VIN1.1, R37.2
unnamed: T1.B, U1.8 (LOS)
unnamed: R38.1, T2.E
unnamed: LED_VIN2.1, R38.2
unnamed: T2.B, U5.8 (LOS)
unnamed: R39.1, T3.E
unnamed: LED_VIN3.1, R39.2
unnamed: T3.B, U7.8 (LOS)
unnamed: R40.1, T4.E
unnamed: LED_VIN4.1, R40.2
unnamed: T4.B, U9.8 (LOS)
unnamed: R41.2, VIDEO_OUT1.1
unnamed: R42.2, VIDEO_OUT2.1
unnamed: R43.2, VIDEO_OUT3.1
unnamed: IC3.1 (Y1), IC3.3 (Z1), IC3.13 (X1), X4.2
unnamed: R_TBOT.2 (S), T5.B, T6.B, T7.B, T8.B, T9.B, T11.B, T13.B
unnamed: IC3.2 (Y0), R28.2, T11.E, T12.E
unnamed: R44.1, R_TTOP.1 (A)
O!E: IC1.3 (+IN), U2.7 (ODD/EVEN)

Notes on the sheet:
AC COUPLE



Board: 2 copper layers, 99.0 x 81.0 mm, 159 parts (7 on the bottom side), 97 nets.

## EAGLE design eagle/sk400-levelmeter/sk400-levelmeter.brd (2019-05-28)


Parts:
C1, C3, C4: C-EUC1206; C1206
C2: C-EUC0603; C0603
IC2: TINY85-20SU; 8S2
IC3: LM833D; SO08
IN: LSP13
ISP-GND: SMD2
ISP-MISO: SMD2
ISP-MOSI: SMD2
ISP-RESET: SMD2
ISP-SCK: SMD2
ISP-VCC: SMD2
L1, L2: LL2012C; L2012C
R1, R2, R3, R4, R5: 3k; R1206
R6: 330; R1206
U$1, U$2: SK6812MINI
X1: 22-23-2031

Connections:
+5V: C1.1, C2.1, C4.2, IC2.8 (VCC), IC3.8 (V+), ISP-VCC.1, L2.1, U$1.4 (VDD), U$2.4 (VDD)
-5V: C3.2, IC3.4 (V-), L1.1
GND: C1.2, C2.2, C3.1, C4.1, IC2.4 (GND), ISP-GND.1, R4.1, U$1.2 (GND), U$2.2 (GND), X1.2
unnamed: R6.2, U$1.3 (DI)
unnamed: IC2.6 (PB1/PCINT1/AIN1/OC0B/0C1A/MISO), ISP-MISO.1
unnamed: IC2.7 (PB2/PCINT2/SCK/ADC1/T0/INT0), ISP-SCK.1
unnamed: IC2.1 (PB5/PCINT5/!RESET!/ADC0/DW), ISP-RESET.1
unnamed: L1.2, X1.1
unnamed: L2.2, X1.3
unnamed: IC3.1 (OUT), R1.1, R2.2
unnamed: IC3.5 (+IN), IN.MP
unnamed: IC3.3 (+IN), R4.2
unnamed: IC3.2 (-IN), R2.1, R3.2
unnamed: IC2.2 (PB3/PCINT3/CLKI/ADC3), R1.2
unnamed: IC2.3 (PB4/PCINT4/0C1B/ADC2), R5.2
unnamed: U$1.1 (DO), U$2.3 (DI)
unnamed: IC2.5 (PB0/PCINT0/AIN0/OC0A/0C1A/AREF/MOSI), ISP-MOSI.1, R6.1
unnamed: IC3.6 (-IN), IC3.7 (OUT), R3.1, R5.1


Board: 2 copper layers, 24 parts (1 on the bottom side), 18 nets.

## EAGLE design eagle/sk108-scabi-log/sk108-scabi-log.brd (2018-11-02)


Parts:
BIAS_IN: 3,17/1,1
C1, C2: CPOL-EUCT3528; CT3528
C3, C5: 4u7; CT3528
C4, C6, C7, C8, C11, C12, C13, C14: 100n; C0805
C9, C16: 0; C0805
C10: 50p; C0805
C15: 1p; C0805
D1, D2, D3: DIODE_2CACA-SOT23; SOT23
IC1, IC2: DUAL_OPAMPD; SO08
IN: 3,17/1,1
OUT: 3,17/1,1
R1: 300; R0805
R2, R10, R24: 100; R0805
R3, R25: 47k; R0805
R4, R28, R29: 10k; R0805
R5: 560; R0805
R6, R8, R35: 1k; R0805
R7: 75; R0805
R9: 68; R0805
R11, R30: 4k7; R0805
R12, R13, R15, R26, R27: 100k; R0805
R14: 100k; R1206
R16, R21: 2k2; R0805
R17, R18, R20: 1M; R0805
R19: 1M; R1206
R22, R23: 20k; R0805
R31, R32, R33, R34: 33k; R0805
R36: 15k; R0805
R_BIAS: ALPS_RK09K111_HOHNE-FüSSE; ALPS_RK09K111
R_SCALE: ALPS_RK09K111_HOHNE-FüSSE; ALPS_RK09K111
SCALE_IN: 3,17/1,1
U$1: LT1228; SO08
U$2: PEMX1; SOT666
X1: CON-POWER; 22-23-2031

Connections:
0V: C1.-, C2.+, C3.+, C4.1, C5.-, C6.2, C7.2, C8.2, C11.1, C12.2, C13.2, C14.1, IC2.5 (+IN), R1.1, R3.2, R5.1, R6.1, R9.1, R11.2, R14.2, R19.2, R25.2, U$2.1 (E), X1.2
+5V: C1.+, C5.+, C6.1, C7.1, C13.1, D1.2 (C), D2.2 (C), D3.2 (C), IC1.8 (V+), IC2.8 (V+), R22.1, R28.1, R36.2, U$1.7 (VCC), X1.3
-5V: C2.-, C3.-, C4.2, C8.1, C12.1, D1.1 (A), D2.1 (A), D3.1 (A), IC1.4 (V-), IC2.4 (V-), R23.2, R29.2, U$1.4 (VSS), X1.1
unnamed: R23.1, R_BIAS.1 (S)
unnamed: IN.1, R2.2, R3.1
unnamed: D1.3 (AC), R2.1, R4.1
unnamed: R4.2, R6.2, U$1.3 (+IN)
unnamed: BIAS_IN.1, R10.2, R11.1
unnamed: R5.2, U$1.2 (-IN)
unnamed: OUT.1, R7.1
unnamed: R7.2, R8.2, U$1.6 (VOUT)
unnamed: R8.1, R9.2, U$1.8 (GAIN)
unnamed: D2.3 (AC), R10.1, R12.2
unnamed: IC1.3 (+IN), R12.1, R13.2
unnamed: C9.1, IC1.2 (-IN), R14.1, R15.2
unnamed: C9.2, IC1.1 (OUT), R15.1, R16.2
unnamed: R1.2, R13.1, R16.1, R18.1, R21.1, U$1.1 (I-OUT)
unnamed: C11.2, R17.2, R_BIAS.2 (W)
unnamed: IC1.5 (+IN), R17.1, R18.2
unnamed: C10.1, IC1.6 (-IN), R19.1, R20.2
unnamed: C10.2, IC1.7 (OUT), R20.1, R21.2
unnamed: R22.2, R_BIAS.3 (E)
unnamed: R24.2, R25.1, SCALE_IN.1
unnamed: D3.3 (AC), R24.1, R26.1
unnamed: C16.1, IC2.6 (-IN), R26.2, R27.2, R30.1
unnamed: R29.1, R_SCALE.1 (S)
unnamed: R28.2, R_SCALE.3 (E)
unnamed: C16.2, IC2.7 (OUT), R30.2, R31.1
unnamed: C15.1, IC2.2 (-IN), R31.2, R32.1
unnamed: C15.2, IC2.1 (OUT), R32.2, U$2.3 (C), U$2.5 (B)
unnamed: R35.2, U$1.5 (ISET)
unnamed: C14.2, R27.1, R_SCALE.2 (W)
unnamed: IC2.3 (+IN), R33.2, R34.1
unnamed: R33.1, R36.1, U$2.2 (B), U$2.6 (C)
unnamed: R34.2, R35.1, U$2.4 (E)



Board: 2 copper layers, 83.2 x 43.5 mm, 66 parts (3 on the bottom side), 35 nets.

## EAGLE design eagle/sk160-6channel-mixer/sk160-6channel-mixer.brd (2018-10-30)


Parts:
BUF, BUF1, BUF2, BUF3, BUF4, BUF5: LMH6643MA; SO08
C1, C2, C3, C4, C5, C6, C7, C11, C13, C14, C15, C16, C17, C18, C19, C20, C21, C22, C23, C24, C25, C26, C27, C28: C-EUC1206; C1206
C8, C9: 2u2tantal; CT6032
C10, C12: CPOL-EUCT6032; CT6032
CV-IN, CV-IN1, CV-IN2, CV-IN3, CV-IN4, CV-IN5, CV-IN6, CV-IN7, CV-IN8, CV-IN9, CV-IN10, CV-IN11: 3,17/1,1
D1, D2, D3, D4, D5, D6, D7, D8, D9, D10, D11, D12, D13, D14, D15, D16, D17, D18: BAT54S-L44; SOT23
OUT-: 3,17/1,1
R1, R2, R3, R4, R11, R12, R13, R17, R27, R32, R33, R34, R35, R37, R38, R39, R45, R53, R54, R55, R56, R58, R59, R60, R69, R74, R75, R76, R77, R79, R80, R81, R90, R95, R96, R97, R98, R100, R101, R102, R111, R116, R117, R118, R119, R121, R122, R123: 100k; R1206
R5, R29, R50, R71, R92, R113: 47k; R1206
R6, R9, R16, R22, R28, R31, R36, R49, R52, R57, R70, R73, R78, R91, R94, R99, R112, R115, R120: 1k; R1206
R7, R14, R25, R42, R47, R65, R67, R86, R88, R107, R109, R128: 4k7; R1206
R8, R10, R15, R19, R24, R26, R30, R41, R44, R46, R48, R51, R62, R64, R66, R68, R72, R83, R85, R87, R89, R93, R104, R106, R108, R110, R114, R125, R127, R129: 100; R1206
R18, R40, R61, R82, R103, R124: 1k6; R1206
R20: 300; R1206
R21: 68; R1206
R23: 75; R1206
R43, R63, R84, R105, R126: 22; R1206
SIFF-IN, SIFF-IN1, SIFF-IN2, SIFF-IN3, SIFF-IN4, SIFF-IN5: 3,17/1,1
U$1, U$2, U$3, U$4, U$5, U$6: LT1228; SO08
X1: 22-23-2031

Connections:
+5V: BUF.8 (+5V), BUF1.8 (+5V), BUF2.8 (+5V), BUF3.8 (+5V), BUF4.8 (+5V), BUF5.8 (+5V), C1.2, C3.2, C7.1, C9.+, C10.+, C11.1, C14.1, C15.2, C18.1, C19.2, C22.1, C23.2, C26.1, C27.2, D1.2 (C), D2.2 (C), D3.2 (C), D4.2 (C), D5.2 (C), D6.2 (C), D7.2 (C), D8.2 (C), D9.2 (C), D10.2 (C), D11.2 (C), D12.2 (C), D13.2 (C), D14.2 (C), D15.2 (C), D16.2 (C), D17.2 (C), D18.2 (C), U$1.7 (VCC), U$2.7 (VCC), U$3.7 (VCC), U$4.7 (VCC), U$5.7 (VCC), U$6.7 (VCC), X1.3
-5V: BUF.4 (-5V), BUF1.4 (-5V), BUF2.4 (-5V), BUF3.4 (-5V), BUF4.4 (-5V), BUF5.4 (-5V), C2.2, C4.1, C5.2, C6.1, C8.-, C12.-, C13.1, C16.2, C17.1, C20.2, C21.1, C24.2, C25.1, C28.2, D1.1 (A), D2.1 (A), D3.1 (A), D4.1 (A), D5.1 (A), D6.1 (A), D7.1 (A), D8.1 (A), D9.1 (A), D10.1 (A), D11.1 (A), D12.1 (A), D13.1 (A), D14.1 (A), D15.1 (A), D16.1 (A), D17.1 (A), D18.1 (A), U$1.4 (VSS), U$2.4 (VSS), U$3.4 (VSS), U$4.4 (VSS), U$5.4 (VSS), U$6.4 (VSS), X1.1
GND: C1.1, C2.1, C3.1, C4.2, C5.1, C6.2, C7.2, C8.+, C9.-, C10.-, C11.2, C12.+, C13.2, C14.2, C15.1, C16.1, C17.2, C18.2, C19.1, C20.1, C21.2, C22.2, C23.1, C24.1, C25.2, C26.2, C27.1, C28.1, R3.2, R5.2, R7.2, R14.2, R17.2, R19.1, R20.2, R21.2, R24.1, R25.2, R29.2, R34.2, R39.2, R41.1, R42.2, R43.2, R46.1, R47.2, R50.2, R55.2, R60.2, R62.1, R63.2, R64.1, R65.2, R67.2, R71.2, R76.2, R81.2, R83.1, R84.2, R85.1, R86.2, R88.2, R92.2, R97.2, R102.2, R104.1, R105.2, R106.1, R107.2, R109.2, R113.2, R118.2, R123.2, R125.1, R126.2, R127.1, R128.2, X1.2
unnamed: CV-IN1.1, R14.1, R15.1
unnamed: D1.3 (AC), R4.1, R15.2
unnamed: CV-IN2.1, R25.1, R26.1
unnamed: BUF.2 (-IN), R2.1, R3.1
unnamed: R9.2, R19.2, U$1.3 (+IN)
unnamed: CV-IN4.1, R42.1, R44.1
unnamed: BUF.5 (+IN), R4.2, R12.1
unnamed: BUF.7 (OUT), R6.1, R13.2
unnamed: R21.1, R22.2, U$1.8 (GAIN)
unnamed: CV-IN.1, R7.1, R10.1
unnamed: D2.3 (AC), R10.2, R11.1
unnamed: BUF.6 (-IN), R13.1, R17.1
unnamed: D3.3 (AC), R26.2, R27.1
unnamed: BUF.3 (+IN), R1.1, R11.2
unnamed: R5.1, R8.1, SIFF-IN.1
unnamed: D6.3 (AC), R8.2, R9.1
unnamed: BUF.1 (OUT), R2.2, R16.1
unnamed: R18.2, U$1.5 (ISET)
unnamed: R1.2, R6.2, R12.2, R16.2, R18.1
unnamed: R22.1, R23.1, U$1.6 (VOUT)
unnamed: OUT-.1, R23.2
unnamed: R24.2, U$1.2 (-IN)
unnamed: BUF1.3 (+IN), R27.2, R32.1
unnamed: BUF1.1 (OUT), R28.1, R33.2
unnamed: R28.2, R32.2, R36.2, R37.2, R40.1
unnamed: R29.1, R30.1, SIFF-IN1.1
unnamed: D4.3 (AC), R30.2, R31.1
unnamed: R31.2, R41.2, U$2.3 (+IN)
unnamed: BUF1.2 (-IN), R33.1, R34.1
unnamed: BUF1.5 (+IN), R35.2, R37.1
unnamed: BUF1.7 (OUT), R36.1, R38.2
unnamed: BUF1.6 (-IN), R38.1, R39.1
unnamed: R40.2, U$2.5 (ISET)
unnamed: R20.1, U$1.1 (I-OUT), U$2.1 (I-OUT), U$3.1 (I-OUT), U$4.1 (I-OUT), U$5.1 (I-OUT), U$6.1 (I-OUT)
unnamed: D7.3 (AC), R44.2, R45.1
unnamed: BUF2.3 (+IN), R45.2, R53.1
unnamed: BUF2.1 (OUT), R49.1, R54.2
unnamed: R46.2, U$2.2 (-IN)
unnamed: CV-IN3.1, R47.1, R48.1
unnamed: D5.3 (AC), R35.1, R48.2
unnamed: R49.2, R53.2, R57.2, R58.2, R61.1
unnamed: R43.1, U$2.8 (GAIN)
unnamed: R50.1, R51.1, SIFF-IN2.1
unnamed: D8.3 (AC), R51.2, R52.1
unnamed: R52.2, R62.2, U$3.3 (+IN)
unnamed: BUF2.2 (-IN), R54.1, R55.1
unnamed: BUF2.5 (+IN), R56.2, R58.1
unnamed: BUF2.7 (OUT), R57.1, R59.2
unnamed: BUF2.6 (-IN), R59.1, R60.1
unnamed: R61.2, U$3.5 (ISET)
unnamed: R64.2, U$3.2 (-IN)
unnamed: CV-IN5.1, R65.1, R66.1
unnamed: D9.3 (AC), R56.1, R66.2
unnamed: R63.1, U$3.8 (GAIN)
unnamed: CV-IN6.1, R67.1, R68.1
unnamed: D10.3 (AC), R68.2, R69.1
unnamed: BUF3.3 (+IN), R69.2, R74.1
unnamed: BUF3.1 (OUT), R70.1, R75.2
unnamed: R70.2, R74.2, R78.2, R79.2, R82.1
unnamed: R71.1, R72.1, SIFF-IN3.1
unnamed: D11.3 (AC), R72.2, R73.1
unnamed: R73.2, R83.2, U$4.3 (+IN)
unnamed: BUF3.2 (-IN), R75.1, R76.1
unnamed: BUF3.5 (+IN), R77.2, R79.1
unnamed: BUF3.7 (OUT), R78.1, R80.2
unnamed: BUF3.6 (-IN), R80.1, R81.1
unnamed: R82.2, U$4.5 (ISET)
unnamed: R85.2, U$4.2 (-IN)
unnamed: CV-IN7.1, R86.1, R87.1
unnamed: D12.3 (AC), R77.1, R87.2
unnamed: R84.1, U$4.8 (GAIN)
unnamed: CV-IN8.1, R88.1, R89.1
unnamed: D13.3 (AC), R89.2, R90.1
unnamed: BUF4.3 (+IN), R90.2, R95.1
unnamed: BUF4.1 (OUT), R91.1, R96.2
unnamed: R91.2, R95.2, R99.2, R100.2, R103.1
unnamed: R92.1, R93.1, SIFF-IN4.1
unnamed: D14.3 (AC), R93.2, R94.1
unnamed: R94.2, R104.2, U$5.3 (+IN)
unnamed: BUF4.2 (-IN), R96.1, R97.1
unnamed: BUF4.5 (+IN), R98.2, R100.1
unnamed: BUF4.7 (OUT), R99.1, R101.2
unnamed: BUF4.6 (-IN), R101.1, R102.1
unnamed: R103.2, U$5.5 (ISET)
unnamed: R106.2, U$5.2 (-IN)
unnamed: CV-IN9.1, R107.1, R108.1
unnamed: D15.3 (AC), R98.1, R108.2
unnamed: R105.1, U$5.8 (GAIN)
unnamed: CV-IN10.1, R109.1, R110.1
unnamed: D16.3 (AC), R110.2, R111.1
unnamed: BUF5.3 (+IN), R111.2, R116.1
unnamed: BUF5.1 (OUT), R112.1, R117.2
unnamed: R112.2, R116.2, R120.2, R121.2, R124.1
unnamed: R113.1, R114.1, SIFF-IN5.1
unnamed: D17.3 (AC), R114.2, R115.1
unnamed: R115.2, R125.2, U$6.3 (+IN)
unnamed: BUF5.2 (-IN), R117.1, R118.1
unnamed: BUF5.5 (+IN), R119.2, R121.1
unnamed: BUF5.7 (OUT), R120.1, R122.2
unnamed: BUF5.6 (-IN), R122.1, R123.1
unnamed: R124.2, U$6.5 (ISET)
unnamed: R127.2, U$6.2 (-IN)
unnamed: CV-IN11.1, R128.1, R129.1
unnamed: D18.3 (AC), R119.1, R129.2
unnamed: R126.1, U$6.8 (GAIN)


Board: 2 copper layers, 100.0 x 80.0 mm, 207 parts (1 on the bottom side), 108 nets.

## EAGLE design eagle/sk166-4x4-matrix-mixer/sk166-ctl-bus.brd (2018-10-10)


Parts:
1, 2, 3, 4: LSP11
AD-SPARE: LSP11
C1, C2: C-EUC1206; C1206
C3, C10, C14: C-EUC0603; C0603
C6, C7: CPOL-EUCT3528; CT3528
D1: DIODE-MINIMELF; MINIMELF
E: 22-23-2041
IC1: 4067D; SO24W
L1, L2: L-EUL2012C; L2012C
MIDI: PINHD-1X2; 1X02
OK1: 4N25SM; DIL6-SMD
PROG: PINHD-1X6; 1X06
Q1: CRYSTALHC49UP; HC49UP
R1, R2: 220; R1206
R3, R4, R5, R6: 300; R1206
SCL: LSP11
SDA: LSP11
SYNC: 22-23-2041
T: 2510-; PAK100/2500-10
U: 2510-; PAK100/2500-10
U$2: ATMEGA88; TQFP32-08
V: 2510-; PAK100/2500-10
W: 2510-; PAK100/2500-10
X: 22-23-2041
X1: 22-23-2031
Y: 22-23-2041
Z: 22-23-2041

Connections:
+5V: C3.2, C10.1, IC1.24 (VDD), L2.1, PROG.5, R2.2, T.4, U.4, U$2.4 (VCC), U$2.6 (VCC), U$2.18 (AVCC), V.4, W.4
-5V: L1.1, T.6, U.6, V.6, W.6
CST: T.1, U$2.11 (PD7.AIN1.PCINT23.D7)
CSU: U.1, U$2.12 (PB0.ICP1.CLKO.PCINT0.D8)
CSV: U$2.13 (PB1.OC1A.PCINT1.D9), V.1
CSW: U$2.14 (PB2.!SS!.OC1B.PCINT2.D10), W.1
GND: C1.2, C2.2, C3.1, C6.-, C7.+, C10.2, C14.1, IC1.12 (VSS), IC1.15 (INH), OK1.4 (EMI), PROG.6, R3.1, R4.1, R5.1, R6.1, T.5, U.5, U$2.3 (GND), U$2.5 (GND), U$2.21 (GND), V.5, W.5, X1.2
HSYNC: SYNC.4, U$2.32 (PD2.INT0.PCINT18.D2)
MIDI: OK1.5 (COL), R2.1, U$2.30 (PD0.RX.PCINT16.D0)
MISO: PROG.2, U$2.16 (PB4.MISO.PCINT4.D12)
MOSI: PROG.1, T.3, U.3, U$2.15 (PB3.MOSI.OC2A.PCINT3.D11), V.3, W.3
unnamed: PROG.4, U$2.29 (PC6.!RESET!.PCINT14)
unnamed: R3.2, T.7, U.7, V.7, W.7
unnamed: C1.1, Q1.2, U$2.7 (PB6.XTAL1.TOSC1.D20)
unnamed: C2.1, Q1.1, U$2.8 (PB7.XTAL2.TOSC2.D21)
unnamed: IC1.1 (X), U$2.19 (A6)
unnamed: IC1.10 (A), U$2.23 (PC0.PCINT8.A0)
unnamed: R4.2, T.8, U.8, V.8, W.8
unnamed: R5.2, T.9, U.9, V.9, W.9
unnamed: R6.2, T.10, U.10, V.10, W.10
unnamed: IC1.11 (B), U$2.24 (PC1.PCINT9.A1)
unnamed: IC1.14 (C), U$2.25 (PC2.PCINT10.A2)
unnamed: IC1.13 (D), U$2.26 (PC3.PCINT11.A3)
unnamed: AD-SPARE.MP, U$2.22 (A7)
unnamed: IC1.8 (X1), X.2
unnamed: IC1.7 (X2), X.3
unnamed: 1.MP, U$2.2 (PD4.XCK.T0.PCINT20.D4)
unnamed: MIDI.2, R1.1
unnamed: D1.A, MIDI.1, OK1.2 (C)
unnamed: D1.C, OK1.1 (A), R1.2
unnamed: 2.MP, U$2.9 (PD5.T1.OC0B.PCINT21.D5)
unnamed: 3.MP, U$2.10 (PD6.AIN0.OC0A.PCINT22.D6)
unnamed: 4.MP, U$2.31 (PD1.TX.PCINT17.D1)
unnamed: IC1.4 (X5), Y.2
unnamed: IC1.3 (X6), Y.3
unnamed: IC1.2 (X7), Y.4
unnamed: IC1.22 (X9), Z.2
unnamed: IC1.21 (X10), Z.3
unnamed: IC1.20 (X11), Z.4
unnamed: C7.-, L1.2, X1.1
unnamed: C6.+, L2.2, X1.3
unnamed: E.2, IC1.18 (X13)
unnamed: C14.2, U$2.20 (AREF)
unnamed: E.3, IC1.17 (X14)
unnamed: SDA.MP, U$2.27 (PC4.SDA.PCINT12.A4)
unnamed: SCL.MP, U$2.28 (PC5.SCL.PCINT13.A5)
unnamed: E.4, IC1.16 (X15)
O!E: SYNC.1, U$2.1 (PD3.INT1.OC2B.PCINT19.D3)
SCK: PROG.3, T.2, U.2, U$2.17 (PB5.SCK.PCINT5.D13), V.2, W.2
XT: IC1.9 (X0), X.1
YT: IC1.5 (X4), Y.1
YU: IC1.6 (X3), X.4
ZT: IC1.23 (X8), Z.1
ZZT: E.1, IC1.19 (X12)



Board: 2 copper layers, 171.4 x 101.9 mm, 39 parts (11 on the bottom side), 54 nets.

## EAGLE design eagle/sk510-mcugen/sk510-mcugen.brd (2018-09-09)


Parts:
C1, C2: CPOL-EUCT3528; CT3528
C3, C4: 100n; C0805
C5, C6: C-EUC0805; C0805
D0, D1, D2, D3, D4, D5, D6: DIODE_2CACA-SOT23; SOT23
IC1: TINY26LS; SO20L
JP1: PINHD-1X2; 1X02
JP2: PINHD-1X6; 1X06
PAD1, PAD2, PAD3, PAD4, PAD5, PAD6: 3,17/1,1
Q1: CRYSTALHC49UP; HC49UP
R1, R2, R3: 1k; R0805
R4, R5, R6: 680; R0805
R7, R8, R9: 180; R0805
X1: CON-POWER; 22-23-2031
X2: CON-SYNCBUS; 22-23-2041

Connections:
0V: C1.-, C2.+, C3.2, C4.1, C5.2, C6.2, D1.1 (A), D2.1 (A), D3.1 (A), D4.1 (A), D5.1 (A), D6.1 (A), IC1.6 (GND), IC1.16 (GND), JP1.2, JP2.1, R7.1, R8.1, R9.1, X1.2
+5V: C1.+, C3.1, D0.2 (C), D0.3 (AC), D1.2 (C), D2.2 (C), D3.2 (C), D4.2 (C), D5.2 (C), D6.2 (C), IC1.5 (VCC), X1.1
-5V: C2.-, X1.3
unnamed: C4.2, IC1.15 (AVCC)
unnamed: C5.1, IC1.8 ((ADC8/XTAL2)PB5), Q1.2
unnamed: C6.1, IC1.7 ((ADC7/XTAL1)PB4), Q1.1
unnamed: D0.1 (A), JP2.2
unnamed: IC1.10 ((ADC10/!RESET!)PB7), JP1.1, JP2.3
unnamed: IC1.3 ((SCK/SCL/!OC1B!)PB2), JP2.4
unnamed: IC1.2 ((MISO/DO/OC1A)PB1), JP2.5
unnamed: IC1.1 ((MOSI/DI/SDA/!OC1A!)PB0), JP2.6
unnamed: D1.3 (AC), IC1.9 ((ADC9/INT0/T0)PB6), R4.1
unnamed: IC1.20 ((ADC0)PA0), X2.4
unnamed: IC1.19 ((ADC1)PA1), X2.3
unnamed: IC1.18 ((ADC2)PA2), X2.2
unnamed: IC1.17 ((AREF)PA3), X2.1
unnamed: D2.3 (AC), IC1.4 ((OC1B)PB3), R5.1
unnamed: PAD4.1, R1.2
unnamed: D3.3 (AC), IC1.11 ((ADC6/AIN1)PA7), R6.1
unnamed: PAD5.1, R2.2
unnamed: PAD6.1, R3.2
unnamed: D4.3 (AC), IC1.12 ((ADC5/AIN0)PA6), R1.1
unnamed: PAD1.1, R4.2, R9.2
unnamed: D5.3 (AC), IC1.13 ((ADC4)PA5), R2.1
unnamed: PAD2.1, R5.2, R7.2
unnamed: D6.3 (AC), IC1.14 ((ADC3)PA4), R3.1
unnamed: PAD3.1, R6.2, R8.2


Board: 2 copper layers, 100.0 x 80.0 mm, 34 parts (0 on the bottom side), 27 nets.

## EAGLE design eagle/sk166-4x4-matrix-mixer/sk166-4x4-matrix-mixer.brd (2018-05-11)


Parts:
C1, C2, C3, C4, C5, C6, C7, C10, C11, C12, C13, C14, C15: C-EUC1206; C1206
C8, C9: 2u2tantal; CT6032
D6: BAT54S-L44; SOT23
IC1, IC2: TL062D; SO08
L1, L2: LL2012C; L2012C
OUT-, OUT-1, OUT-2, OUT-3: 3,17/1,1
R1, R34, R40, R41: 2k; R1206
R2, R3, R4, R7, R20, R25, R26, R28, R29, R30, R31, R33, R35, R36, R37, R39: 1M; R1206
R5: 47k; R1206
R6, R9, R11, R13, R17, R22, R27, R32, R38: 1k; R1206
R8, R15, R19, R24, R46, R64: 100; R1206
R14, R21, R43, R63: 120; R1206
R18: 1k5; R1206
SIFF-IN: 3,17/1,1
TRIM1: 500; RTRIM64Y
U$1, U$2, U$3, U$5: LT1228; SO08
U$4: MAX5741; UMAX10
X3: 2510-; PAK100/2500-10

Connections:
!CS: U$4.1 (!CS), X3.1
+5V: C1.2, C3.1, C7.1, C9.+, C10.1, C11.1, C12.2, C14.1, D6.2 (C), IC1.8 (V+), IC2.8 (V+), L2.1, R18.2, U$1.7 (VCC), U$2.7 (VCC), U$3.7 (VCC), U$4.3 (VDD), U$5.7 (VCC)
-5V: C2.2, C4.1, C5.1, C6.1, C8.-, C13.1, C15.2, D6.1 (A), IC1.4 (V-), IC2.4 (V-), L1.1, U$1.4 (VSS), U$2.4 (VSS), U$3.4 (VSS), U$5.4 (VSS)
DATA: U$4.5 (DIN), X3.3
GND: C1.1, C2.1, C3.2, C4.2, C5.2, C6.2, C7.2, C8.+, C9.-, C10.2, C11.2, C12.1, C13.2, C14.2, C15.1, R3.1, R5.2, R14.2, R15.1, R19.1, R21.2, R24.1, R25.1, R30.1, R36.1, R43.2, R46.1, R63.2, R64.1, TRIM1.1 (E), U$4.4 (GND), X3.5
unnamed: U$5.1 (I-OUT), X3.10
unnamed: OUT-1.1, R11.1, U$2.6 (VOUT)
unnamed: OUT-2.1, R13.1, U$3.6 (VOUT)
unnamed: L2.2, X3.4
unnamed: L1.2, X3.6
unnamed: U$1.1 (I-OUT), X3.7
unnamed: IC1.3 (+IN), R2.2, R7.1
unnamed: IC1.2 (-IN), R3.2, R4.1
unnamed: R21.1, R22.2, U$1.8 (GAIN)
unnamed: IC1.1 (OUT), R4.2, R6.1
unnamed: R1.1, R6.2, R7.2
unnamed: R1.2, U$1.5 (ISET)
unnamed: R2.1, U$4.7 (OUTA)
unnamed: R5.1, R8.1, SIFF-IN.1
unnamed: D6.3 (AC), R8.2, R9.1
unnamed: U$2.1 (I-OUT), X3.8
unnamed: R9.2, R19.2, U$1.3 (+IN), U$2.3 (+IN), U$3.3 (+IN), U$5.3 (+IN)
unnamed: OUT-.1, R22.1, U$1.6 (VOUT)
unnamed: R24.2, U$1.2 (-IN)
unnamed: R18.1, TRIM1.3 (A)
unnamed: R41.2, U$5.5 (ISET)
unnamed: R15.2, U$5.2 (-IN)
unnamed: R14.1, R17.2, U$5.8 (GAIN)
unnamed: OUT-3.1, R17.1, U$5.6 (VOUT)
unnamed: R20.1, U$4.8 (OUTB)
unnamed: TRIM1.2 (S), U$4.6 (REF)
unnamed: IC1.5 (+IN), R20.2, R28.1
unnamed: IC1.6 (-IN), R25.2, R26.1
unnamed: R34.2, U$2.5 (ISET)
unnamed: U$3.1 (I-OUT), X3.9
unnamed: IC1.7 (OUT), R26.2, R27.1
unnamed: R27.2, R28.2, R34.1
unnamed: IC2.3 (+IN), R29.2, R33.1
unnamed: R46.2, U$2.2 (-IN)
unnamed: IC2.2 (-IN), R30.2, R31.1
unnamed: IC2.1 (OUT), R31.2, R32.1
unnamed: R32.2, R33.2, R40.1
unnamed: R11.2, R43.1, U$2.8 (GAIN)
unnamed: IC2.5 (+IN), R35.2, R39.1
unnamed: IC2.6 (-IN), R36.2, R37.1
unnamed: IC2.7 (OUT), R37.2, R38.1
unnamed: R38.2, R39.2, R41.1
unnamed: R35.1, U$4.10 (OUTD)
unnamed: R29.1, U$4.9 (OUTC)
unnamed: R40.2, U$3.5 (ISET)
unnamed: R64.2, U$3.2 (-IN)
unnamed: R13.2, R63.1, U$3.8 (GAIN)
SCK: U$4.2 (SCLK), X3.2

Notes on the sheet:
Input gain = 0.09090909090909
output gain 9.181818
gain = 10 x ISET x r20
gain = in_gain x 10 x ISET x r20 x out_gain
ISET = gain / (in_gain x 10 x r20 x out_gain)

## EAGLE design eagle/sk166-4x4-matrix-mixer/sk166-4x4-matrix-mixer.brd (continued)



Board: 2 copper layers, 100.0 x 80.0 mm, 73 parts (3 on the bottom side), 53 nets.

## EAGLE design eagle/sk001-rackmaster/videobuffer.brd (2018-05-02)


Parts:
C1, C2: 10u; CT3528
C3, C4, C5, C6: 100n; C0805
GND_A: 3,17/1,1
GND_B: 3,17/1,1
IN1, IN2, IN3, IN4: 3,17/1,1
L1, L2: L-EU; L2012C
OUT1, OUT2, OUT3, OUT4: 3,17/1,1
R1, R2, R3, R4, R7, R8, R9, R10: 200; R0805
R5, R6, R11, R12: 75; R0805
U$1, U$2: MAX4392ESA; SO08
X1: CON-POWER; 22-23-2031

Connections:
0V: C1.-, C2.+, C3.2, C4.2, C5.2, C6.2, GND_A.1, GND_B.1, R2.2, R4.2, R8.2, R10.2, X1.2
+5V: C1.+, C4.1, C6.1, L2.1, U$1.8 (+5V), U$2.8 (+5V)
-5V: C2.-, C3.1, C5.1, L1.2, U$1.4 (-5V), U$2.4 (-5V)
unnamed: L1.1, X1.1
unnamed: L2.2, X1.3
unnamed: IN1.1, U$1.3 (+IN)
unnamed: IN2.1, U$1.5 (+IN)
unnamed: R3.2, R4.1, U$1.6 (-IN)
unnamed: R1.2, R2.1, U$1.2 (-IN)
unnamed: R1.1, R5.2, U$1.1 (OUT)
unnamed: OUT1.1, R5.1
unnamed: R3.1, R6.2, U$1.7 (OUT)
unnamed: OUT2.1, R6.1
unnamed: IN3.1, U$2.3 (+IN)
unnamed: IN4.1, U$2.5 (+IN)
unnamed: R9.2, R10.1, U$2.6 (-IN)
unnamed: R7.2, R8.1, U$2.2 (-IN)
unnamed: R7.1, R11.2, U$2.1 (OUT)
unnamed: OUT3.1, R11.1
unnamed: R9.1, R12.2, U$2.7 (OUT)
unnamed: OUT4.1, R12.1


Board: 2 copper layers, 58.4 x 28.2 mm, 33 parts (1 on the bottom side), 21 nets.

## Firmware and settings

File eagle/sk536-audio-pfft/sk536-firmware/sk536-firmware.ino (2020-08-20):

//------------------------------------------------------------------------------
// AUDIO SPECTRUM Analyser									Teensy 3.2
//
//
//
// 	Part of the Synkie Project: www.synkie.net
//
// 	© 2018 Michael Egger, Licensed under GNU GPLv3
//
// based on https://github.com/prickle/TeensySpectrumAnalyser/blob/master/TeensySpectrumAnalyser.ino
//--------------------------------------------------------------------------------------------

/*PINS

0		RX1(MIDI)
1		TX1(MIDI)
2		Pixels
3		Encoder		(PWM)
4		Encoder		(PWM)
5		Level 1			(PWM)
6		Level 2			(PWM)
7									 DOUT to DAC(SD)
8		Trigger 1
9		-Audio		(PWM)
10		(SD)		(PWM)
11		-Audio	
12		Jack Detect
13		-Audio
14		(SD)						SCK
15			(-Volume)
16		Btn
17		Btn
18		-Audio
19		-Audio
20		Level 3			(PWM)
21					(PWM)
22		-Audio		(PWM)
23		-Audio		(PWM)
24		Trigger 0
25		Level 0 	(PWM)			Slave Select
26		Btn
27		Btn
28		Btn
29		Btn
30		Btn
31 		Trigger 2
32 		Trigger 3
33		Btn

*/

//#define SERIAL_DEBUG 1

#define CS_Pin 25

#include <Encoder.h>
#include <Adafruit_NeoPixel.h>
#include "Timer.h"
#include <Bounce.h>
#include <Audio.h>
#include <Wire.h>
#include <SPI.h>
#include <SD.h>
#include <SerialFlash.h>

// GUItool: begin automatically generated code
AudioInputI2S            i2s1;           //xy=156,138
AudioAnalyzeFFT256       fft256_1;       //xy=188,438
AudioMixer4              mixer1;         //xy=278,278
AudioAnalyzeFFT1024      fft1024_1;      //xy=408,278
AudioAnalyzeRMS          rms1;           //xy=444,111
AudioAnalyzeRMS          rms2;           //xy=452,152
AudioConnection          patchCord1(i2s1, 0, rms1, 0);
AudioConnection          patchCord2(i2s1, 0, mixer1, 0);
AudioConnection          patchCord3(i2s1, 1, rms2, 0);
AudioConnection          patchCord4(i2s1, 1, mixer1, 1);
AudioConnection          patchCord5(mixer1, fft1024_1);
AudioControlSGTL5000     sgtl5000_1;     //xy=469,58
// GUItool: end automatically generated code



const float fft_logScale = 2.;  		//Scale the logarithm curve deeper or shallower
const float fft_gain = 240.0;         	//Input gain
const float fft_shift = 1.0;          	//Shift bars down to mask background noise
int 		fft_top 	= 312;
int 		fft_bottom 	= 0;
int 		fft_band[16][2];

typedef enum {
	m_Idle = 0,
	m_Select = 1,
	m_Trigger = 2,
	m_Linearity = 3,
	m_Reactance = 4,
	m_Bias = 5,
	m_Scale = 6,
	m_Q = 7,
	m_Frequency = 8
} skState_t;

int input_level_r;
int input_level_l;

// channel settings				// normalized to bar graph height 0.-1. btm to top
float 	c_frequency[4];			// so frequency is logarithmically mapped, 0. -> 0Hz, 1. ~22khz
float 	c_q[4];
int 	c_band_lo[4];
int 	c_band_hi[4];
float 	c_scale[4];
float 	c_bias[4];
float 	c_reactance[4];
float 	c_linearity[4];
float 	c_trigger[4];


float old_level[4];
int out_level[4];
int out_trigger[4];
int energy[16];

Timer t;

Bounce 									btn1 = Bounce(30, 5); 
Bounce 									btn2 = Bounce(29, 5); 
Bounce 									btn3 = Bounce(33, 5); 
Bounce 									btn4 = Bounce(28, 5); 
Bounce 									btn5 = Bounce(27, 5); 
Bounce 									btn6 = Bounce(26, 5); 
Bounce 									btn7 = Bounce(17, 5); 
Bounce 									btn8 = Bounce(16, 5); 


unsigned char 							selected;
skState_t 								mode = m_Idle;
unsigned char 							brightness;
Encoder 								myEnc(4, 3);
Adafruit_NeoPixel 						strip = Adafruit_NeoPixel(48, 2, NEO_GRB + NEO_KHZ800);

//--------------------------------------------------------------------------------------------------
void level_meter(int level, unsigned char id) {
    for (char i = 0; i < 16; i++) {
		if ((level/64) > (i+1)) {
			strip.setPixelColor(i + (id * 16), strip.Color(brightness,brightness,brightness));
	    } else if (level/64 > i) {
     		unsigned char rem = level % 64;
      		rem *= brightness/64;
     	 	strip.setPixelColor(i + (id * 16), strip.Color(rem,rem,rem));
	    } else {
			strip.setPixelColor(i + (id * 16), strip.Color(0,0,0));
		}
	}
}
//--------------------------------------------------------------------------------------------------
void spectrum_meter() {
    for (char i = 0; i < 16; i++) {
    	unsigned char b = map(constrain(energy[i],0,32),0,32,0,64);
    	unsigned char g = map(constrain(energy[i],32,64),32,64,0,127);
		strip.setPixelColor(i, strip.Color(0,g,b));
	}
}


void scale_meter() {
    for (char i = 0; i < 16; i++) {
		strip.setPixelColor(i+16, strip.Color(0,0,0));
	}
}

void indicator(float val) {
		strip.setPixelColor((char)(16.* val) + 16, strip.Color(60,64,0));
}

//--------------------------------------------------------------------------------------------------
void change_mode(skState_t m) {
	if (m == mode) {
		mode = m_Idle;
	} else {
		mode = m;
	}
	
    for (char i = 0; i < 9; i++) {
			strip.setPixelColor(i + 39, strip.Color(0,0,0));
	}
	if (mode) strip.setPixelColor(mode + 39, strip.Color(60,65,0));
	
	switch (mode) {
		case m_Select:
			myEnc.write(selected * 4);
			break;
			
		case m_Trigger:
			myEnc.write(c_trigger[selected] * 1024);
			break;
			
		case m_Linearity:
			myEnc.write(c_linearity[selected] * 1024);
			break;
			
		case m_Reactance:
			myEnc.write(c_reactance[selected] * 1024);
			break;
			
		case m_Bias:
			myEnc.write(c_scale[selected] * 1024);
			break;
			
		case m_Scale:
			myEnc.write(c_scale[selected] * 1024);
			break;
			
		case m_Q:
			myEnc.write(c_q[selected]);
			break;
			
		case m_Frequency:
			myEnc.write(c_frequency[selected] * 1024);
			break;
			
		default:
			myEnc.write(0);
			break;
	}
}
//--------------------------------------------------------------------------------------------------
void check_Encoder() {
	static signed int old_position;
	signed int new_position = myEnc.read();
	if (new_position == old_position) return;
	
	old_position = new_position;
	switch (mode) {
		case m_Select:
			selected = new_position/4;
			selected %= 4;
			break;
			
		case m_Trigger:
			c_trigger[selected] = constrain(new_position / 1024., 0., 1.);
			break;
			
		case m_Linearity:
			c_linearity[selected] = constrain(new_position / 1024., 0., 1.);
			break;
			
		case m_Reactance:
			c_reactance[selected] = constrain(new_position / 1024., 0., 1.);
			break;
			
		case m_Bias:
			c_bias[selected] = constrain(new_position / 1024., 0., 1.);
			break;
			
		case m_Scale:
			c_scale[selected] = constrain(new_position / 1024., 0., 1.);
			break;
			
		case m_Q:
			c_q[selected] = constrain(new_position, 1, 64);
			calculate_bands_for_channel(selected);
			break;
			
		case m_Frequency:
			c_frequency[selected] = constrain(new_position / 1024., 0., 1.);
			calculate_bands_for_channel(selected);
			break;
			
		default:
			break;
	}
}

//--------------------------------------------------------------------------------------------------

void update_display(){
	static skState_t 	display_mode;
	if (mode != m_Select) display_mode = mode;
	
	switch (display_mode) {
			
		case m_Trigger:
			spectrum_meter();
			level_meter(out_level[selected],1);
			indicator(c_trigger[selected]);
			break;
			
		case m_Linearity:
			spectrum_meter();
			level_meter(out_level[selected],1);
			indicator(c_linearity[selected]);
			break;
			
		case m_Reactance:
			spectrum_meter();
			level_meter(out_level[selected],1);
			indicator(c_reactance[selected]);
			break;
			
		case m_Bias:
			spectrum_meter();
			level_meter(out_level[selected],1);
			indicator(c_bias[selected]);
			break;
			
		case m_Scale:
			spectrum_meter();
			level_meter(out_level[selected],1);
			indicator(c_scale[selected]);
			break;
			
		case m_Q:
			spectrum_meter();
			level_meter(out_level[selected],1);
			
			strip.setPixelColor((char)(16.*c_frequency[selected]) + 16, strip.Color(60,64,0));
			break;
			
		case m_Frequency:
			spectrum_meter();
			level_meter(out_level[selected],1);
			
			strip.setPixelColor((char)(16.*c_frequency[selected]) + 16, strip.Color(60,64,0));

			break;
		default:
			spectrum_meter();
			indicator(c_frequency[0]);
			indicator(c_frequency[1]);
			indicator(c_frequency[2]);
			indicator(c_frequency[3]);
	}
	signed char ch_idx = selected;
	if (mode == m_Idle) ch_idx = -1;
	for (char i = 0; i < 4; i++) {
		if (ch_idx == i)  {
			strip.setPixelColor(2*i + 32, strip.Color(out_level[i]/4,out_level[i]/4,16));
			strip.setPixelColor(2*i + 33, strip.Color(out_trigger[i],out_trigger[i],16));
		} else {
			int b = out_level[i] * brightness / 256;
			strip.setPixelColor(2*i + 32, strip.Color(b,b,b));
			b = out_trigger[i] * brightness / 256;
		 	strip.setPixelColor(2*i + 33, strip.Color(b,0,0));
		 }
	}
	cli();
	strip.show();
	sei();
}

//--------------------------------------------------------------------------------------------------
void defaults() {
	c_frequency[3] = 0.1;
	c_frequency[2] = 0.2;
	c_frequency[1] = 0.5;
	c_frequency[0] = 0.75;
	for (char i = 0; i < 4;i++) {
		c_q[i] = 16;
		c_scale[i] = 0.5;
		c_bias[i] = 0.5;
		c_reactance[i] = 0.5;
		c_linearity[i] = 0.5;
		c_trigger[i] = 0.5;
		calculate_bands_for_channel(i);
	}

}

void clear_all() {
	for (char i = 0; i < 48; i++) {
		strip.setPixelColor(i, strip.Color(0,0,0));
	}
}

void welcome() {
	for (char i = 0; i < 12; i++) {
		unsigned char n = random(32);
		strip.setPixelColor(n, strip.Color(255,255,255));
		strip.show();
		delay(15);
		strip.setPixelColor(n, strip.Color(0,0,0));
		strip.show();
		delay(20);
	}
}
//------------s--------------------------------------------------------------------------------------
void setup() {
	strip.begin();
	welcome();
#ifdef SERIAL_DEBUG
	Serial.begin(9600);
  	while (!Serial) {
    	; // wait for serial port to connect. Needed for native USB
	  }
	  Serial.println("Here we go");
  #endif

	SPI.setMOSI(7); 
	SPI.setSCK(14);
	SPI.begin(); 
	pinMode(CS_Pin,OUTPUT);		// slave select
//	pinMode(12,INPUT_PULLUP); // jack detect
	
	input_level_l = 120;
	input_level_r = 120;

	defaults();
	calculate_bands();

	sgtl5000_1.enable();
	sgtl5000_1.inputSelect(AUDIO_INPUT_MIC);

	sgtl5000_1.volume(0.5);
	AudioMemory(12);


	pinMode(16,INPUT_PULLUP);
	pinMode(17,INPUT_PULLUP);
	pinMode(26,INPUT_PULLUP);
	pinMode(27,INPUT_PULLUP);
	pinMode(28,INPUT_PULLUP);
	pinMode(29,INPUT_PULLUP);
	pinMode(30,INPUT_PULLUP);
	pinMode(33,INPUT_PULLUP);
	
	pinMode(24,OUTPUT);
	pinMode(8,OUTPUT);
	pinMode(31,OUTPUT);
	pinMode(32,OUTPUT);
/*	pinMode(5,OUTPUT);
	pinMode(6,OUTPUT);
	pinMode(20,OUTPUT);
*/
	t.every(50,update_display);
	t.every(10,check_Encoder);
//	t.every(500,check_jack);
	strip.show(); // Initialize all pixels to 'off'
	brightness = 16;

	dacOP();
	delay(100);
	dacOP();
}

void dacOP() {
	static int sendval;
	
	sendval = 0xf010;	
	digitalWrite(CS_Pin,LOW);
	SPI.transfer16(sendval);
	digitalWrite(CS_Pin,HIGH);
}



//--------------------------------------------------------------------------------------------------
void loop() {
	t.update();
	float fval;
	int i;
	int temp;
	
	btn1.update();
	btn2.update();
	btn3.update();
	btn4.update();
	btn5.update();
	btn6.update();
	btn7.update();
	btn8.update();
	if(btn1.fallingEdge()) change_mode(m_Bias);
	if(btn2.fallingEdge()) change_mode(m_Scale);
	if(btn3.fallingEdge()) change_mode(m_Reactance);
	if(btn4.fallingEdge()) change_mode(m_Trigger);
	if(btn5.fallingEdge()) change_mode(m_Linearity);
	if(btn6.fallingEdge()) change_mode(m_Select);
	if(btn7.fallingEdge()) change_mode(m_Frequency);
	if(btn8.fallingEdge()) change_mode(m_Q);

	if (rms1.available()) {
		temp = (int)(rms1.read() * 1024.);
		if (temp > input_level_r) input_level_r = temp;
		else if (input_level_r) input_level_r--;
	}
	
	if (rms2.available()) {
		temp = (int)(rms2.read() * 1024.);
		if (temp > input_level_l ) 	 input_level_l = temp;
		else if (input_level_l) input_level_l--;
	}
	
	if (fft1024_1.available()) {
		for (i = 0; i < 16; i++) {
      		//Get FFT data
      		fval = fft1024_1.read(fft_band[i][0], fft_band[i][1]);
      		fval = pow(fval, 4.);
     	 	fval = fval * fft_gain - fft_shift;
      		fval = constrain(fval,0.,255.);            //don't saturate the band
      		if (fval > energy[i]) energy[i] = fval;
      		else energy[i] -= 4;
      	}
		
		for (i = 0; i < 4; i++) {
      		fval = fft1024_1.read(c_band_lo[i],c_band_hi[i]);
      		fval = pow(fval, (4 * c_linearity[i]));
        	fval += c_bias[i]-0.5;
      		fval *= c_scale[i]*2.;
      		if ( fval < old_level[i]) fval = old_level[i] - c_reactance[i]/10;
      		old_level[i] = fval;
			if ( fval > c_trigger[i]) out_trigger[i] = 255;
			else out_trigger[i] = 0;
      		fval *= 1024;
      		fval = constrain(fval,0.,1024.);
      		out_level[i] = fval;
      		
      		int sendval = out_level[i] << 2;
      		sendval &= 1023 << 2;
      		sendval |= i << 12;
			digitalWrite(CS_Pin,LOW);
			SPI.transfer16(sendval);
			digitalWrite(CS_Pin,HIGH);
      	}
	}
	
	

	digitalWrite(24,out_trigger[0]);
	digitalWrite(8,out_trigger[1]);
	digitalWrite(31,out_trigger[2]);
	digitalWrite(32,out_trigger[3]);
	
	//delay(2);
	
}
/*
void check_jack() {
	static char oldJack 
	char jack = digitalRead(12);
	if (jack==oldJack) return;
	
	oldJack = jack;
	
	if (!jack) sgtl5000_1.inputSelect(AUDIO_INPUT_MIC);
	else sgtl5000_1.inputSelect(AUDIO_INPUT_LINEIN);


}
*/
void calculate_bands_for_channel(int chan) {
	float len = (float)fft_top - (float)fft_bottom;
	float lo = (float)fft_bottom + (float)len * pow(c_frequency[chan]-0.5/c_q[chan], fft_logScale);
	float hi = (float)fft_bottom + (float)len * pow(c_frequency[chan]+0.5/c_q[chan], fft_logScale);
	if (lo < 0.) lo = 0;
	if (hi > 511.) hi = 511.;
	c_band_lo[chan] = round(lo);		
	c_band_hi[chan] = round(hi);
#ifdef SERIAL_DEBUG
	Serial.print("Channel ");	Serial.print(chan),	Serial.print(" from ");Serial.print(c_band_lo[chan]);Serial.print(" to ");Serial.print(c_band_hi[chan]);Serial.println();
#endif
}


void calculate_bands() {
	float len = (float)fft_top - (float)fft_bottom;
	float lo,hi;
	for (int i = 0; i<16; i++) {
		lo = (float)fft_bottom + (float)len * pow((float)i/16., fft_logScale);
		hi = (float)fft_bottom + (float)len * pow((float)(i+1)/16., fft_logScale);
		fft_band[i][0] = round(lo);		
		fft_band[i][1] = round(hi);
	
#ifdef SERIAL_DEBUG
	Serial.print("Band ");	Serial.print(i),	Serial.print(" from ");Serial.print(fft_band[i][0]);Serial.print(" to ");Serial.print(fft_band[i][1]);Serial.println();
#endif
	}	
}

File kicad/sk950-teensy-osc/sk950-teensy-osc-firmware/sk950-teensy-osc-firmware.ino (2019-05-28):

//----------------------------------------------------------------------------------------
//
//	sk950-teensy-osc  Firmware		
//						
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
//----------------------------------------------------------------------------------------
#include <EEPROM.h>
#include <Adafruit_NeoPixel.h>
#include <Wire.h>
#include <menu.h>//menu macros and objects
#include <menuIO/u8g2Out.h>
#include <TimerOne.h>
#include <ClickEncoder.h>
#include <menuIO/clickEncoderIn.h>
#include <menuIO/keyIn.h>
#include <menuIO/chainStream.h>
#include <menuIO/serialOut.h>
#include <menuIO/serialIn.h>
#include "AS5047.h"
#include <Encoder.h>
#include <U8g2lib.h>
#include <Timer.h>
#include "logo.h"

using namespace Menu;


#include <Audio.h>
#include <Wire.h>
#include <SPI.h>
#include <SD.h>
#include <SerialFlash.h>

// GUItool: begin automatically generated code
AudioSynthWaveformSine   sine2;          //xy=175.82144165039062,470.57141876220703
AudioSynthWaveform       triangle2;      //xy=177,508
AudioSynthWaveform       square1;      //xy=182,204
AudioSynthWaveform       saw1;      //xy=183,247
AudioSynthWaveformSine   sine1;          //xy=185,115.42855834960938
AudioSynthWaveform       square2;      //xy=184,545
AudioSynthWaveform       triangle1;      //xy=187,161
AudioSynthNoiseWhite     noise1;         //xy=188,309
AudioSynthNoiseWhite     noise2;         //xy=196,649
AudioSynthWaveform       saw2;      //xy=198,585
AudioMixer4              mixer2;         //xy=397,497
AudioMixer4              mixer1;         //xy=404,206
AudioMixer4              mixer11;         //xy=544,315
AudioMixer4              mixer21;         //xy=581,599
AudioOutputAnalogStereo  dacs1;          //xy=635.4285714285713,440.85714285714283
AudioConnection          patchCord1(sine2, 0, mixer2, 0);
AudioConnection          patchCord2(triangle2, 0, mixer2, 1);
AudioConnection          patchCord3(square1, 0, mixer1, 2);
AudioConnection          patchCord4(saw1, 0, mixer1, 3);
AudioConnection          patchCord5(sine1, 0, mixer1, 0);
AudioConnection          patchCord6(square2, 0, mixer2, 2);
AudioConnection          patchCord7(triangle1, 0, mixer1, 1);
AudioConnection          patchCord8(noise1, 0, mixer11, 1);
AudioConnection          patchCord9(saw2, 0, mixer2, 3);
AudioConnection          patchCord10(mixer2, 0, mixer21, 0);
AudioConnection          patchCord11(mixer1, 0, mixer11, 0);
AudioConnection          patchCord12(mixer11, 0, dacs1, 0);
AudioConnection          patchCord13(mixer21, 0, dacs1, 1);
// GUItool: end automatically generated code 


   
//-------------------------------- PINS

const int 	button_pin[]		= {28,29,30,31,24,25,26,27};
const int	cv_pin[]			= {A15,A14,A16,A17};
#define 	PIN_ENTER			9
#define 	PIN_SENSITIVITY		A18
//-------------------------------- Defines

#define MENU_TIMEOUT			3
#define INTERACTION_TIMEOUT		10

#define PRESETS_START_ADDRESS			8
#define	PRESET_COUNT_ADDRESS			0
#define MAX_PRESET_COUNT				100


#define MODE_IDLE					0
#define MODE_STORE					1

const char * cv_mode_strings[] = {		"NOT | OCT | FRQ | SNS", 
								"NOT | OCT | WAV | DET",
								"NOT | OCT | VEL | DET"
									};


#define CV_MODE_NOFS				0		// note, octave, frequency, sensitivity
#define CV_MODE_NOWD				1		// note, octave, waveform, detune
#define CV_MODE_NOVD				2		// note, octave, velocity, detune

int cv_mode;

typedef struct {
	float 	frequency;		// base frequency
	long 	detune;			// detune second oscillator in cents
	int 	amplitude;		// 0..127 velocity
	int 	waveform;		
	int		phase;			// phase of second oscillator in degrees;
} note_t;

//-------------------------------- Globals

U8G2_SSD1306_128X64_NONAME_F_HW_I2C  	u8g2(U8G2_R0);
Adafruit_NeoPixel 						pixels = Adafruit_NeoPixel(8, 5, NEO_GRB + NEO_KHZ800);
AS5047 myAS5047(10); // SS pin

Timer									t;

ClickEncoder 						clickEncoder(8,7,9,4);
ClickEncoderStream 					encStream(clickEncoder,1);

note_t 								current_scale[8];
int								selected_note;
int								played_note = 9;
int 								mode;

int 								cv_top[4];
int								cv_bottom[4];
int								cv_raw[4];
float								cv[4];

int preset_count 		= 0;
int save_slot 			= 0;
int recall_slot 		= 0;

int 	octave;
int 	detune;
int 	waveform;
int 	global_amp =127;
int	phase, old_phase;
//========================================================================================
//----------------------------------------------------------------------------------------
//																				Menus
//

//----------------------------------------------------------------------------------------
//																		Prototypes

void store_preset();
void generate_random();
void generate_random_notes();


//----------------------------------------------------------------------------------------
//																		Structure

/*
MENU(cvMenu1," Calib In 1 >",doNothing,anyEvent,noStyle,
  	OP(" Auto Fullrange",		autofullrange1,	enterEvent),
	FIELD(cv_raw[1]," Raw:","",0, 1024 ,0,0,doNothing,noEvent,noStyle),
	FIELD(cv[1]," Out:","",0, 1024 ,0,0,doNothing,noEvent,noStyle),
	FIELD(cv_bottom[1]," Low:","",0, 512 ,10,1,doNothing,noEvent,noStyle),
	FIELD(cv_top[1]," Low:","",0, 512 ,10,1,doNothing,noEvent,noStyle),
	EXIT(" <Back")
);


CHOOSE(cv_mode,chooseCVMenu,"Mode >",doNothing,noEvent,noStyle
  ,VALUE(cv_mode_strings[0],0,doNothing,noEvent)
  ,VALUE(cv_mode_strings[1],1,doNothing,noEvent)
  ,VALUE(cv_mode_strings[2],2,doNothing,noEvent)
);

MENU(cvMenu," Control Voltage >",doNothing,anyEvent,noStyle,
	SUBMENU(chooseCVMenu),
	
	EXIT(" <Back")
);

MENU(scaleMenu," Scales >",doNothing,anyEvent,noStyle,
	EXIT(" <Back")
);
*/

MENU(mainMenu," Main menu",doNothing,noEvent,wrapStyle,
	FIELD(detune," Detune","cents",0, 1200 ,100,1,doNothing,noEvent,noStyle),
	FIELD(phase," Phase","cents",0, 360 ,30, 1,doNothing,noEvent,noStyle),
	FIELD(waveform," Wave","",0, 64 ,4,1,doNothing,noEvent,noStyle),
  	OP(" Random Notes",		generate_random_notes,	enterEvent),
  	OP(" Random Freestyle",	generate_random,		enterEvent),
  	EXIT(" <Exit")
);

#define MAX_DEPTH 2

const colorDef<uint8_t> colors[] MEMMODE={
  {{0,0},{0,1,1}},//bgColor
  {{1,1},{1,0,0}},//fgColor
  {{1,1},{1,0,0}},//valColor
  {{1,1},{1,0,0}},//unitColor
  {{0,1},{0,0,1}},//cursorColor
  {{1,1},{1,0,0}},//titleColor
};

#define fontName u8g2_font_t0_13b_tf
#define fontX 7
#define fontY 13
#define offsetX 0
#define offsetY 16
#define U8_Width 128
#define U8_Height 48

MENU_INPUTS(in,&encStream);

MENU_OUTPUTS(out,MAX_DEPTH
  ,U8G2_OUT(u8g2,colors,fontX,fontY,offsetX,offsetY,{0,0,U8_Width/fontX,U8_Height/fontY})
  ,NONE
);

NAVROOT(nav,mainMenu,MAX_DEPTH,in,out);		//the navigation root object
//----------------------------------------------------------------------------------------
//																		generate presets

void generate_presets() {
	int note;
	float f = 50.;
	for (note = 0; note < 8; note++) {
		current_scale[note].frequency = f;
		current_scale[note].amplitude = 127;
		current_scale[note].detune = 700;
		current_scale[note].waveform = 32;
		f *= 2.;
	}
	
}
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

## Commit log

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2011-06-03 protected about improbably short intervals, cleanup
    [main.c]
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2012-03-10 corrected spelling error
    [sk03-backporch-clamp.sch]
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2012-05-13 adjusted pot and resistor values because of max4392 input bias current
    [sk107-comparator.brd, sk107-comparator.sch]
2012-05-13 corrected resitor values in cv-input template
    [sk-base-cv-in-section.brd, sk-base-cv-in-section.sch]
2012-05-14 sk50-LFO: changed output range to 0-1V, different frequency range for each LFO; not routed yet!
    [sk50-lfo_triple.brd, sk50-lfo_triple.sch]
2012-05-15 fixed extenstion of .brd file
    [sk52-pulsedelay.brd]
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2012-05-16 LFO added reset to schema
    [sk50-lfo_triple.brd, sk50-lfo_triple.sch]
2012-05-16 quick and dirty layout of new resettable sk50
    [sk50-lfo_triple.brd, sk50-lfo_triple.sch]
2012-05-17 LFO: reset is now rising-edge-triggered
    [sk50-lfo_triple.brd, sk50-lfo_triple.sch]
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2012-05-18 fixed some clearance erreors on lfo
    [sk50-lfo_triple.brd]
2012-11-03 corrected potentiometer placement on cv-in base; added lfo frontplate; first version of sk100 vca based on LT1228
    [sk-base-cv-in-section.brd, sk-base-cv-in-section.sch, sk100-vca.brd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]
2012-11-03 corrected orientation of power connector; adapted rc values for better CV frequency response
    [sk100-vca.brd, sk100-vca.sch]
2012-11-03 fixed supply connector was the wrong way round
    [sk107-comparator.brd, sk107-comparator.sch]
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2012-11-27 added first version of sk555 master clock module
    [sk55-audio-in.sch, sk555-master-clock.brd, sk555-master-clock.sch]
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2012-11-28 cleaned up layout of stadard cv in section. added second channel to template
    [sk-base-cv-in-section.brd, sk-base-cv-in-section.sch]
2012-11-28 commented out e-fuse setting, it alwys creates an error when trying to set fuses
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2012-11-28 fixed ERC errors
    [sk130-gamma.brd]
2012-11-28 filter output is inverted. changed output buffer configuration to invert the signals back. also changed the original 500p capacitors to 120. gives higher frequencies and more interesting results
    [sk210-state-variable-filter.brd, sk210-state-variable-filter.sch]
2012-11-28 moved trimmer further away from frontplate, there's a conflict with a plug there. adapted to inverted output buffers
    [sk210-state-variable-filter.brd]
2012-11-28 changed 6k8 resitor to 4k7 because we have loads of them. thanks Uwe
    [sk-base-cv-in-section.brd, sk-base-cv-in-section.sch]
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2012-11-29 corrected various errors
    [sk130-gamma.brd, sk130-gamma.sch]
2012-11-29 small pcb changes: changed potentiometer package, bigger supply rails, nicer ground plane
    [sk109-scale-bias.brd, sk109-scale-bias.sch]
2012-11-29 fixed top layer ground plane
    [sk109-scale-bias.brd]
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2012-12-09 added new 6 channel mixer based on LT1228
    [sk160-6channel-mixer.brd, sk160-6channel-mixer.sch]
2012-12-09 updated opamps on to reflect our latest choice for cv input section, the LMH6643MA
    [sk-base-cv-in-section.brd, sk-base-cv-in-section.sch, sk109-scale-bias.brd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]
2012-12-11 added fader board for 6 channel mixer. attention, because of eagle light restrictions the actual eagle .brf file is not ready for printing - I had to manually shift away the PFL buttons from the fade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
    [sk160-6channel-faders.brd, sk160-6channel-faders.sch]
2012-12-11 added sk165 3 channel matrix mixer with resyncer output
    [sk165-3x-resyncer.brd, sk165-3x-resyncer.sch, sk165-3x3-matrix-mixer.brd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]
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2012-12-12 cleaned up text layer, component values for placement
    [sk109-scale-bias.brd, sk109-scale-bias.sch]
2012-12-12 changed cv-potis to ALPS RK09L1120 with center detent
    [sk-base-cv-in-section.brd, sk-base-cv-in-section.sch, sk109-scale-bias.brd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]
2012-12-23 added missing via
    [sk165-3x-resyncer.brd, sk165-3x3-matrix-mixer.brd]
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2012-12-29 updated some capacitor values, smashed labels on board
    [sk610-delay.brd, sk610-delay.sch]
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2012-12-29 replaced generic diode with BAT54 Schottky diode
    [sk503-piezos.brd, sk503-piezos.sch]
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2013-02-18 smashed some values for better reading. TODO: move LEDs - as they currently re they lie exactly behind banana plugs
    [sk50-lfo_triple.brd]
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2013-03-02 added edges (bandpass) module. frontplate for sk08 inerter
    [sk220-edges.brd, sk220-edges.sch]
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2013-03-02 corrected cap value (edges)
    [sk220-edges.brd, sk220-edges.sch]
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2013-10-25 tried to fix shifting image issue, but it does not work
    [sk610-delay.brd, sk610-delay.sch]
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2013-10-25 adapted ram control fro 125 MHz clock; WON'T RUN ON FIRST PROTOTYPE BOARD! Not tested on hardware.
2013-10-26 corrected version 2 of prototype delay board
    [sk610-delay.brd, sk610-delay.sch]
2013-10-26 fixed pin assignemnts for new board
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2013-10-28 added input protection. added to sync inputs. board layout has to be corrected still
    [sk610-delay.brd, sk610-delay.sch]
2013-10-28 refactored code to be more functionally seperate. added logic schematic of vhdl code
    [logic-schema.sch]
2013-11-01 added serial interface. first version of controller based on atmega644/gnusb
    [sk610-delay.brd, sk610-delay.sch]
2013-11-02 first really working version. Delay time controllable with rotary encoder. hardcoded delay times for line shift and frame shift
    [sk610-delay copy.brd, sk610-delay copy.sch, sk610-delay-controller.brd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]
2013-11-03 added write enable switch and overdub button. moved reset to a global clock signal
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2013-11-06 added missing resistor, cap and connection between controller and main board
    [sk610-delay-controller.brd, sk610-delay-controller.sch, sk610-delay.brd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]
2013-11-06 prepared bus for pcb-cart. redone very old layout of resyncer
    [sk-base-bus.brd, sk02-resyncer.brd, sk02-resyncer.sch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]
2013-11-08 first version of cv-lookuptable/looper module. does not work, transistor is not a perfect switch.
    [sk109-scale-bias.brd, sk505-lut.brd, sk505-lut.sch]
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2013-11-08 fixed 'unable to toggle led' error
    [main.c]
2013-11-09 synchronized record button to odd/even signal to prevent visible glitches
    [sk505-lut.brd, sk505-lut.sch]
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2013-11-09 trimmer gets in the way when trying to program attiny
    [sk506-cv-looper.brd, sk506-cv-looper.sch]
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2013-11-23 audio input board with envelope replaces ac coupling and biasing on sk556-time board
    [sk556-audiopreamp.brd, sk556-audiopreamp.sch, sk556-time.brd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]
2013-11-23 supply of ramp out opamp was wrong way round
    [sk556-time.brd, sk556-time.sch]
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2013-11-26 main.c appartently got corrupted by bad copy-paste jobs for other modules. reverted back to revision 104
    [main.c]
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2013-12-10 corrected r and c values
    [sk540-ramps.brd, sk540-ramps.sch]
2013-12-28 corrected value of r401
    [sk610-delay.brd, sk610-delay.sch]
2013-12-29 improved gain by ting R215 to base of bias pot. reduced oscillation with bigger r307/r308
    [sk109-scale-bias.brd, sk109-scale-bias.sch]
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2014-05-31 second prototype and follow-up corrections
    [sk010-refgen.brd, sk010-refgen.sch]
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2014-10-13 added newly routed aux in module using triple digit naming scheme
    [sk004-aux-in.brd, sk004-aux-in.sch]
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2014-12-29 added sync bus driver module to get rid of leaking image on left side with big synkie
    [sk-base-busdrv.brd, sk-base-busdrv.sch]
2014-12-29 added missing connection and capacitor, finished routing
    [sk556-audiopreamp.brd, sk556-audiopreamp.sch]
2015-05-24 added subcarrier oscillator study
    [ampli.brd, ampli.sch, subcarrier-proto.brd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]
2015-05-24 updated values, small fixes
    [subcarrier-proto.brd, subcarrier-proto.sch]
2016-01-04 corrected date on pcb
    [sk800-rgb.brd]
2016-01-05 changed footprint of transfo, added 100p anti-oscillation capas
    [sk590-audio-inject.brd, sk590-audio-inject.sch]
2016-01-06 fixed power supply connector was reversed
    [sk590-audio-inject.brd, sk590-audio-inject.sch]
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2016-01-08 added second version of subcarrier proto, and synkie eagle lib
    [subcarrier-proto2.brd, subcarrier-proto2.sch]
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2016-02-06 moved sync connector ôut of way of banana plug
    [sk800-rgb.brd]
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2017-08-04 only listen to every other color burst because of alternating phase
    [sk165-3x3-matrix-mixer.brd, sk280-lp5mhz.sch, sk810-subcarrier.brd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]
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2018-03-20 sk181-clipper: replaced buffer op amps and diodes with transistors
    [sk181-clipper.brd, sk181-clipper.sch]
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2018-05-02 fix airwire
    [sk166-4x4-matrix-mixer.brd, sk166-ctl-bus.brd, sk166-ctl-bus.sch]
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2018-05-11 increased matrix mixer feedback resistances to avoid ringing
    [sk166-4x4-matrix-mixer.brd, sk166-4x4-matrix-mixer.sch]
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2018-09-09 mcugen: added pull-downs for outputs, switched supply pins on programming connector
    [sk510-mcugen.brd, sk510-mcugen.sch]
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2018-10-10 correct date
    [sk108-scabi-log.brd, sk166-ctl-bus.brd, sk166-ctl-bus.sch]
2018-10-30 correct resistor values)
    [sk160-6channel-mixer.brd, sk160-6channel-mixer.sch]
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2019-11-12 modified BAT54S symbol to remove weird pin standing out
    [sk108-scabi-log.kicad_pcb, sk108-scabi-log.sch]
2019-11-12 added default power and signal in sections to synkie module template
    [synkie-module.sch]
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2019-11-14 added sk161-modular-mixer; NOTE: board needs to be corrected to adapt to corrected slider pot footprint!
    [dimensioning.ods, sk161-modular-mixer.kicad_pcb, sk161-modular-mixer.sch]
2019-11-14 fixed symbols / footprints references in sk034-allpass
    [sk034-allpass.kicad_pcb, sk034-allpass.sch]
2019-11-15 added footprint and maximum module board size to template
    [synkie-module.kicad_pcb, synkie-module.sch]
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2019-11-15 corrected footprint of ferrite beads
    [sk161-modular-mixer-master.kicad_pcb, sk161-modular-mixer-master.sch]
2019-11-15 fixed black level correction
    [sk161-modular-mixer-master.kicad_pcb, sk161-modular-mixer-master.sch]
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2019-11-18 mixer modules ready for fabrication. allpass with dual-pot
    [sk034-allpass.kicad_pcb, sk034-allpass.sch, sk161-modular-mixer-channel.kicad_pcb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]
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2019-12-08 modular mixer: updated values for better gain ranges
    [sk161-modular-mixer-channel.kicad_pcb, sk161-modular-mixer-channel.sch, sk161-modular-mixer-master.kicad_pcb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]
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2020-08-20 fixed symbols for PMBT3906 were referencing rescue library
    [sk108-scabi-log.sch]
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2020-09-28 change globals to valatile to prevent crashes. make version for pragramming throuigh Arduino IDE
    [sk910-firmware.ino]
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2020-10-18 first version 4fach compa mit fix levels für die stufen 0-1V
    [SK115-4fachmodul_c.kicad_pcb, SK115-4fachmodul_c.sch, sk182-clipper.sch]
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2021-09-24 new resyncer based on anymix21 output. simply named sk003-output from now on
    [sk002-output.kicad_pcb, sk002-output.sch, sk002-resync.sch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]
2021-09-24 add genlock in module. this is the new sync-splitter
    [sk001-genlock-in.kicad_pcb, sk001-genlock-in.sch, sk255-moog.kicad_pcb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]
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2021-09-24 fix sheet link
    [sk003-output.sch, sk003-resync.sch]
2021-09-29 correct polarity
    [b000-power.sch]
2021-10-02 correct pot polarity
    [sk245-oscar-cv-in.sch]
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2021-10-31 add missing 75Ohm termination on input
    [sk006-masterfader-B_Fab.dxf, sk006-masterfader.kicad_pcb, sk006-masterfader.sch]
2021-11-02 add missing jtag vzarget
    [sk612-analog.sch, sk612-controller.sch, sk612-delay.sch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]
2021-11-14 delay does not work. will change to fpga
    [sk612-analog.sch, sk612-delay.kicad_pcb]
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2021-11-23 add missing pulldown. change r1206 to 0805
    [sk001-genlock-in.sch]
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2021-12-04 correct footprints. more gain on subcarrier
    [sk001-genlock-in.kicad_pcb, sk001-genlock-in.sch, sk002-input-clamp.kicad_pcb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]
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2021-12-21 sk108-scabi-log: fixed op amp inputs were reversed since 2020-12-13 (commit 16a4c41fa6f06a2b7dd2fa5efc88025a5135e06a)
    [sk108-scabi-log.kicad_pcb, sk108-scabi-log.sch]
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2021-12-21 added fp-lib-table and sym-lib-table to gitignore, fixed bom ignore
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2021-12-22 missing capacitor
    [sk800-rgb.kicad_pcb, sk800-rgb.sch]
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2022-01-01 improve return paths in pcb. stacking order should be F,B,In2,In1
    [sk108-scabi-log.kicad_pcb, sk108-scabi-log.sch]
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2022-05-26 sk502-vco: added reset, tuned component values
    [sk502-vco.sch]
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2023-04-08 added sk509-noise
    [sk509-noise.kicad_pcb, sk509-noise.sch]
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2024-08-26 sk509-noise: added comments on things to try on schema
    [sk509-noise.sch]
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2024-08-27 updated sk509-noise for new experimental board; component values set so that circuit corresponds to previous prototype
    [sk509-noise.kicad_pcb, sk509-noise.kicad_sch, sk509-noise.sch]
2024-08-27 sk509-noise: added notes about experimental board to schematic
    [sk509-noise.kicad_sch]
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2024-08-27 updated schema to match final version; board needs re-routing!
    [sk509-noise.kicad_sch]
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2025-10-30 sk162: corrected value of output gain resistor
    [mixer-channel.kicad_sch]
2025-10-30 sk110: fixed bias pot low connection, fixed oscillation on bias op-amp
    [sk110-cvadd.kicad_sch]
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2025-10-30 corrected pin name on 4053 symbol
2025-10-30 sk110: use 4053 for invert switches
    [channel.kicad_sch, sk110-cvadd.kicad_sch]
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2025-11-24 sk162: updated schema according to first prototype: adapted output gain to 470/220, fixed termination of unused CFAs
    [mixer-channel.kicad_sch, sk162-herd-mixer.kicad_sch]
2025-11-24 updated pcb for schema fixes
    [sk162-herd-mixer.kicad_pcb]
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2025-11-25 sk110: added croco hole, fixed: cfa termination, power connector orientation
    [channel.kicad_sch, sk110-cvadd.kicad_pcb, sk110-cvadd.kicad_sch]
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2026-03-26 fix pot direction, schottkys
    [sk053-audio2cv.kicad_pcb, sk053-audio2cv.kicad_sch]
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2026-03-26 fix poti direction, supply
    [sk050-triple-lfo.kicad_pcb]
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2026-04-02 fix silkscreen, polarity
    [sk107-comparator.kicad_pcb, sk107-comparator.kicad_sch]
2026-04-14 fix outputs, silk
    [sk107-comparator.kicad_pcb, sk119-boolean.kicad_pcb]
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2026-04-15 fix r values
    [sk040-3x2mux.kicad_sch]
2026-05-13 fix output resistors, footprints, add picoblade
    [sk107-comparator.kicad_pcb, sk107-comparator.kicad_sch]
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2026-05-16 cleanup before redesign
    [sk801-rgb.kicad_pcb, sk801-rgb.kicad_sch, sk801-rgb.sch]
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2026-06-17 add matrix mixer, rdc503, failed version
    [Inputs_Trigger_Dual_Compa.kicad_sch, Power-KK-Picoblade-combined.kicad_sch, Power-MolexKK.kicad_sch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]
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2026-08-25 add notes, how to fix clipping
    [sk101-inAndOut.kicad_sch]
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2026-08-30 change clipper input to 0 - 0.7V, filter out resync switching spikes. buffer bus genlock seperately
    [sk101-clamp.kicad_sch, sk101-inAndOut.kicad_sch, sk101-resync.kicad_sch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]
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2026-09-01 fix flipper levels. switch lo lm833. add 4fsc phase shift
    [connector-big-bus-v2.kicad_sch, sk101-inAndOut.kicad_pcb, sk101-inAndOut.kicad_sch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]
2026-09-01 fixed unconnected + entry in inverting op amp
    [sk105-poor-man-scabi.kicad_sch]
2026-09-01 sk532: increased r106 to fix strange ramp undershoot issue
    [sk532-verticals.kicad_pcb, sk532-verticals.kicad_sch]
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2026-09-14 sch: fix led, fix 4fsc, brd: silk
    [sk002-input-clamp.kicad_sch, sk010-backplane.kicad_pcb, sk053-audio2cv.kicad_pcb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]
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2026-10-06 fix led, drive internal and external SiffNOTSync signal seperately
    [sk101-inAndOut.kicad_pcb, sk101-inAndOut.kicad_sch, sk101_syncsignals.kicad_sch]
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2026-10-08 try to remove oscillations by removing ground plane. new power conn
    [Input_Trigger_Solo_Fast.kicad_sch, sk105-poor-man-scabi.kicad_pcb, sk128-divide.kicad_sch]
2026-10-09 fix errors, route for jlc
    [sk101-inAndOut.kicad_pcb]
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

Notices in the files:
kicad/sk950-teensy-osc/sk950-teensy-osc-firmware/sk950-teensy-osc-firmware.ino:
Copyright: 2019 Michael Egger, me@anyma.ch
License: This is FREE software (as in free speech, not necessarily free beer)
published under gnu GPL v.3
